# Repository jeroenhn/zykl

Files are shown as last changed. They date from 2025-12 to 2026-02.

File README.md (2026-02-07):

# ReZyklus Project

## A clone of the Zyklus MPS-1

The **ReZyklus Project** is an open-source effort to recreate the original **Zyklus MPS-1**.

This repository contains everything required to build your own Zyklus MPS-1 clone, aptly named 'ReZyklus', including hardware design files, panel layouts, and supporting documentation.

See my blog for some more info on the project:
https://www.zyklus-mps.com

There is a Discord server you can join specifically for this project:
https://discord.gg/zFuuCRRDz4

This is also the place where we think and talk about a succesor, the V2 which is mainly carried by David Perbal and will be a system based on the Teensy platform most likely. 

So what is the Zyklus MPS-1? 
A Midi Performance System. It's more than just a sequencer, it's kinda like an 80's version of a launchpad. 
There's really no better way to understand than to have one of the original developers show it to you, so check out Pete Kellocks video demo's of the Zyklus:
https://zyklus-mps.com/videos

Shout out to the team:

Paul McMurray (Technical genius who did most of the actual cloning work)

Marcel Donné (Tester/builder who build one of the first clones)

David Perbal (Another tester/builder who build two of 'm and is carrying the V2 project for the succesor of the ReZyklus - a Teensy based modern implementation)

Panu Talus (Zyklus enthausiast who for years has accumulated all sorts of historical information on the various units. Owner of an original)

And I'm Jeroen (Vangelis gear nut, founder of this project, also owns 2 originals and is restoring Vangelis orignal 'Direct' system).

---

## What’s in this repository

- **Bill of Materials (BOM)**  
  Detailed BOM spreadsheets provide a complete shopping list for the build.

- **PCB & Panel Design Files**  
  All PCB designs and front-panel files are provided.  
  The boards and panels were manufactured using **JLCPCB**, noting that their minimum order quantity is typically **5 units per board or panel**.

- **Case Parts**  
  Some enclosure components are **3D-printed**.  
  The required STL files are included in the repository.

- **Aluminium Dials**  
  Custom aluminium dials were also produced through **JLCPCB**, a working stepfile is included. The Case Parts also contain a file for a 3d printed version. 
  The alu dials need the threads tapped for M4 grub screws. 
  
- **Resource Links**  

  To come: links to various shops for parts, such as the PB86 type switches etc. 

---

## Firmware / OS Status

The original Zyklus operating system is still being worked on. Once ready for publication, it will be added here. The codebase is z80 Assembly and written in a very specific, old assembler which you'll need to compile and link. 

In the meantime, prebuilt EPROM binary files are provided, allowing you to build a fully functional Zyklus clone today while development continues.

---

## Credits & Acknowledgements

### Original Zyklus MPS-1 (1986)

The original Zyklus MPS-1 was created in 1986 by:

- Bill Marshall  
- Pete Kellock  
- Graham Mair  

Bill Marshall and Pete Kellock have generously given their blessing for this clone project to be released as open source.

---

### ReZyklus Project — Primary Contribution

It cannot be overstated that the vast majority of the work on this project has been carried out by Paul McMurray.

This includes, but is not limited to:

- KiCad schematics and PCB layouts  
- Panel designs & lauouts 
- 3D-printed parts  
- Electronics debugging  

Without Paul’s expertise, dedication, and deep understanding of both the original and modern electronics, this project simply would not exist.

Paul McMurray is the MVP of this project and instrumental in helping restoring Direct as well.

---

## Disclaimer

This project is a community-driven, non-commercial recreation intended for educational, historical, and personal use.  
All trademarks and original design concepts remain the property of their respective owners.

## License & Disclaimer

### License

This project is open source and open hardware.

* **Software (firmware, tools, scripts, source code):**
  Licensed under the **GNU General Public License version 3 (GPLv3)** or later.
  You are free to use, modify, and redistribute this software under the terms of the GPL, provided that any distributed modifications remain under the same license.

* **Hardware (schematics, PCB layouts, Gerbers, BOM, and related design files):**
  Licensed under an open hardware copyleft license
  (either **CERN Open Hardware License Version 2 – Strongly Reciprocal (CERN-OHL-S)** *or* **TAPR Open Hardware License**).
  You may use, study, modify, and manufacture hardware based on these designs, provided that any distributed modifications or derivative works are made available under the same license.

The intent of this licensing is to ensure that improvements to this project remain available to the community and cannot be taken proprietary.

THIS PROJECT IS PROVIDED “AS IS”, WITHOUT WARRANTY OF ANY KIND, EXPRESS OR IMPLIED, INCLUDING BUT NOT LIMITED TO MERCHANTABILITY, FITNESS FOR A PARTICULAR PURPOSE, AND NONINFRINGEMENT.

The authors and contributors are not liable for any direct, indirect, incidental, or consequential damages arising from the use, modification, manufacture, or distribution of this hardware or software.

This project is intended for educational, experimental, and research purposes. Use in safety-critical systems (including but not limited to medical devices, life-support systems, or any system where failure could cause injury or death) is expressly discouraged and done entirely at your own risk.

By using, modifying, or manufacturing from this project, you agree that all responsibility for compliance with local laws, regulations, certifications, and safety requirements rests solely with you.

---

### Commercial Use

Commercial use is permitted **only under the terms of the applicable licenses**. Any distributed modifications, derivatives, or products based on this project must remain open and must provide access to corresponding source code and hardware design files under the same license terms.

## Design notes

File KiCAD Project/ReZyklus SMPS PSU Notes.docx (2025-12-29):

ReZyklus SMPS PSU - 01/01/2024 v1.0

This power supply for the ReZyklus is based on a XPower LCW15 Series Switched Mode Power Supply unit which outputs 5V at up to 3 Amps; this output is fed into a DC-DC adjustable boost converter module set to output 5.6V.

The SMPS module can accept a wide range of line voltages between 85 – 305 VAC and the 5V output is adjustable by ±10%. The datasheet can be found here:

https://www.xppower.com/product/LCW15-Series

For this PCB, the input voltage is on CON201 which is a 6-pin Molex KK396 connector. This is wired to be compatible with the original Zyklus PSU. The original unit has a line voltage selector switch, but this SMPS will automatically adjust to a wide range of input voltages, so should operate independently of the how the switch is set. The pinout for input connector is shown below:

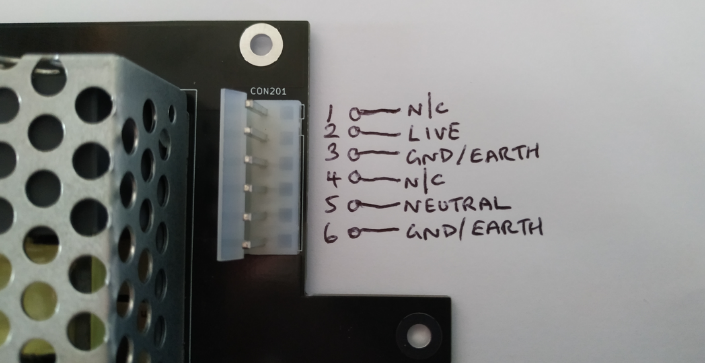
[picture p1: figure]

The output voltages are available on connectors CON202 and CON203 which are both 4-pin Molex KK396 connectors; both have the same pinout with +5V, +5.6V (5V6) and 0V (Gnd); one pin on each connector is unused. The pinout for the output connectors is shown on the PCB.

Fuse

There is a 2A fuse on the PCB for the 5V output of the SMPS module (the 5.6V rail is tapped off the 5V line so is also protected by this fuse); this can be replaced with a T2A fuse (time-lag). The line input should also be protected by a fuse (not on this PCB) and a T1A is recommended; note that the SMPS module has a high inrush current on powering on, so a time-lag fuse is required.

Important - Calibration

Before connecting the unit to a ReZyklus board, check the 5V line with a multimeter and, if required, adjust the white trim pot on the SMPS module (see the Vadjust marking on the PCB) to get this close to (but not below) 5V. After doing this, check the +5.6V line and adjust the blue multi-turn trim pot to get this as close to (but not below) 5.6V.

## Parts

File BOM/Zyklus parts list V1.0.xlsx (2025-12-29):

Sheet: Shopping List
IC's |  |  | Resistors |  |  | Capacitors |  | Diodes
Z80a |  |  | 330 Ohms 5% | 2 |  | 220uf / 16v | 2 | 1N4001 | 23
z80a sio-2 | 2x |  | 220 Ohms 5% | 14 |  | 100uf / 6.3v | 1 | oA47 | 3
z80a ctc |  |  | 1k Ohms 5% | 7 |  | 1u/10/100 | 1 | 1N4148 | 42
z80a pio |  |  | 680 Ohms 5% | 1 |  | 1000pF | 3 | 1N5339b | 1
27c128 | 2x |  | 27k Ohms 5% | 3 |  | 220nK63 | 1 | 1N5339 | 1
27c64 |  |  | 3.3k Ohms 5% | 2 |  | 100pF | 1 | 1N5401 | 4
HM6264LP-15 | 5x |  | 39k Ohms 5% | 2 |  | 10uf / 50v | 2
2730 | 2x | (one unused) | 100 Ohms 5% | 3 |  | 1u0 / 16v | 1
tl062cp | 2x |  | 22k Ohms 5% | 3 |  | 10,000pF | 26
7660 |  |  | 470 Ohms 5% | 3 |  | 0.047 uF | 16
74ls138n | 4x |  | 4.7k Ohms 5% | 32 |  | 10n | 11
74ls32n | 2x |  | 10k Ohms 5% | 3 |  | 220u 16v | 1
74ls74an | 5x |  | 56k Ohms 5% | 1 |  | 4700u 16V | 3
74ls393n |  |  | 2.2k Ohms 1% | 1 |  | 47n | 2
74ls244 | 7x |  | 270 Ohms 5% | 31 |  | 1u 16V | 1
74ls02n | 2x |  | 33 Ohms 5% 2W | 1
74ls04n |  |  | 560 Ohms 5% | 1
74ls245 |  |  | 33k Ohms 5% | 2
74ls123n |  |  | 220k | 1
74ls21n
74s74an | 2x
74ls00n
74ls374n | 5x
Connectors |  |  | Misc Components
26 way IDC | 2 |  | Battery | 2
10 way Molex | 3 |  | Crystal 4mhz | 1
34 Way Molex | 2 |  | TS 1N6267 | 2
4way molex | 3 |  | RV 10K | 1 | Optional
6way Molex | 1 |  | RV 500r | 1 | Optional
 |  |  | Alps LA226 | 1
Jack ports | 8 |  | Buzzer | 1
Midi ports | 5 |  | Red LED | 1
Power socket | 1 |  | Switch W/o Led | 8 | Black
 |  |  | Switch W led | 12 | Blue
 |  |  | Switch W led | 19 | Grey
 |  |  | Switch W/o Led | 1 | Grey
 |  |  | TS201 / 250V | 1
 |  |  | Regulatr L78S05 | 1
 |  |  | F201 Fuse 2A | 1
 |  |  | Transformer | 1
 |  |  | Outside Fuse | 1
 |  |  | Voltage Selector | 1

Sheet: IC
Mainboard |  | Switchboard |  | PS Board
Z Number |  | Z Number |  | Z Number
z1 | z80a cpu | z101 | 74ls138n
z2 | z80a sio-2 | z102 | 74ls138n
z3 | z80a sio-2 | z103 | 74ls74an
z4 | z80a ctc | z104 | 74ls374n
z5 | z80a pio | z105 | 74ls374n
z6 | rom | z106 | 74ls374n
z7 | rom | z107 | 74ls374n
z8 | rom | z108 | 74ls244
z9 | HM6264LP-15 | z109 | 74ls244
z10 | HM6264LP-15 | z110 | 74ls02n
z11 | HM6264LP-15 | z111 | 74ls374n
z12 | HM6264LP-15 | z112
z13 | HM6264LP-15 | z113
z14 | 2730 | z114
z15 | tl062cp | z115
z16 | tl062cp | z116
z17 | 7660 | z117
z18 | 74ls138n
z19 | 74ls138n
z20 | 74ls32n
z21 | 74ls74an
z22 | 74ls74an
z23 | 74ls74an
z24 | 74ls393n
z25 | 74ls244
z26 | 74ls244
z27 | 74ls244
z28 | 74ls244
z29 | 74ls244
z30 | 74ls32n
z31 | 74ls02n
z32 | 74ls04n
z33 | 74ls245
z34 | 74ls123n
z35 | 74ls21n
z36 | 74s74an
z37 | 74ls00n
z38 | 2730

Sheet: Resistors
Mainboard |  | Switchboard |  |  | PS Board
R Number | Value | R Number | Value |  | R Number | Value
r1 | 330 Ohms 5% | r101 | 270 Ohms 5% |  | R201 | 1k Ohms 5%
r2 | 330 Ohms 5% | r102 | 270 Ohms 5% |  | R202 | 33 Ohms 5% 2W
r3 | 33k Ohms 5% | r103 | 270 Ohms 5%
r4 | 560 Ohms 5% | r104 | 270 Ohms 5%
r5 | 220 Ohms 5% | r105 | 270 Ohms 5%
r6 | 220 Ohms 5% | r106 | 270 Ohms 5%
r7 | 220 Ohms 5% | r107 | 270 Ohms 5%
r8 | 220 Ohms 5% | r108 | 270 Ohms 5%
r9 | 220 Ohms 5% | r109 | 270 Ohms 5%
r10 | 220 Ohms 5% | r110 | 270 Ohms 5%
r11 | 220 Ohms 5% | r111 | 270 Ohms 5%
r12 | 220 Ohms 5% | r112 | 270 Ohms 5%
r13 | 220 Ohms 5% | r113 | 270 Ohms 5%
r14 | 1k Ohms 5% | r114 | 270 Ohms 5%
r15 | 680 Ohms 5% | r115 | 270 Ohms 5%
r16 | 27k Ohms 5% | r116 | 270 Ohms 5%
r17 | 1k Ohms 5% | r117 | 270 Ohms 5%
r18 | 1k Ohms 5% | r118 | 270 Ohms 5%
r19 | 1k Ohms 5% | r119 | 270 Ohms 5%
r20 | 1k Ohms 5% | r120 | 270 Ohms 5%
r21 | 3.3k Ohms 5% | r121 | 270 Ohms 5%
r22 | 1k Ohms 5% | r122 | 270 Ohms 5%
r23 | 39k Ohms 5% | r123 | 270 Ohms 5%
r24 | 39k Ohms 5% | r124 | 270 Ohms 5%
r25 | 27k Ohms 5% | r125 | 270 Ohms 5%
r26 | 33k Ohms 5% | r126 | 270 Ohms 5%
r27 | 27k Ohms 5% | r127 | 270 Ohms 5%
r28 | 33k Ohms 5% | r128 | 270 Ohms 5%
r29 | 100 Ohms 5% | r129 | 4.7k Ohms 5%
r30 | 100 Ohms 5% | r130 | 4.7k Ohms 5%
r31 | 100 Ohms 5% | r131 | 4.7k Ohms 5%
r32 | 22k Ohms 5% | r132 | 4.7k Ohms 5%
r33 | 22k Ohms 5% | r133 | 4.7k Ohms 5%
r34 | 22k Ohms 5% | r134 | 4.7k Ohms 5%
r35 | 470 Ohms 5% | r135 | 4.7k Ohms 5%
r36 | 470 Ohms 5% | r136 | 4.7k Ohms 5%
r37 | 470 Ohms 5% | r137 | 4.7k Ohms 5%
r38 |  | r138 | 4.7k Ohms 5% | other side board
r39 | 4.7k Ohms 5% | r139 | 4.7k Ohms 5% | other side board
r40 | 4.7k Ohms 5% | r140 | - | unused
r41 | 4.7k Ohms 5% | r141 | 270 Ohms 5%
r42 | 4.7k Ohms 5% | r142 | 270 Ohms 5%
r43 | 4.7k Ohms 5% | r143
r44 | 4.7k Ohms 5% | r144 | 270 Ohms 5%
r45 | 4.7k Ohms 5%
r46 | 4.7k Ohms 5%
r47 | 4.7k Ohms 5%
r48 | 4.7k Ohms 5%
r49 | 4.7k Ohms 5%
r50 | 4.7k Ohms 5%
r51 | 4.7k Ohms 5%
r52 | 4.7k Ohms 5%
r53 | 4.7k Ohms 5%
r54 | 4.7k Ohms 5%
r55 | 4.7k Ohms 5%
r56 | 4.7k Ohms 5%
r57 | 4.7k Ohms 5%
r58 | 4.7k Ohms 5%
r59 | 4.7k Ohms 5%
r60 | 10k Ohms 5%
r61 | 220k Ohms 5%
r62 | 56k Ohms 5%
r63 | 2.2k Ohms 1%
r64 | 10k Ohms 1%
r65 | 220 Ohms 5%
r66 | 220 Ohms 5%
r67 | 220 Ohms 5%
r68 | 220 Ohms 5%
r69 | 220 Ohms 5%

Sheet: Diodes
Mainboard |  | Switchboard |  | PS Board
D Number | Value | D Number | Value | D Number | Value
D1 | 1N4001 | d101 | 1N4148 | D201 | 1N5401
D2 | 1N4001 | d102 | 1N4148 | D202 | 1N5401
D3 | oA47 | d103 | 1N4148 | D203 | 1N5401
D4 | 1N4001 | d104 | 1N4148 | D204 | 1N5401
D5 | 1N4001 | d105 | 1N4148 | D205 | 1n4001
D6 | 1N4001 | d106 | 1N4148
D7 | 1N4001 | d107 | 1N4148 | Zen 201 | 1N5339
D8 | 1N4001 | d108 | 1N4148
D9 | 1N4001 | d109 | 1N4148
D10 | 1N4001 | d110 | 1N4148
D11 | 1N4001 | d111 | 1N4148
D12 | 1N4001 | d112 | 1N4148
D13 | 1N4001 | d113 | 1N4148
D14 | 1N4001 | d114 | 1N4148
D15 | 1N4001 | d115 | 1N4148
D16 | 1N4001 | d116 | 1N4148
D17 | 1N4001 | d117 | 1N4148
D18 | 1N4001 | d118 | 1N4148
D19 | 1N4001 | d119 | 1N4148
D20 | 1N4001 | d120 | 1N4148
D21 | 1N4001 | d121 | 1N4148
D22 | oA47 | d122 | 1N4148
D23 | oA47 | d123 | 1N4148
D24 | 1N4148 | d124 | 1N4148
D25 | 1N4148 | d125 | 1N4148
D26 | 1N4148 | d126 | 1N4148
D27 | 1N4001 | d127 | 1N4148
D28 | 1N4001 | d128 | 1N4148
D29 | 1N4001 | d129 | 1N4148
D30 |  | d130 | 1N4148
D31 |  | d131 | 1N4148
D32 |  | d132 | 1N4148
D33 |  | d133 | 1N4148
D34 |  | d134 | 1N4148
D35 |  | d135 | 1N4148
D36 |  | d136 | 1N4148
D37 |  | d137 | 1N4148
D38 |  | d138 | 1N4148
D39 |  | d139 | 1N4148
D40 |  | zen 101 | 1N5339b
D41
D42
D43
D44
D45
D46
D47
D48

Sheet: Capacitors
Mainboard |  |  | Switchboard |  |  | PS Board
C Number | Value |  | C Number | Value |  | C Number | Value
c1 | 220uf / 16v | EL | c101 | 10n |  | C201 | 4700u 16V
c2 | 220uf / 16v | EL | c102 | 10n |  | C202 | 4700u 16V
c3 | 100uf / 6.3v | EL | c103 | 10n |  | C203 | 4700u 16V
c4 | 1u/10/100 | Philips | c104 | 10n |  | C204 | 47n
c5 | 1000pF |  | c105 | 10n |  | C205 | 47n
c6 | 220nK63 |  | c106 | 10n |  | C206 | 1u 16V
c7 | 1000pF |  | c107 | 10n
c8 | 1000pF |  | c108 | 10n
c9 | 100pF |  | c109 | 10n
c10 | 10uf / 50v | EL | c110 | 10n
c11 | 10uf / 50v | EL | c111 | 220u 16v | el
c12 | 1u0 / 16v | Tantalum | c112
c13 | 10,000pF | Cer | c113 | 10n
c14 | 10,000pF | Cer
c15 | 10,000pF | Cer
c16 | 10,000pF | Cer
c17 | 10,000pF | Cer
c18 | 10,000pF | Cer
c19 | 10,000pF | Cer
c20 | 10,000pF | Cer
c21 | 10,000pF | Cer
c22 | 10,000pF | Cer
c23 | 10,000pF | Cer
c24 | 10,000pF | Cer
c25 | 10,000pF | Cer
c26 | 10,000pF | Cer
c27 | 10,000pF | Cer
c28 | 10,000pF | Cer
c29 | 10,000pF | Cer
c30 | 10,000pF | Cer
c31 | 10,000pF | Cer
c32 | 10,000pF | Cer
c33 | 10,000pF | Cer
c34 | 10,000pF | Cer
c35 | 10,000pF | Cer
c36 | 0.047 uF | Cer
c37 | 0.047 uF | Cer
c38 | 0.047 uF | Cer
c39 | 0.047 uF | Cer
c40 | 0.047 uF | Cer
c41 | 0.047 uF | Cer
c42 | 0.047 uF | Cer
c43 | 0.047 uF | Cer
c44 | 0.047 uF | Cer
c45 | 0.047 uF | Cer
c46 | 0.047 uF | Cer
c47 | 0.047 uF | Cer
c48 | 0.047 uF | Cer
c49 | 0.047 uF | Cer
c50 | 0.047 uF | Cer
c51 | 0.047 uF | Cer
c52 | 10,000pF | Cer
c53 | 10,000pF | Cer
c54 | 10,000pF | Cer

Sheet: Misc Components
Mainboard |  | Switchboard |  |  | PS Board
C Number | Value | C Number | Value |  | C Number | Value
B1 | Battery | enc 101 | Alps LA226 Rotary encode |  | TS201 | 250V
B2 | Battery | bz 101 | Buzzer |  | Reg201 | L78S05
Crystal | 4Mhz | Display | OLED 40x2 |  | F201 | Fuse 2A
TS1 | 1N6267 | sw101 | Switch W Led | Gray | Xfomrer | Avel Lindberg OB 30/9
TS2 | 1N6267 | sw102 | Switch W Led | Gray
RV1 | 10K | sw103 | Switch W Led | Gray
RV2 | 500R | sw104 | Switch W Led | Gray
 |  | sw105 | Switch w/o Led | black
 |  | sw106 | Switch w/o Led | black
 |  | sw107 | Switch w/o Led | black
 |  | sw108 | Switch w/o Led | black
 |  | sw109 | Switch w/o Led | black
 |  | sw110 | Switch w/o Led | black
 |  | sw111 | Switch w/o Led | black
 |  | sw112 | Switch w/o Led | black
 |  | sw113 | Switch W Led | Gray
 |  | sw114 | Switch W Led | Gray
 |  | sw115 | Switch W Led | Gray
 |  | sw116 | Switch W Led | Gray
 |  | sw117 | Switch W Led | Gray
 |  | sw118 | Switch W Led | Gray
 |  | sw119 | Switch W Led | Gray
 |  | sw120 | Switch W Led | Gray
 |  | sw121 | Switch W Led | Gray
 |  | sw122 | Switch W Led | Gray
 |  | sw123 | Switch W Led | Gray
 |  | sw124 | Switch W Led | Gray
 |  | sw125 | Switch w/o Led | Gray
 |  | sw126 | Switch W Led | Blue
 |  | sw127 | Switch W Led | Blue
 |  | sw128 | Switch W Led | Blue
 |  | sw129 | Switch W Led | Blue
 |  | sw130 | Switch W Led | Blue
 |  | sw131 | Switch W Led | Blue
 |  | sw132 | Switch W Led | Blue
 |  | sw133 | Switch W Led | Blue
 |  | sw134 | Switch W Led | Blue
 |  | sw135 | Switch W Led | Blue
 |  | sw136 | Switch W Led | Blue
 |  | sw137 | Switch W Led | Blue
 |  | sw138 | Switch W Led | Gray
 |  | sw139 | Switch W Led | Gray
 |  | sw140 | Switch W Led | Gray
 |  | Led 101 | LED Red

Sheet: Connectors
Mainboard |  |  | Switchboard |  | PS Board
C Number | Value |  | C Number | Value | C Number | Value
P1 | 26 way IDC | To switchboard | p101 | 26 way idc | S203 | 4 way Molex
P2 |  |  | p102 | 4way molex | S201 | 6way Molex
P3 | 4 way Molex | Power
P4 | 10 way Molex | To Jack ports
P5 | 34 Way Molex | To Cardridge
P6 | 10 way Molex | To Midi
P7 | 10 way Molex | To Midi

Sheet: Shopping links
Q | Z nr | Code | Item | Dip | Mainboard
5x | 9,10,11,12,13 | HM6264LP-15 | SRAM | 28 | Static ram 8Kx8 CMOS, PDIP-28 | These are also used in the memory module.
2x | 7,8 | 27128 | EProm | 28
1x | 6 | 2764 | EProm | 28
1x | 1 | Z80a | CPU | 40 | https://www.budgetronics.eu/nl/ics/microcontrollers/z80a-cpu/a-10778-10000143
1x |  | LA226 | Encoder |  | http://store.drawmer.com/index.php?route=product/product&product_id=147
1x | 33 | LS245 |  |  | https://www.budgetronics.eu/en/ics/7400-serie-ics/74ls-series/74ls245-octal-bus-transceiver-tri-state-dip20/a-20916-20000100
4x | 26,29 (28?),27 | LS244 |  | 20 | https://www.budgetronics.eu/en/ics/7400-serie-ics/74ls-series/74ls244-octal-buffer-line-driver/a-17957-20000100
1x | 19 | LS138 |  |  | https://www.budgetronics.eu/en/ics/7400-serie-ics/74ls-series/74ls138-3-line-to-8-line-decoders-demultiplexer/a-17870-20000100
4x | 21,36,22,23 | LS74 |  |  | https://www.budgetronics.eu/en/ics/7400-serie-ics/74ls-series/74ls74-dual-d-type-positive-edge-triggered-flip-flops/a-17832-20000100
1x | 18 | LS136 |  |  | https://www.budgetronics.eu/en/ics/7400-serie-ics/74ls-series/74ls136-quad-exclusive-or-gate-o-c/a-21210-20000100
2x | 18,20 | LS138 |  |  | https://www.budgetronics.eu/en/ics/7400-serie-ics/74ls-series/74ls138-3-line-to-8-line-decoders-demultiplexer/a-17870-20000100
2x | 2,3 | Z80 A SIO-2 IC • DIP-40 |  | 40
1x | 32 | LS04 |  |  | https://www.budgetronics.eu/en/ics/7400-serie-ics/74ls-series/74ls04-hex-inverter-dip14/a-18245-20000100
2x | 14,38 | 2730 |  |  | https://www.conrad.nl/nl/p/broadcom-optocoupler-fototransistor-hcpl-2730-000e-dip-8-darlington-dc-140137.html
1x | 24 | LS393 |  |  | https://www.budgetronics.eu/en/ics/7400-serie-ics/74ls-series/74ls393-dual-4-bit-binary-counter/a-20548-20000100
1x | 4 | Z80A CTC |  | 28 | https://www.futurlec.com/Z80Series/Z80A-CTCpr.shtml
1x | 5 | Z80A PIO |  | 40 | https://www.ebay.com/itm/Sharp-LH0081A-Z80A-PIO-Z80A-PIO-D-/152356548738
1x | 17 | 7660 |  |  | Z80 A SIO-2 IC • DIP-40
1x | 34 | LS123 |  |  | https://www.budgetronics.eu/en/ics/7400-serie-ics/74ls-series/74ls123-dual-retriggerable-one-shot/a-17833-20000100
Q | Z nr | Code | Item |  | Switch board
2x | z1, z2 | LS138 |  |  | https://www.budgetronics.eu/en/ics/7400-serie-ics/74ls-series/74ls138-3-line-to-8-line-decoders-demultiplexer/a-17870-20000100
1x | z3 | LS74 |  |  | https://www.budgetronics.eu/en/ics/7400-serie-ics/74ls-series/74ls74-dual-d-type-positive-edge-triggered-flip-flops/a-17832-20000100
5x | z4,z5,z6,z7,z11 | LS374 |  |  | https://www.budgetronics.eu/en/ics/7400-serie-ics/74ls-series/74ls374-octal-d-type-flip-flop-edge-triggered-tri-state/a-20886-20000100
2x | z8,z9 | LS244 |  | 20 | https://www.budgetronics.eu/en/ics/7400-serie-ics/74ls-series/74ls244-octal-buffer-line-driver/a-17957-20000100
1x | z10 | LS02 |  |  | https://vetco.net/products/nte74ls02-ic-ttl-nor-gate
Capacitors
3x | 4700 uF 16v | Elco
3x | 220uF 16V | Elco
2x | 10uF 50v | Elco
1x | 100uF 6.3V | Elco

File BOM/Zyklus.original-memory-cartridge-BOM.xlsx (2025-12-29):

Zyklus memory cartridge – BOM
Ref | Qty |  | Footprint
R305,R302,R304,R303,R301,R306 | 6 | 4.7M Ohms
Z301,Z302,Z303,Z304 | 4 | HM6264LP-15 | DIP-28_W15.24mm_Socket_LongPads
C303,C302,C304,C301 | 4 | 100nF poly
B302,B301 | 2 | 3V | Half-AA-Cell-Holder
C300 | 1 | 10uF 16V
D303,D302,D301 | 3 | 1N4001
S301 | 1 | 37w D-SUB Female | DSUB-37_Female_Horizontal_P2.77x2.84mm_EdgePinOffset7.70mm_Housed_MountingHolesOffset9.12mm
ZEN301 | 1 | Zener 5w 5v6 - do27

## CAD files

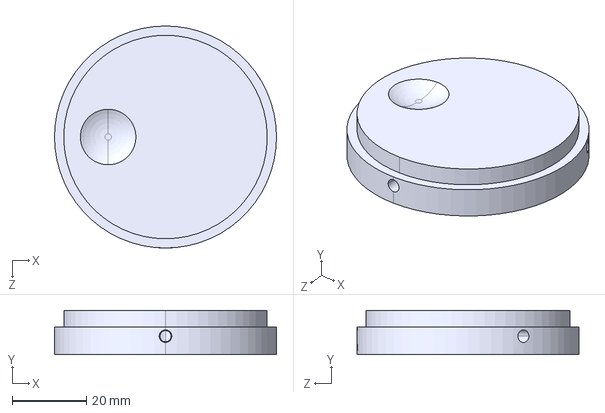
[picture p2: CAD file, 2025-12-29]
Alu Dial/Knob03.STEP
60.0 x 12.0 x 60.0 mm

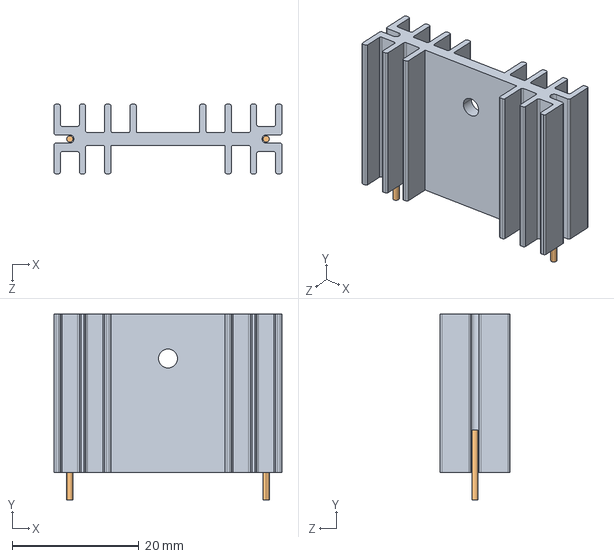
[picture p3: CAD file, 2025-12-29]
KiCAD Project/Additional Libraries/User Defined/DISIPADOR_TO220_5P.STEP
36.0 x 29.3 x 11.0 mm
disipador
pin x 2

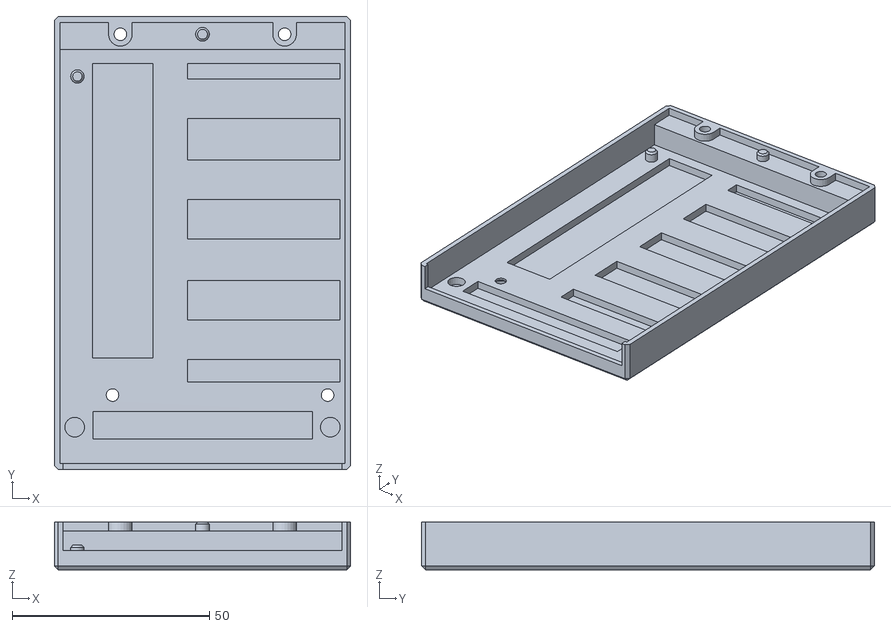
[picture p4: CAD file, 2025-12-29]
ReZyklus Cartridge Case/v1.0/ReZyklus Cartridge Case Bottom.stl
75.1 x 114.8 x 12.1

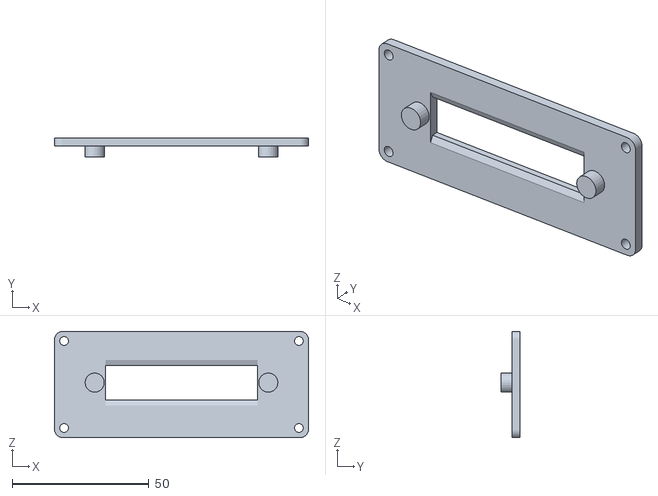
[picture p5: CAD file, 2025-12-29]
ReZyklus Case/ReZyklus DIY case (white panels)/STLs/ReZyklus DIY Case - Cartridge Connector Plate.stl
92.9 x 7.00 x 38.8

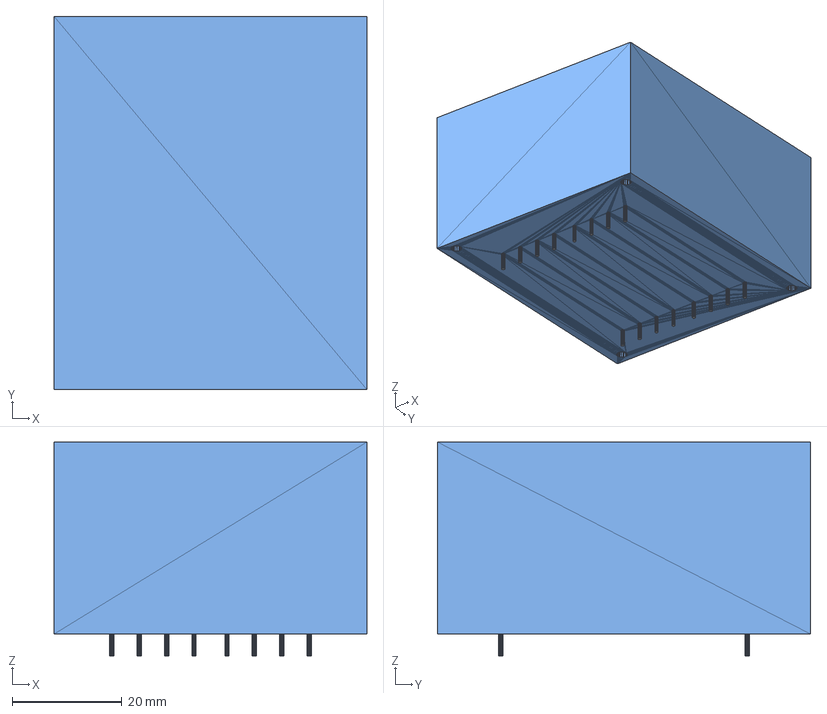
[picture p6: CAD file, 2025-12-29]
KiCAD Project/Additional Libraries/3D Models/Myrra 45xxx Transformer.stp
57.0 x 68.0 x 39.0 mm
pina
pinb
pinc
pind
pine
pinf
ping
pinh
pini
pinj
pink
pinl
pinm
pinn
pino
pinp

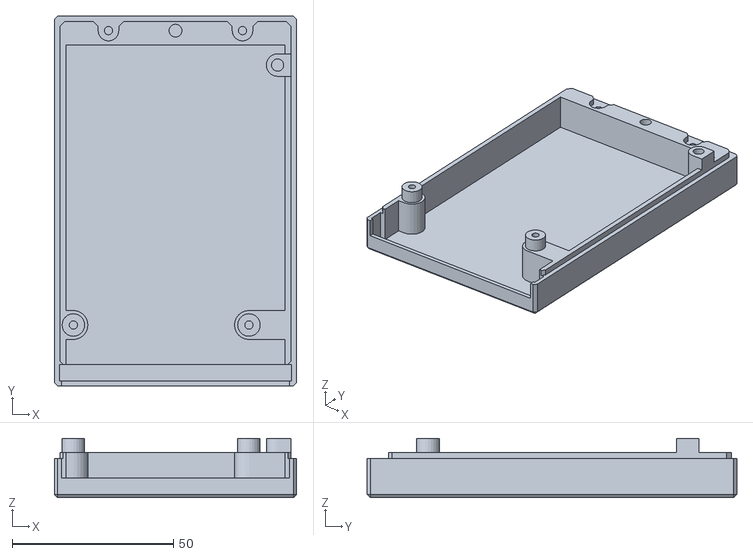
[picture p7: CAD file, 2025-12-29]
ReZyklus Cartridge Case/v1.0/ReZyklus Cartridge Case Top.stl
75.1 x 114.8 x 18.5

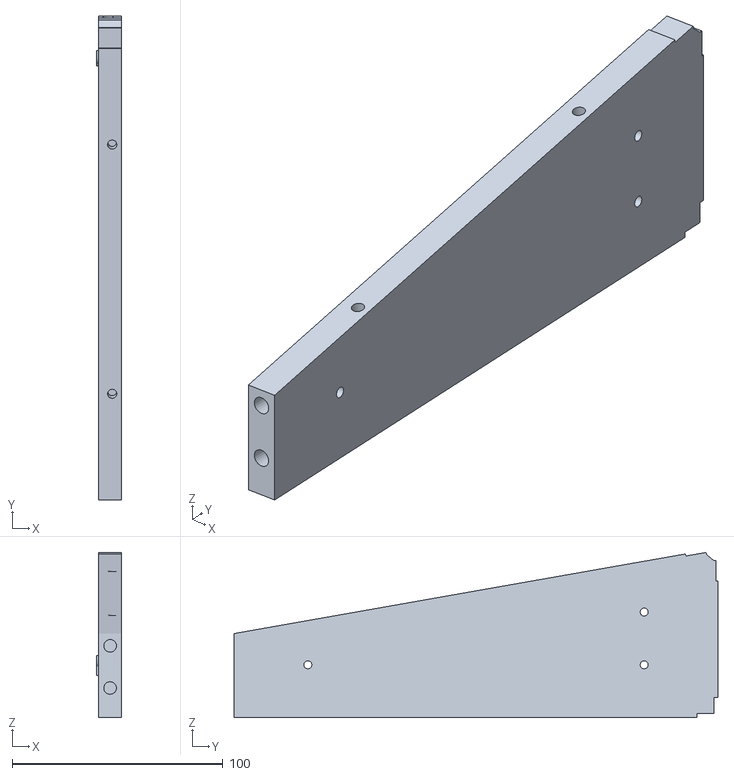
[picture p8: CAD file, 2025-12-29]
ReZyklus Case/ReZyklus DIY case (white panels)/STLs/ReZyklus DIY Case - Right Side.stl
12.1 x 229.5 x 78.3

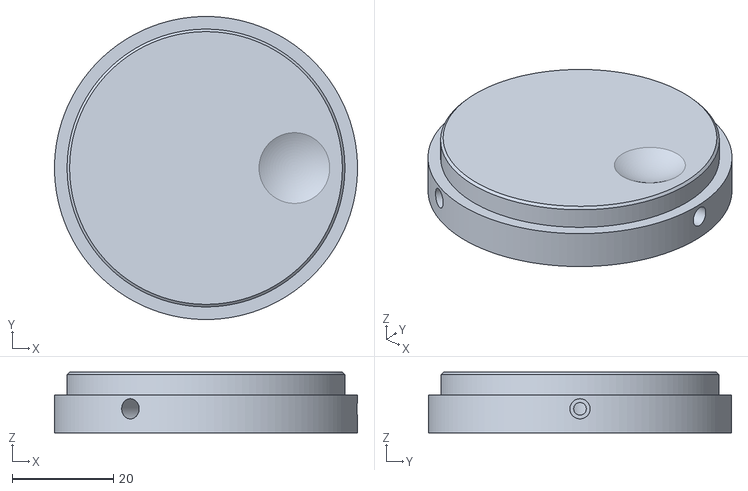
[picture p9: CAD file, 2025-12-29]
ReZyklus Case/ReZyklus DIY case (white panels)/STLs/ReZyklus DIY Case - Encoder Wheel.stl
60.0 x 60.0 x 12.0

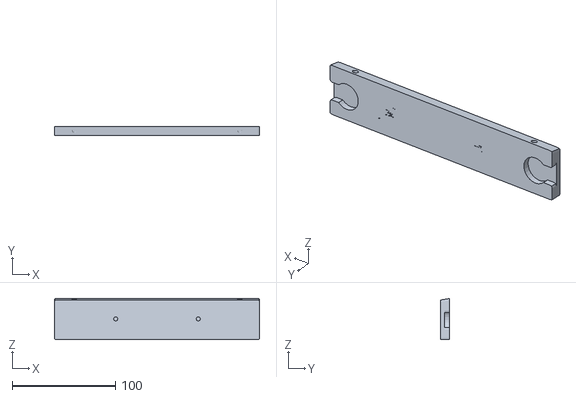
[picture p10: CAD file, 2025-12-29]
ReZyklus Case/ReZyklus DIY case (white panels)/STLs/ReZyklus DIY Case - Center Front.stl
198.6 x 9.00 x 39.8

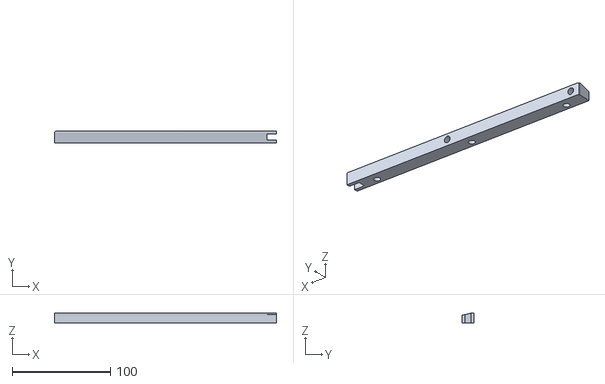
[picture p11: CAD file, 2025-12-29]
ReZyklus Case/ReZyklus DIY case (white panels)/STLs/ReZyklus DIY Case - Left Rear Mount.stl
225.5 x 12.5 x 10.5

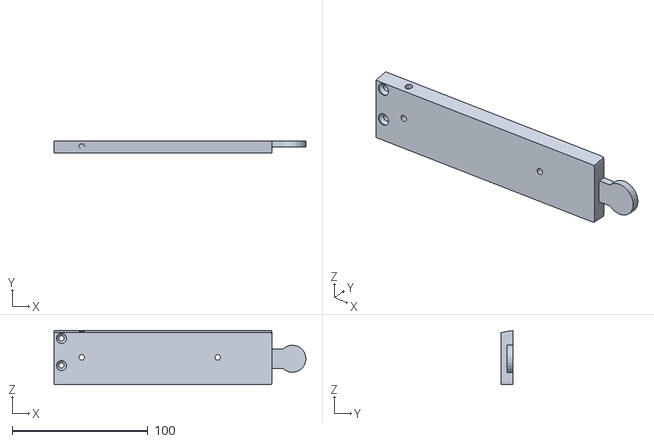
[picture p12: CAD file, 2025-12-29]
ReZyklus Case/ReZyklus DIY case (white panels)/STLs/ReZyklus DIY Case - Left Front.stl
185.4 x 9.00 x 39.8

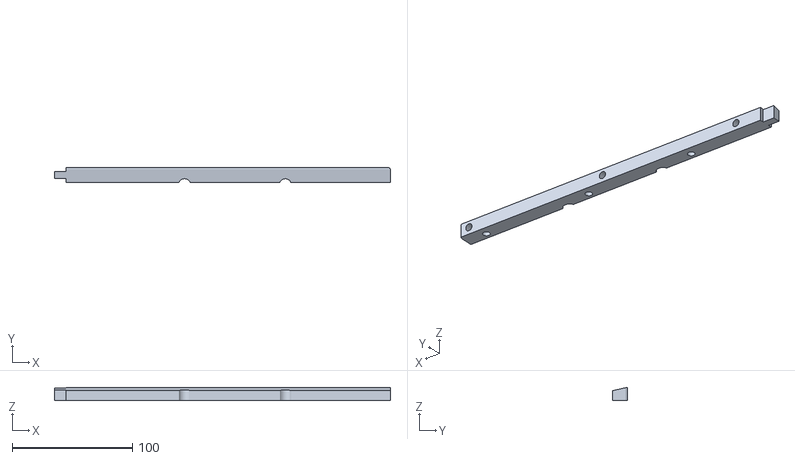
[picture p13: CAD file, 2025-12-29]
ReZyklus Case/ReZyklus DIY case (white panels)/STLs/ReZyklus DIY Case - Right Rear Mount.stl
279.5 x 12.5 x 10.5

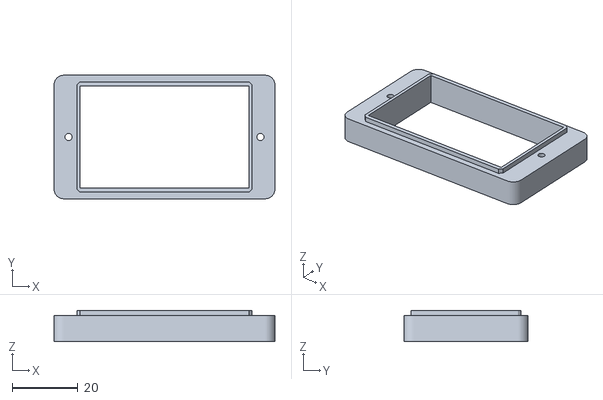
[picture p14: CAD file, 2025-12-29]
ReZyklus Case/ReZyklus DIY case (white panels)/STLs/ReZyklus DIY Case - Bulgin IEC Inlet Mount.stl
67.4 x 37.7 x 9.50

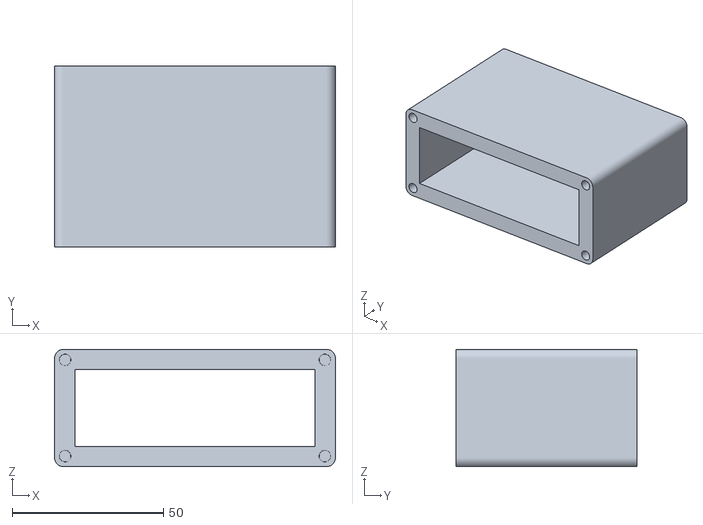
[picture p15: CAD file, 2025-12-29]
ReZyklus Case/ReZyklus DIY case (white panels)/STLs/ReZyklus DIY Case - Cartridge Slot.stl
92.9 x 60.0 x 38.8

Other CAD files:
ReZyklus Case/ReZyklus DIY case (white panels)/STLs/ReZyklus DIY Case - Left Side.stl
ReZyklus Case/ReZyklus DIY case (white panels)/STLs/ReZyklus DIY Case - Right Front.stl
KiCAD Project/Additional Libraries/3D Models/MC33270 Heatsink.stp
KiCAD Project/Additional Libraries/Molex KK 396 3D Models/026192051.stp
KiCAD Project/Additional Libraries/Molex KK 396 3D Models/026192031.stp
KiCAD Project/Additional Libraries/Molex KK 396 3D Models/026192041.stp
KiCAD Project/Additional Libraries/Molex KK 396 3D Models/026192061.stp
KiCAD Project/Additional Libraries/Molex KK 396 3D Models/026192071.stp
KiCAD Project/Additional Libraries/Molex KK 396 3D Models/026192081.stp
KiCAD Project/Additional Libraries/Molex KK 396 3D Models/026192091.stp
KiCAD Project/Additional Libraries/Molex KK 396 3D Models/026192101.stp
KiCAD Project/Additional Libraries/Molex KK 396 3D Models/026192111.stp
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

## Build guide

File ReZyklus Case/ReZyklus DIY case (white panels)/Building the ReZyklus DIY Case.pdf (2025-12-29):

Building the ReZyklus DIY Case

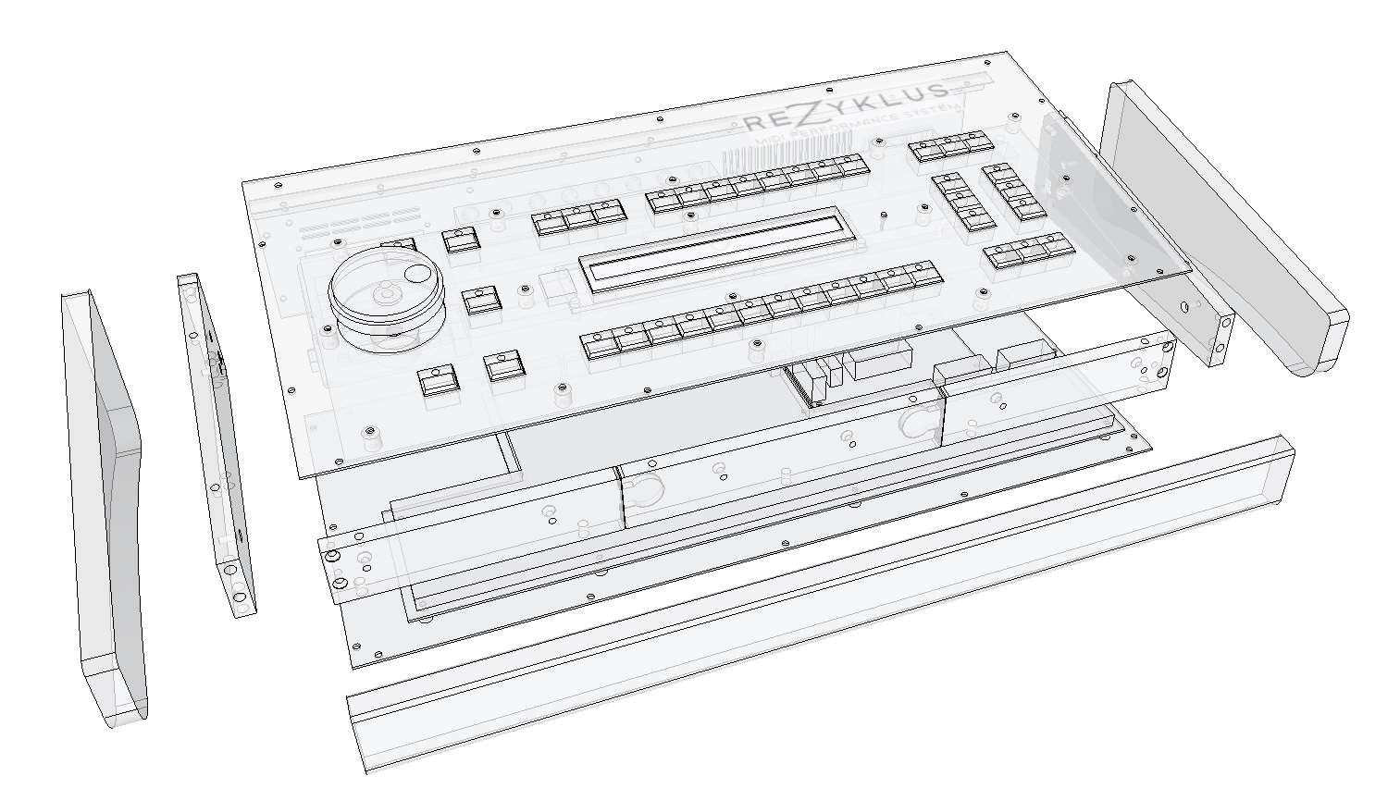
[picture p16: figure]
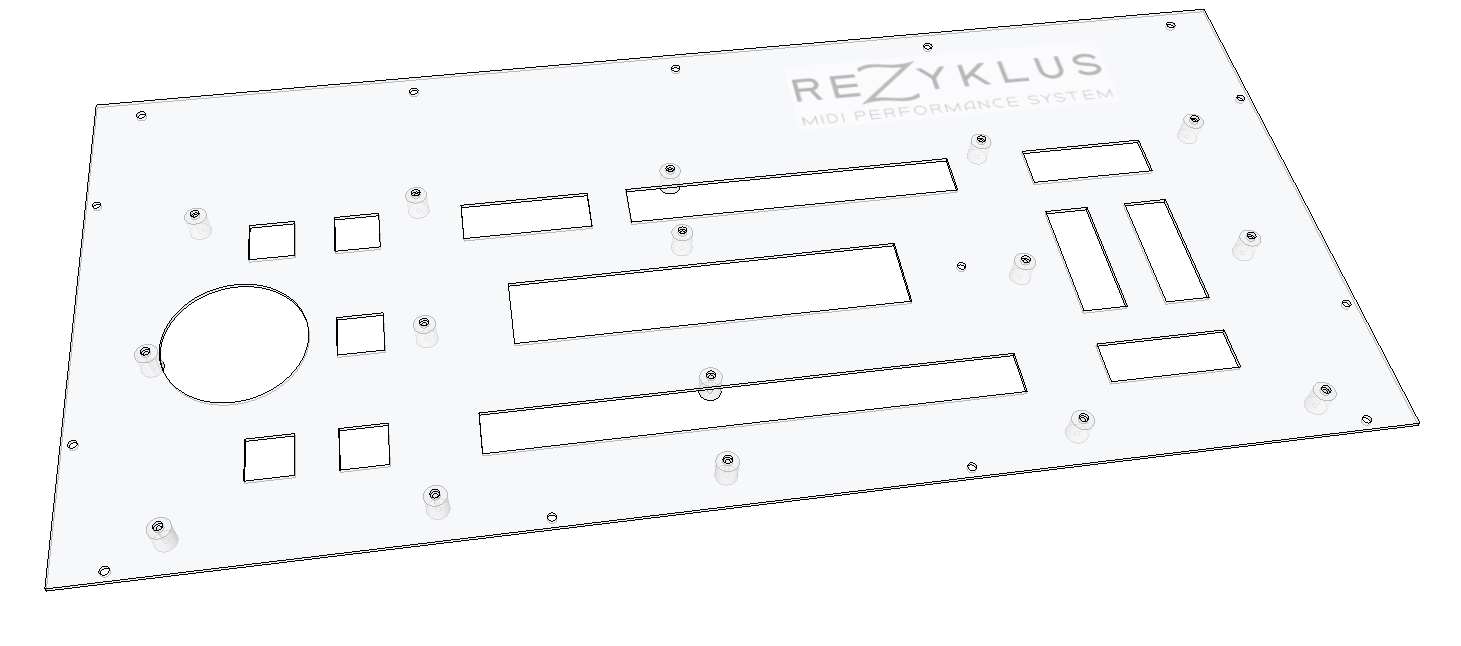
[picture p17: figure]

Building the ReZyklus DIY Case.docx | revision 0.3 | Page 1 of 10

The DIY case for the ReZyklus project is a hybrid of milled & printed aluminium panels (manufactured by JLCPCB), 3D Printed panels (for the sides, front and interconnecting supports) and optionally wooden side and front panels to dress over the 3D printed panels and sharp case edges.

Main Top Panel

The Panelboard PCB mounts to this using:
- 16x M3 10mm Hexagonal threaded spacers (this size leaves just enough clearance for the LCD)
- 16x M3 6mm button-head Hex bolts (recommended as these are visible on the top panel and smooth to the touch)
- 16x M3 5mm general purpose screws (to secure the PCB to the spacers)

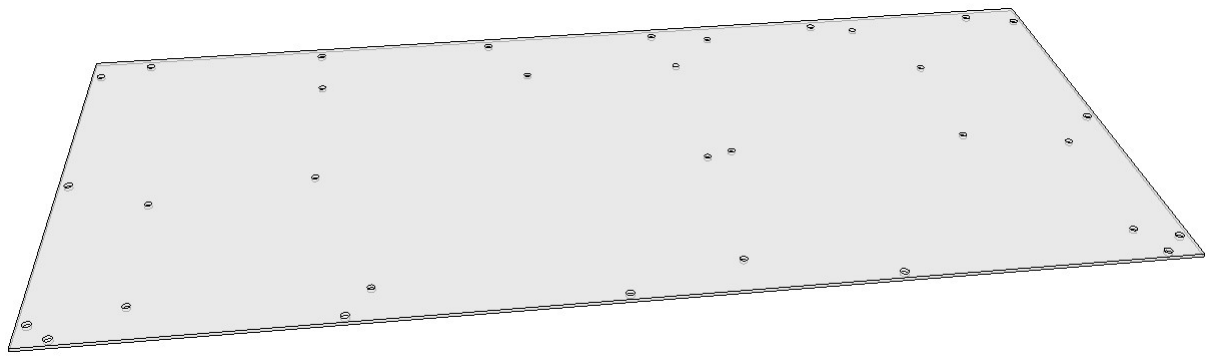
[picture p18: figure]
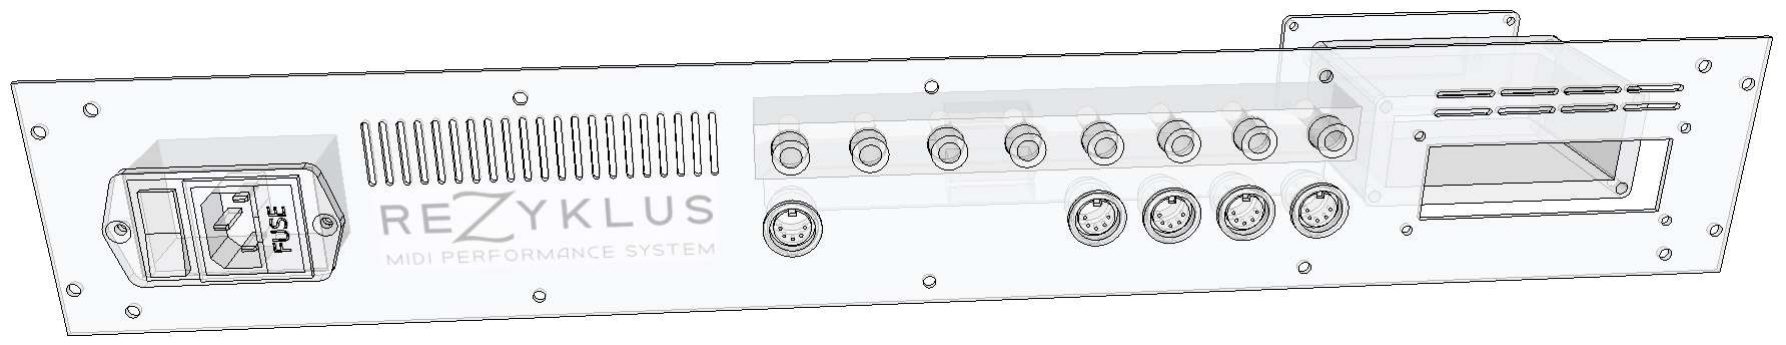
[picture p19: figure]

Building the ReZyklus DIY Case.docx | revision 0.3 | Page 2 of 10

Before fitting the PCB in place, the encoder and Jog Wheel have to be mounted so as to just clear the top of the PCB. Test fit the PCB in place with a couple of screws to check the alignment and if necessary, reposition the encoder pot (may need to file out the mounting hole in the PCB slightly) to get the Jog Wheel central in the panel cut-out.

Base Panel

The Mainboard PCB and PSU PCB mounts to this using:
- 11x M3 8mm Hexagonal threaded spacers for the main board (this size leaves just enough clearance for the underside of the Encoder when the case is closed)
- 5x M3 10mm Hexagonal threaded spacers for the PSU board (this allows it to clear the rear mounting strip on the case)
- 16x M3 6mm button-head Hex bolts (recommended as these are smooth to the touch and lowprofile on the underside of the case)
- 16x M3 5mm general purpose screws (to secure the PCBs to the spacers)

Rear Panel

The MIDI Jacks, Input Jacks, IEC Inlet and Cartridge Port attach to this panel using:
- 2x M3 15mm Countersunk bolts (+ nuts and washers) for mounting the IEC Inlet
- MIDI DIN Sockets – these are mounted to the panel first, before wiring and mounting them to the PCB, as they are mounted from the front of the panel
- Jack Sockets – these can be mounted after soldering to the PCB as they are mounted from the back of the panel
- Cartridge Port – this is a 3D printed part mounted to the case by 4x M3 8mm screws

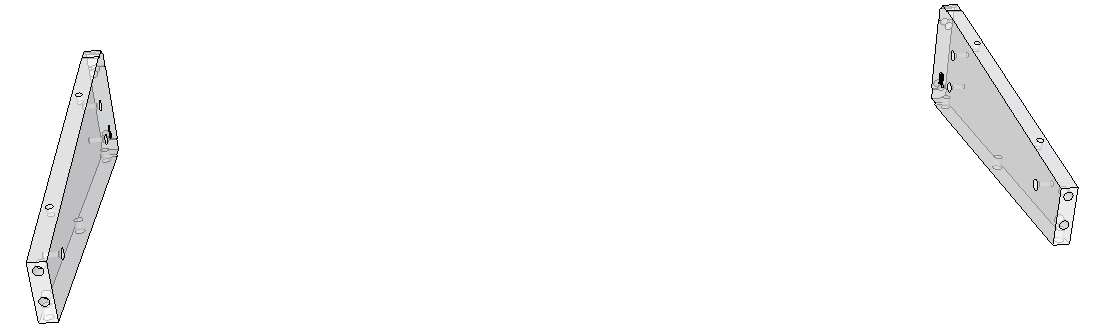
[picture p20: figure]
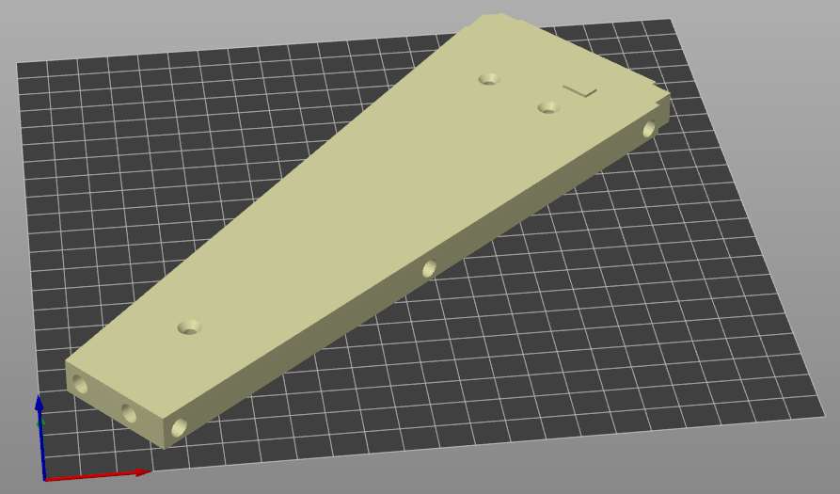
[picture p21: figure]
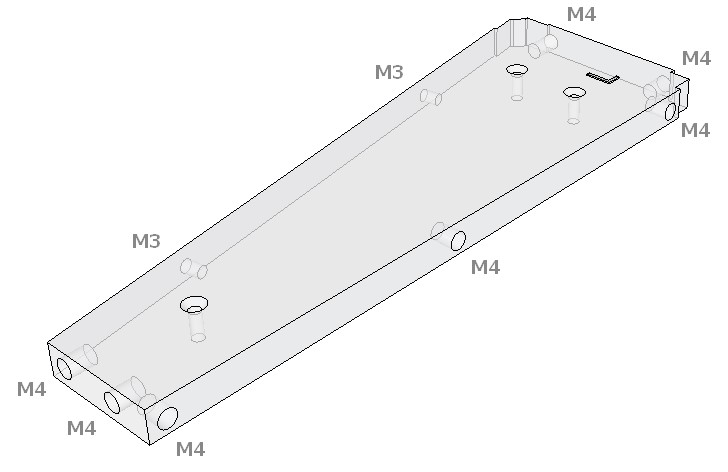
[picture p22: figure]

Building the ReZyklus DIY Case.docx | revision 0.3 | Page 3 of 10

3D Printed Case Parts
Side Panels

The 3D printed side panels form the main structural parts of the case and have been designed to give the top panel a 10° slope, down towards the front of the case. Each one will fit diagonally on a fairly common print bed size of 230mm x 230mm if printed diagonally:

The orientation should be with the raised letters “L” or “R” on the top surface, and the model needs no support material. Recommended Infill density should be somewhere around 10% Gyroid or 25% Cubic so that plenty of material is printed around the holes where the threaded inserts should be fitted after printing. The panel also includes three countersunk holes for screws to go through for mounting the wooden side panels.
Threaded inserts should be melted into place as per the diagram below (flipped accordingly for the righthand panel):

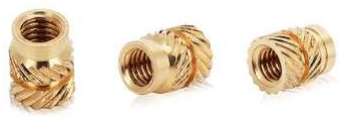
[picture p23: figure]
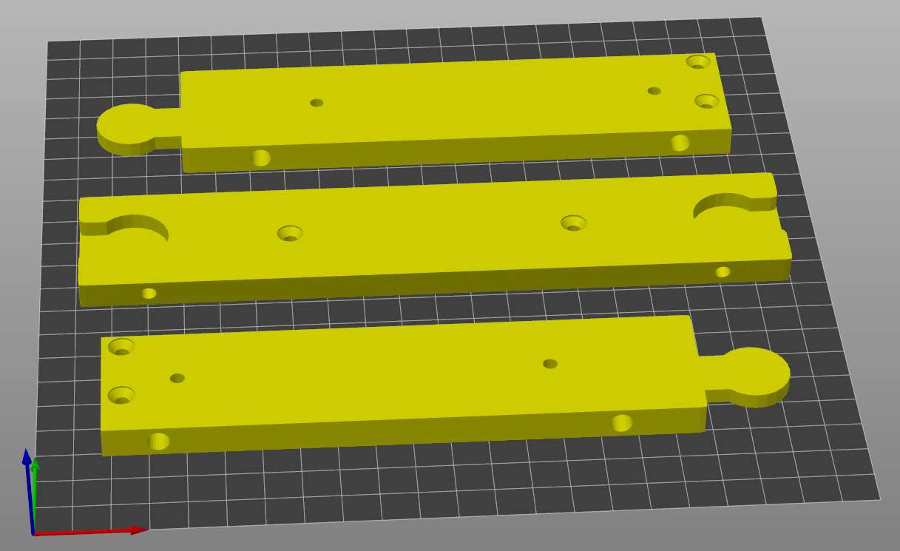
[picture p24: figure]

Building the ReZyklus DIY Case.docx | revision 0.3 | Page 4 of 10

A pair of side panels requires a total of:
- 4x M3 threaded insert
- 14x M4 threaded insert
- 6x countersunk wood screws (length dependent on the chosen thickness of wood used)
If available, the recommended inserts to use are the longer type with a smooth shaft at one end, as these help keep the insert centrally aligned as they are melted into place:

If using a soldering iron to melt the inserts into place, recommend using a conical tip and to set the temperature of the iron to around 220°C. As soon as the insert is in place, thread an M3 bolt into the insert and use it to adjust the inserts alignment and draw the heat out quickly.

Front Panels

The 3D printed front panels form part of the structural parts of the case and have been designed to match the top panel 10° slope. The panel is split into three pieces in order to fit on a standard print bed, however all three can be printed at once.
Note that the Left and Right sections should be printed with the tabs touching the print bed, but the center section oriented with the tab cut-outs on the top surface:

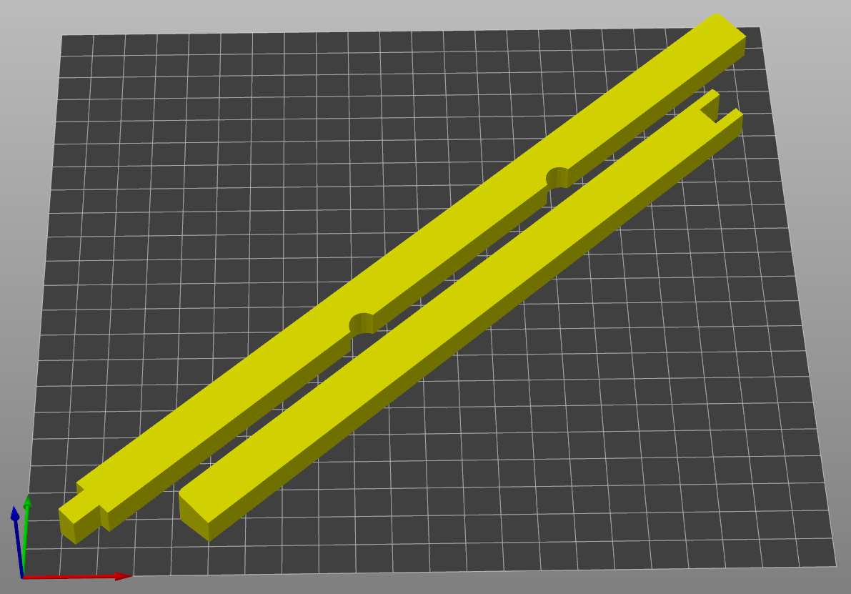
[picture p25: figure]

Building the ReZyklus DIY Case.docx | revision 0.3 | Page 5 of 10

The models need no support material and, as with the other parts, the recommended Infill density should be somewhere around 10% Gyroid or 25% Cubic so that plenty of material is printed around the holes where the threaded inserts should be fitted after printing.
The panels also include six countersunk holes for screws to go through for mounting the wooden front panel. There are also two countersunk holes at each end for securing the front panels to the side panels via 4x M4 12mm Countersunk bolts.
The tabs on the end sections are designed to be glued into place in the center section (an adhesive compatible with the chosen filament is recommended, but CA glue will usually suffice). When doing this, it is recommended to temporarily mount the panels to the base plate so as to ensure the correct spacing and alignment, then “wick” the CA glue around the tabs.
Threaded inserts should be melted into place as per the diagram below:

A set of three front panels requires a total of:
- 4x M3 threaded inserts
- 5x M4 threaded insert
- 4x M4 12mm Countersunk bolts
- 6x countersunk wood screws (length dependent on the chosen thickness of wood used)

Rear to Base Panel Mounting Strip

This part ensures the rear panel and base plate are mounted rigidly to each other. It is split into two sections that can be printed diagonally on a standard print bed:

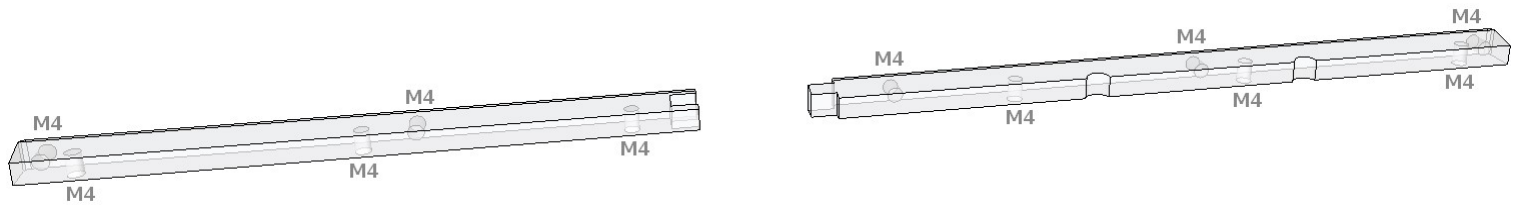
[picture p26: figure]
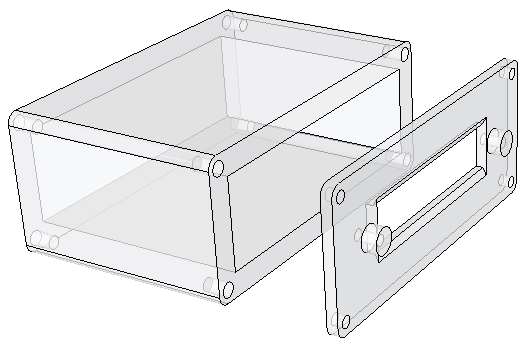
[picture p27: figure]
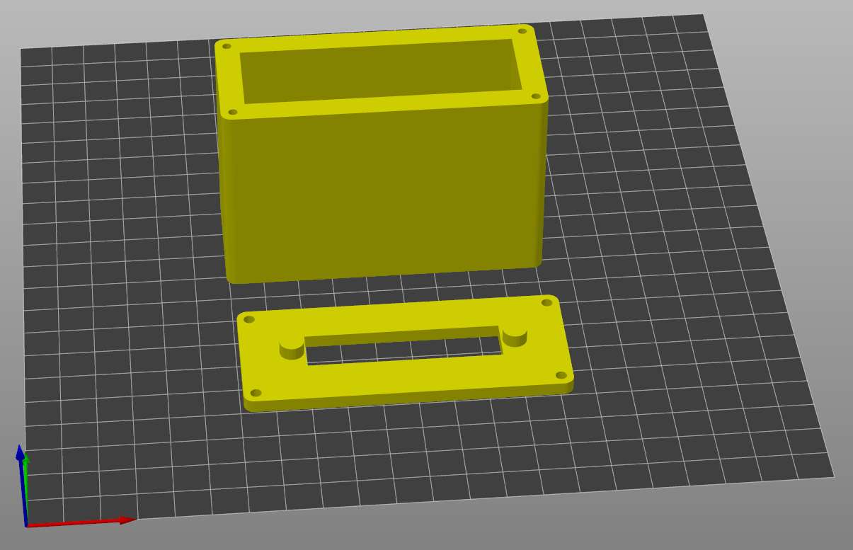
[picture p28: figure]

Building the ReZyklus DIY Case.docx | revision 0.3 | Page 6 of 10

The models should be printed with the insert holes oriented face down onto the build plate. The models need no support material, and the recommended Infill density should be somewhere around 10% Gyroid or 25% Cubic so that plenty of material is printed around the holes where the threaded inserts should be fitted after printing.
The set of two strips require a total of:
- 11x M4 threaded inserts
- 11x M4 6mm button-head Hex bolts (recommended as these are smooth to the touch and lowprofile on the case panels)
Threaded inserts should be melted into place as per the diagram below:

The center parts of the models are designed to fit into each other and can also be glued together if desired, although it is not necessary.

Cartridge Port

This consists of two part that screw together via M3 bolts and M3 threaded inserts:
- The sleeve to guide the cartridge into place
- The connector plate to mount the 37-way Male IDC connector into
Both models fit easily onto a standard build plate. The sleeve should be printed upright, and the connector plate printed flat to the bed:

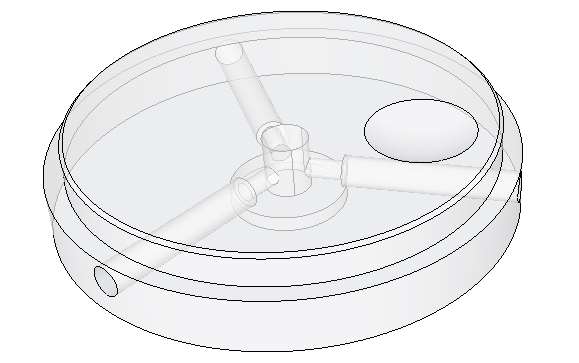
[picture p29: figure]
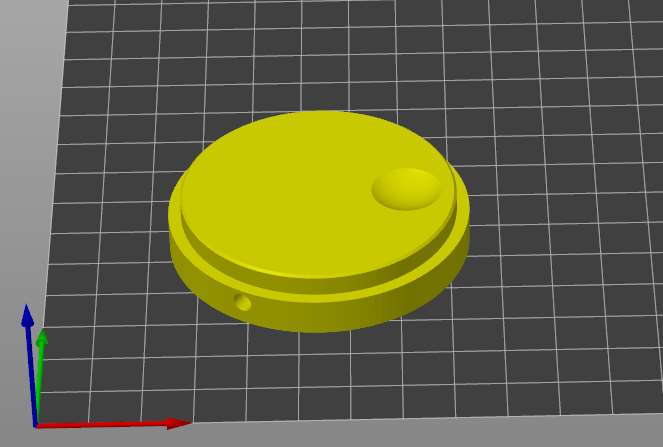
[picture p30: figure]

Building the ReZyklus DIY Case.docx | revision 0.3 | Page 7 of 10

The models need no support material, and the recommended Infill density should be somewhere around 10% Gyroid or 25% Cubic.
The two parts require:
- 8x M3 threaded inserts
- 8x M3 8mm self-tapping screws (4x to attach the connector plate to the sleeve, and 4x to mount the sleeve to the rear panel)
- 2x M3 6-10mm self-tapping screws to mount the connector to the plate; the length of these screws will depend on whether the connector is metal-bodied or plastic-bodied.
The connector should be mounted such that it is on the inside of cartridge port, rather than from the back. (It is easier to first mount the connector to the plate, then mount the whole assembly to the sleeve)

Encoder Jog Wheel

This part is modelled on the original Zyklus MPS aluminium wheel. It needs a little work after printing to drill through and tap the three grub-screw mounts. Print the part oriented as below:

Recommendation is a dense infill (e.g. 20% Gyroid or 50% Cubic), 2 perimeters and at least 4 layers to get a smooth finish on the top. Layer height should be at least 0.20mm, but if the “dimple” in the top is rough, try again with 0.16mm instead. The part will also need support on the base plate for the recessed center section underneath.
After printing, first remove the support material. Carefully drill the three grub screw channels with a 2mm drill bit, through to the center opening where the shaft goes in. The ends of these channels (nearest the center) will then need threading with an M3 tap, after which 3x M3 grub screws will need inserting; use at least 8mm screws to get good alignment and purchase on the threads.
The wheel should fit tightly on the encoder shaft, the grub screws helping with alignment and eliminating any wobble when turning the wheel. It can take some time to get this right, but it is possible.

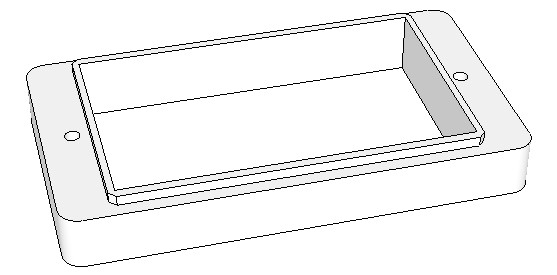
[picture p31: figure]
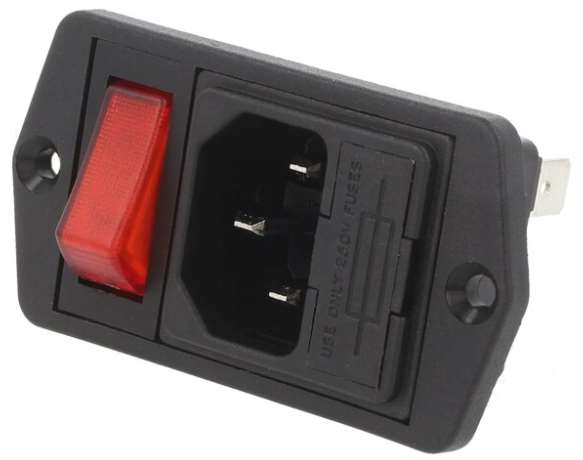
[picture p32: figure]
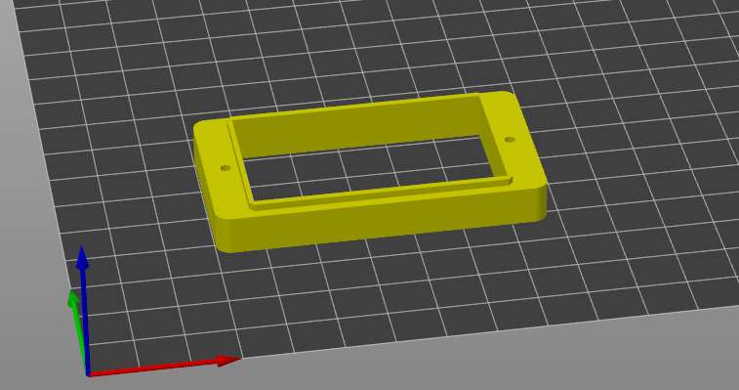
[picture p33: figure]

Building the ReZyklus DIY Case.docx | revision 0.3 | Page 8 of 10

An alternative would be to have this part Resin Printed for a better finish, however it may be necessary to alter the STL model to accommodate the different printing process.

IEC Mains Inlet Mount

This part is intended to act as a “backing plate” for the combination IEC Inlet and Power switch, specifically part: Bulgin BVA01/Z0000/02
- /02 is the suffix for a red neon-lit switch
- /01 is the suffix for a black non-lit switch

However, this part is not supplied as a moulded one-piece design; instead it consists of a power switch and IEC inlet snapped into a plastic bezel and is not particularly well made (despite the brand and price!). It requires some hot glue or epoxy to secure the parts in the mounting bezel.
The part mounts from the front-side of the panel, and the 3D printed backing plate helps with alignment and also provides holes for 2x M3 8mm Self-tapping screws.
The part should be printed flat onto the print bed:

Recommended infill is 20% Gyroid or Rectilinear, just to provide plenty of material around the mounting holes, 2 perimeters and 3 top & bottom layers (pretty standard settings).

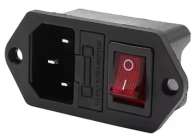
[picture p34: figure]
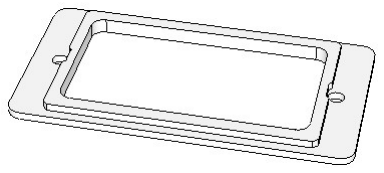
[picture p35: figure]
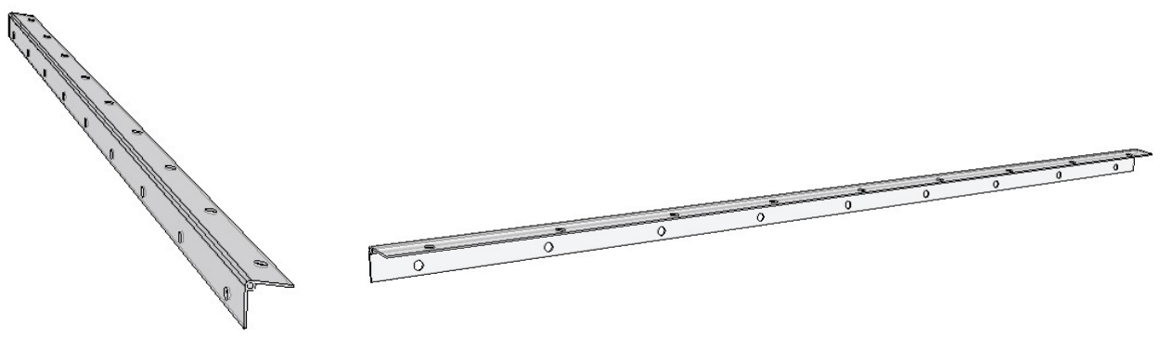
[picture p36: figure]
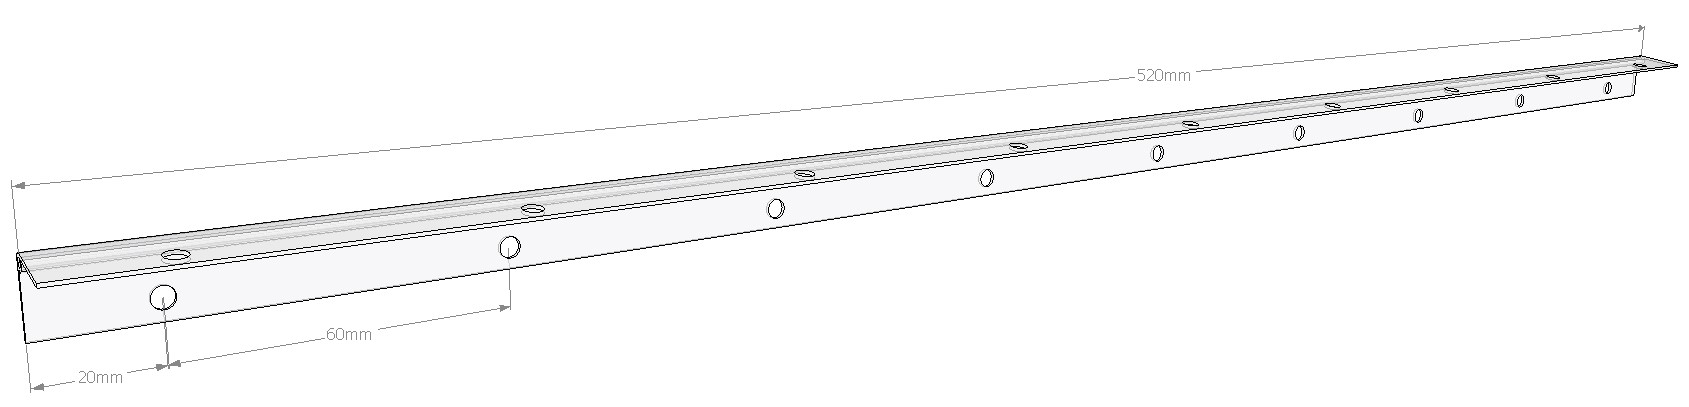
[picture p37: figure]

Building the ReZyklus DIY Case.docx | revision 0.3 | Page 9 of 10

UPDATE: There are better inlets available (AC-01A) which are one-piece designs, however these require a slightly different sized cut-out on the panel. To accommodate these, a 3D printed insert plate has been designed to fill in the gaps around the inlet:

This would be an easy print, flat face down on the print bed with 100% infill.
Note than when fitting this type of inlet, the mounting holes on the case panel would need to be filed into slots to allow for the closer spacing of the mounting holes on this type of inlet.

Hinge Assembly
(shown below in two orientations)

The DIY case was designed with a hinge mounting the top and rear panels together; this provides a neat solution to the 80° angle between the two and allows for easy opening to get inside the unit.
The brass hinge used was obtained from a local hardware store (Wickes in the UK) but seems to be pretty standard in dimensions/hole spacing as those found on sites like Amazon.
It will require cutting to length, probably from both ends to ensure the holes line up with the panel. The cuts should be done with either a rotary tool (e.g. Dremel) cutting disc, or a fine bladed hacksaw. The length and mounting hole spacing should be as shown below:

The hinge is attached on the inside of the two panels using M4 8mm Button-head Hex bolts and suitable nuts & washers (suggest Nyloc type nuts); note that not every hole on the hinge is used.

Building the ReZyklus DIY Case.docx | revision 0.3 | Page 10 of 10

Document Revision History
Date | Version | Notes
13/10/2024 | v0.1 | Initial Draft
14/10/2024 | v0.2 | Minor corrections
11/12/2024 | v0.3 | PSU PCB requires 10mm spacers. Updated some images.

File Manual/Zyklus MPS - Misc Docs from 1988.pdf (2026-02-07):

Here’s some documentation for users that I dug up in ancient files, today, 2011-04-07.

### --Pete

Doc: ‘UN1’ (UN = User Note)

ZYKLUS MIDI PERFORMANCE SYSTEM ------------------------------

Pete Kellock | 3/2/88
| | GETTING STARTED | |

From first taking the machine out of its box, you can be up and running in

5 minutes if you follow the guidelines below. From there on, if you have

difficulties in finding or understanding a feature, refer to the User Guide.

It has an index and a 'Problems Page' for quick reference.

1. Take the MPS out of the box and check that the Voltage Selector on the

back is set to your local voltage.

2. On the back of the MPS, connect the MIDI Input plus MIDI Output A to a synth (or other MIDI gear) as follows:
----------- | MIDI Out | MIDI In | ----------
| | |------------------>--------------------| | |
| | Synth | | | | | MPS | |
| | | | MIDI In | MIDI Out A | | | |
| | |------------------<--------------------| | |
3. On the synth, set the transmit & receive channels to 1.
4. | Plug in the mains and switch on. | Adjust the display brightness &
viewing angle by turning the 2 controls on the base of the unit. | You

should now see the following display:

120 | A1 A1 A1 A1 A1 A1 A1 A1 A1 A1 A1 A1 | (Output A, channel 1)
120 | T | T | T | T | T | T | T | T | T | T | T | T | ('Thru' in all 12 positions)

[ If you don't have the above display, the memory probably isn't blank
so you should format it. | The quick way to do this is to switch off the
machine, hold down blue keys 1, 3 & 5 only, then switch on. | BE VERY
CAREFUL ANY TIME YOU USE THIS FEATURE - IT ERASES THE ENTIRE INTERNAL MEMORY WITHOUT WARNING YOU! ]
5. Press & release the ASSIGN SEQ key (4th black key at top), turn wheel to

right and press the ENTER key to select ASSIGN-12-FREE. You will now

have the following display:

120 | A1 A1 A1 A1 A1 A1 A1 A1 A1 A1 A1 A1 | (Output A, channel 1)
120 | 01 02 03 04 05 06 07 08 09 10 11 12 | (Seqs 1 to 12 assigned)

You now have 12 free sequences and can record on any of them.

6. | Press the REC/EDIT key then Control Key 1 (the 1st blue key). | The

display will change completely - you are now in step-time record on

sequence 1. | Play a few notes near the bottom of the keyboard and you
| will see them appear at the right of the display.
7. | Now record a few notes into sequence 2. | To do this, press REC/EDIT then
Control Key 2 and play in the notes. | Use notes near the top of the

keyboard so that they're clearly distinguishable from sequence 1.

Notice that you're still hearing seq 1 while you're recording seq 2 . If

you don't want this, press Control Key 1 again and it's LED will go off (to

show that you're not monitoring it any more).

8. | Press PLAY then RUN/STOP. | You can now replay your 2 sequences,
triggering and controlling them in hundreds of different ways. | The

current triggering mode depends on the 12 grey keys at the right of the

machine and the STEP key at the left - these 13 keys are known as the

'Trigger Profile' keys.

9. | Start with all 13 Trigger Profile keys off. | Press the blue Control Keys
1 and 2 to hear your sequences. | Switch these keys on & off a few times -

notice how you have independent control over each sequence and that they

each start from the beginning when you activate them.

10. Switch off both sequences, press the EXT TRIG key at the right and
hit Control Key 1 again. | Notice that it now flashes to tell you it's
ready. | Hit a note on the synth and the sequence should be triggered

(if not, check the connections and make sure that the RUN/STOP key is

still on). | Experiment with the following cases:
a) Hit a note on the synth, release it, then hit another. | Note how the
sequence is transposed and re-triggered each time.
b) Hold down a note on the synth, then press another while keeping it held. Note that 2 transpositions of the sequence are now running in parallel and the sequence is not re-triggered till you release all notes and press a new one. You can have up to 8 transpositions running in parallel - ie up to 8 'Control Pitches' for each sequence.
c) Try hitting the synth notes with different touches (hard & soft). If you're using a velocity-sensitive synth with a velocity-sensitive sound you'll hear that the velocity is being controlled from the keyboard.
d) While seq 1 is running, press Control Key No 2. | You can now trigger
seq 2 from the synth keyboard. | Note that whatever Control Pitch(es)
you set for seq 1 are now fixed or 'pitch-locked'. | (Normally a
sequence becomes pitch-locked if it is running when you press the Control Key for another sequence.)
e) You can stop or 'kill' either sequence by pressing its Control Key while it is running. You can then set it ready (flashing) by pressing it again - and so on.
11. Kill both sequences and switch on the STEP key at the left side of the MPS.

You can now single-step through the seqs from the blue Control Keys or

from the synth keyboard (if EXT TRIG is on). Note that if EXT TRIG is off

and you want to kill a sequence, you must release STEP before pressing the

Control Key.

12. Put on the MOM (Momentary) key and experiment with various combinations of

MOM, EXT TRIG and STEP. The effect of the MOM key should soon become

clear.

You have now covered maybe 2% of what the MPS can do, but hopefully you can

begin to see the possibilities for triggering & controlling sequences in

real time - ie PERFORMING the sequences. This is essentially what the MPS

is all about, but many of the possibilities which arise from this basic idea

are surprising. The MPS is as much a 12-channel MIDI effects unit or a

12-channel MIDI control station as it is a sequencer.

To explore forward from this point it is probably best to experiment with

the features introduced above but using more sequences. If you want to

record some sequences in real-time, just hit RUN while in step-time record

mode. | (You should normally start with a free sequence - attempting to play
over an existing sequence causes a punch-in, NOT an overdub.) | You set the
loop point in real-time record mode by hitting ENTER or RUN/STOP. | To start

recording a different sequence you then press another Control Key.

You may find it useful to go straight to User Note 2 at this point - it

gives various tips which will allow you to get on faster.

Doc: ‘UN2’
ZYKLUS MIDI PERFORMANCE SYSTEM ------------------------------
Pete Kellock | 4/2/88
| | MISC TIPS | |

If you're a beginner or near-beginner with the MPS, the following tips may

help:

1. If nothing happens (eg no sequences run) when you press the blue Control

Keys, check the following:

- that you are in Play mode (PLAY is on, REC/EDIT & PERF are off)
- that RUN is on
- that the sequences assigned to the Control Keys have some notes in them. (You can check by going into step-time record mode.)
- this is less likely, but you might have somehow selected EXTERNAL CLOCK. If unsure, press TEMPO and look at the left of the display. If it says EXT CLK you will have to reselect INTERNAL CLOCK under the black GENERAL OPTIONS key.
2. If you have recorded some sequences, are now in Play mode, and your

sequences seem to have mysteriously vanished, you have probably changed

Configuration. To restore your previous Config, press the CONFIG key,

then keep pressing ENTER until you see your original 12 sequence numbers.

3. If you can't switch the Control Keys off in Play mode, you probably have
the STEP Trigger Profile key on. | This is perfectly normal healthy MPS
behaviour. | Switch off STEP and you will be able to switch off the

Control Keys.

4. You cannot go from RECORD to PLAY modes or vice versa when the machine is running. Similarly the 8 black 'Function' keys at the top have no effect

when the machine is running.

5. In step-time record mode you change step size, enter rests, etc by HOLDING

DOWN the STEP key and pressing the Control Keys - see the legending above

the Control Keys for details.

6. To record chords in step time, you hold down at least one note on the synth

and press the other notes in the chord (up to 8). The time only moves

forward by a step when you release ALL notes on the synth.

7. In step-time record mode, the Start-Of-Sequence is shown by a > symbol
and the End-Of-Sequence by a < symbol. | If the display shows | > < | you are

on a free sequence.

8. When you set a loop point in real-time record mode (by hitting ENTER or

the ENTER footswitch), it sets the loop point TO THE NEAREST BEAT, so you

have to press it quite accurately. However, if you don't get it right,

you can press STOP, move forward to the End-Of-Sequence marker (which is

the loop point), hold down the MOVE key, and wheel the marker to the time

you want it at - then press RUN. Sounds tedious... but it's actually

very easy when you get used to it.

9. To delete an unwanted sequence, do the following:

... in PLAY mode: Hold down DELETE and press a Control Key which has the desired sequence assigned to it.

... in step-time RECORD mode: Hold down ENTER and press DELETE.

Doc: ‘APPLICS’
Using the MPS

What advantage does the MPS give you compared to conventional sequencers?

Most hardware and software sequencers are fine if a) you have a pretty clear

idea what you want to do before you start recording and b) you want to end up

with a piece of music in a single fixed final form. They are not so friendly

if you are starting to build up a song from a couple of basic ideas or if

you want to be able to structure the basic material for a song in different

ways. The MPS gives you a lot of this flexibility and additionally opens

up a whole range of new effects.

Users seem to have identified 4 main types of application where the MPS has

the edge or is at least a useful addition to conventional sequencers:

1. Creative tool. The MPS lets you record basic musical ideas very much as

you would on a conventional sequencer, then allows you to trigger these

in any order and combination and at different transpositions to form

longer sections The 'basic ideas' can be anything from short phrases,

melodies, rhythms, single chords, etc, up to entire tracks or sections of

the music. Typically you would use a mixture of these - so you might

start from a repeating 2-bar drum pattern, bring in an 8-bar bass track,

then fire off various short phrases/rhythms/chords/etc in real-time over

the top. As you do this, everything that's happening can be recorded.

This way of working applies as much to getting a groove going for a pop

or hip-hop track as it does to working up a jingle from a short hook line

- or for that matter to the classical concept of developing a composition

from a single musical idea.

2. Production/remix tool. | The same type of principle applies to building
longer sections into an overall song structure. | This can be controlled

spontaneously in real-time then edited to give various finished versions

- the ideal tool for 12" remixes! When several people build complete

pieces from the same material the results can be drastically different.

3. Live performance sequencer. The MPS allows the musician to choose to

what extent the shape of a song is predetermined before the gig and to

what extent it is controlled live in real-time. Like any sequencer it

will allow entire songs to be recorded in fixed form; at the other extreme

a piece can be improvised live on the MPS by spontaneously triggering

individual tracks. A useful mid course is to program the song as a

number of sections and to exercise live control over the transitions from

one section to the next, leaving each section to loop as many times as

required - so if the guitarist decides to do a 20-minute solo, the

sequencer can be made to wait before going on to the next section (or

it can be moved on to the next section when the rest of the band has had

enough!).

4. Effects generator / 'sound processor'. MIDI triggering allows a whole

range of effects based on the interaction of sequence and live data.

Here are examples:

a) Chord and arpeggio effects triggered from MIDI. A unique feature of

the MPS is 'hold-at-end' which allows a track to run through then hold

the final note or chord as long as any notes are held. If the

first part of the track consists of very rapid notes, they are

heard as part of the timbre rather than as a sequence of notes - but

obviously the effect IS sequence data and hence totally editable.

b) Tracks consisting of a repeated note can be used for superposing various

effects on live MIDI input. For example, a track consisting of a

rhythmic pattern 'tapped out' on a single note can be used to

superimpose this rhythm on live playing. A track consisting of a

single note repeated several times with decaying velocity introduces

a 'delay line' effect when triggered from live MIDI data. A track

consisting of a fast repeating note effectively 'strums' live input,

etc.

As each of the above effects takes one of the 12 tracks of the MPS, any

combination of 12 can be triggered simultaneously. One of our standard

demo examples is an extreme case of this where 8 tracks are used to

simulate a huge orchestral chord - the tracks introduce various delay

effects (because the perceived 'size' of an orchestral chord arises partly

from the fact that real players are not perfectly in time) plus octave

transpositions, string tremolando effects, harp arpeggios, etc. The

resulting sound (which we demo using only a TX81Z and an MT32) is

massive - but unlike a sampled orchestral effect, it doesn't raise loop

point issues and is quickly editable as MIDI data.

These are the main MPS applications discovered so far. Even these do not

fully utilise its capabilities, so there may still be several applications

waiting to be discovered.

Doc: ‘EXP’

Using the Zyklus MIDI PERFORMANCE SYSTEM as a tool for Musical Experimentation ------------------------------------------------------------------------------

Pete Kellock | 8/2/88

ZYKLUS Ltd, Unit 4, Prospect House, Prince Georges Rd, Colliers Wood,

London | SW19 2PT. | Tel 01 675 1816

This document covers some aspects of the MPS which may interest any musicians

involved in 'musical experimentation'. This isn't just intended to include

what's usually termed 'experimental music' - the ideas covered here could be

as useful in some pop/rock/jazz/new age music as in avant-garde/aleatory/

/minimalist/serial music. The main point is that the MPS allows rapid

musical experimentation within chosen levels of predictability - not through

setting up mathematical probabilities or compositional algorithms, but by the

relatively straightforward principle that recorded sequences can be

independently controlled and manipulated in real-time during playback. A

secondary point is that the MPS is an efficient tool for recording and

editing sequences where a high degree of precision is required - again this

could apply as much to experimenting with the 'feel' of a drum part as

entering a mathematically-defined serial composition.

SYSTEM OVERVIEW

Although the MPS has many of the features of a conventional sequencer, the

principle of independent real-time control over recorded sequences leads to

many possibilities which are not always immediately obvious and are not

generally associated with sequencers. The MPS is designed to make a large

number of these possibilities rapidly accessible, both for live use and to facilitate experimentation in a studio or similar environment. Its overall

system architecture and its manner of operation are therefore significantly

different from conventional sequencers, particularly in its Play modes -

sequences can be PERFORMED rather than just replayed. The main elements of

the design which make this possible are as follows:

1. Up to 12 polyphonic sequences can be triggered independently in real

time very much as if they were single notes or sound events. Triggering

can be from the front panel, from an external MIDI contol source

(typically a synthesiser keyboard), from a footswitch or from a gate

signal. | The relative synchronisation of the sequences is controlled
by several options. | For example, a sequence can start immediately it

is triggered, regardless of any other sequences running, or it can be

forced into a certain level of 'Relative Quantisation' (say to the

nearest semiquaver relative to another sequence), or when triggered it

can pick up in the middle as if it had been running silently in the

background. Sequences can also be single-stepped from the control

source.

2. When triggered from a MIDI source, each sequence can run simultaneously at

up to 8 transpositions, and the 8 'Control Pitches' can be different for

each of the 12 sequences. | The resulting pitches are a real-time matrix
multiplication of the sequence pitches and the Control Pitches. | For

example, if the sequence had a C major triad at a certain point in time

and the Control Pitches were A and F#, the resultant pitches would be

(A + C# + E) + (F# + A# + C#). Because both the sequence and the Control

Pitches are functions which vary in time, the harmonic, rhythmic and

harmonic/rhythmic information can be spread between the sequence and the

'live' data to any chosen degree. To give 2 extreme examples:

a) A 12-voice polyphonic work could be recorded as 12 complete sequences

routed to different timbres on 12 MIDI channels. The control pitches

could then be used to 'arrange' these parts, experimenting with various

octave offsets or doublings applied to each part.

b) Rhythmic patterns can be recorded as sequences on a single pitch.

These patterns can then be superimposed on live playing.

3. Each Control Pitch of each sequence has a MIDI note velocity value

associated with it. These 'live' velocity values can be averaged with

the sequence velocity values in various proportions to produce the

resultant velocities.

4. The way in which control pitches are assigned to the 12 sequences is

selectable from a large number of options. For example, the control

pitches for certain sequences can be 'frozen' while others remain active,

or incoming pitches can be routed in a cyclic manner to a combination of

active sequences.

5. A second level of transposition is provided - this causes the Control

Pitches themselves to be transposed. Normally all active sequences

are affected, but an option is provided for inhibiting transposition of

certain sequences.

6. The way in which the controls respond and interact is also selectable.

For example, if a MIDI keyboard is being used, sequences can be selected

to run only while notes are held on the keyboard, or to continue running at

a given set of pitches until a new note or set of notes are pressed.

7. Most of the options described above are selected by single key presses and

can be altered in real time during replay. To be more precise, the control

options or 'Trigger Profile' is defined by the state of 13 on/off

parameters which can be set in any combination, so in theory there are

8192 (2 to the 13) possible Profiles! | In practice there are probably
several hundred useful distinct modes. | These can be mixed in various

ways - for example some sequnces can be running while others are being

single-stepped.

8. Sequences can also be assigned one of 3 'Repeat Modes' : Repeat, Single-

Shot or Hold-At-End. The first 2 are common to most sequencers, but Hold-

At-End is a novel feature allowing a sequence to run through and come to

rest on its final note or chord. In a typical case a sequence will

consist of some rapid notes ending on a note or chord.

9. Sequences can be set to any length, definable to within a single clock

pulse (1/96 of a beat). All sequences run independently, so any which

are set to Repeat will loop independently of others.

10. Because MPS sequences are often small elements of an overall musical

structure, it is useful to have the freedom to 'pick & mix' existing

sequences, sometimes using the same sequence in several musical

contexts. The MPS architecture facilitates this by allowing any

combination of 12 sequences to be assigned to the 12 'positions' on the

front panel for immediate use. | A set of assignments plus other associated
data forms a 'Configuration'. | There are 24 Configs, any of which can be
rapidly selected - typically by a single key or footswitch press. | The

associated data includes 12 MIDI destinations (ie bus & channel number)

for the sequences, plus a large number of optional parameters - eg MIDI

mode & program changes, on/off startup states for the 12 assigned

sequences, tempo values, etc. All such parameters have a 'no change'

option, so Configs can be used for subtle or drastic changes in the

system setup.

11. The MPS also allows 12 'Performances' to be recorded, edited and replayed.

In a Performance, all actions are recorded: identity & timing of sequence

triggerings, MIDI events received, tempo & Config changes, etc

12. The MPS has several additional features generally associated with 'MIDI

Utility Boxes' rather than sequencers. For example, it allows complex

MIDI Thru routing to multiple destinations, keyboard zoning, step-through

of MIDI program changes, etc. In combination with the sequence control

options, this allows the MPS to be used as a central MIDI control station.

EXPERIMENTAL TECHNIQUES/EXAMPLES --------------------------------

1. As stated above, repeating sequences have independent loop points. In a

typical rock example, this means one sequence can be a bar long, another 8

bars and another 32 bars. More unusually, one sequence can be 4 beats long

and another 5 beats - obviously this causes a gradually changing rhythmic

pattern which repeats every 20 beats. A more extreme example is to mix

sequences which differ in length by one or more clock pulses to produce

phasing effects. The clock resolution is a 96th of a beat, so a 4 beat

sequence and a 4 beat + 1 clock sequence will produce a pattern which

repeats after 384 times through the longer sequence - fine enough resolution for most phasing effects.

Note that a 'beat' defaults to a value of 1 crotchet, but the time signature

can actually be set anywhere in the range 1/2 to 32/8. Although this may

seem slightly limiting in the denominator value, it is unlikely to present

a problem as the time signature only affects metronome speed and bar/beat

display while recording - in general the MPS makes little use of, and is

not limited by, concepts of bar or beat.

2. In assigning sequences to the 12 positions on the front panel, the same

sequence can be assigned to several positions. This allows complex

imitative textures to be built up where relative timing can be

free/quantised/etc and different transpositions & velocities can be

applied to each part. This can be improvised in real-time or tightly

controlled by setting the trigger points to single clock-pulse resolution

in a Performance (see 10 above for definition of a Performance).

3. As sequences can be triggered by MIDI note on/off data, many

possibilities exist for triggering sequences from other sequences. The

resultant patterns can be tightly controlled or pseudo-random, depending

on the relative lengths of the sequences, the times between events, etc.

The controlling sequence could be a Performance (essentially a Performance

IS a sequence with some additional types of event, and is recorded in a

very similar manner). Alternatively one of the MPS outputs can be looped

back to the input and some sequences used to trigger others, or sequences

used to transpose themselves. Using external equipment many other

possibilities exist - for example triggering from an external sequencer

or merging looped-back sequences with live data.

In all these cases different sequences can be triggered from different MIDI ranges and/or respond cyclically to MIDI events. It is also possible to

impose the rhythm of one sequence on another by disabling transposition

on the controlled sequence then single-stepping it from the controlling

sequence.

4. The 'Hold-At-End' feature described above can be used to produce quasi-

timbral and ensemble effects. The most obvious technique is to use very

rapid introductory notes to produce 'chiff' effects before the final note

or chord. A less obvious technique is to record several single-note

sequences with varied initial delays of a few clock pulses, route these to

different MIDI destinations, then trigger them simulataneously from live

MIDI data - the effect can be similar to ADT (Automatic Double Tracking,

a standard studio technique) or in more complex cases can simulate the

effect of subtle timing errors when several musicians play 'in unison'.

5. Other delay effects can be created using simple sequences. For example,

a sequence can consist of a repeated note with decaying velocity; when this

is triggered from a MIDI source and routed to an appropriate velocity-

sensitive sound, the effect can be similar to a delay line with feedback.

However, unlike the delay line, each repetition can change octave or

undergo any other pitch or velocity shift required.

6. The MPS is specially suited to creating textural effects based on rapid
internal movement: strumming & arpeggiation effects, rolls etc. | These are
based on rapid repeating sequences triggered from a MIDI source . | For

example, a simple sequence based on octaves can be used to produce a

halo of rapid movement round a melodic line.

7. Interesting semi-determinate effects can be produced when the MPS is used

to control a device which has several sounds each allocated to different

MIDI pitches, such as the majority of drum and percussion sound generators.

When a sequence routed to such a device is transposed, the rhythm is

preserved but the sound assignments are changed. | Use of multiple Control
Pitches can cause the rhythm to be doubled on several sounds. | Because the

MPS allows individual sequences to be triggered/transposed independently

AND has a second level allowing overall transposition, subtle or drastic

changes can be effected in response to single MIDI note events. With a

little experimentation this can be a powerful technique for live

improvisation.

8. As stated above, the MPS is an efficient tool for recording and editing

sequences when high precision is required. Although this is conventional

sequencer territory, the MPS has several advantages in terms of quick

operation. For example, when entering notes in 'step time', a wide

selection of step sizes are available and the on-time of each step can be

set from 0% to 255% of the step size, the latter allowing overlapping notes

to be entered very easily. Chords are entered by holding down several

notes - time moves forward to the next step only when all notes are

released. However, the most powerful features are the single-event

editing controls:

DELETE: Single note delete

VAL: | Used to view & alter value of a MIDI event. In the case of note
events, this refers to the velocity value.

LENGTH: Used to view & alter note on-time.

MOVE: | Used to move a single event in time by units of one clock
pulse. | The timing of other events is not affected.
SLIDE: | Used to move an event AND ALL FOLLOWING EVENTS by units of
one clock pulse - ie to time-slide sections of a sequence.

All these controls are based on single-keystroke operation. For example,

to move an event, the cursor is positioned on the event, MOVE is held down

and the wheel is turned to move it; a continuous read-out of time is given.

On releasing MOVE the note is at the new time position. (The operation

typically takes 2 or 3 seconds to perform.)

Together these controls allow note on/off and other MIDI events to be

positioned accurately with a resolution of 1/96 of a beat. | A possible
objection is that 1/96 of a beat is not sufficiently accurate. | However,

this represents resolution to approx 2.5 mS at maximum tempo, which is

accurate enough for most purposes, firstly because such delays are

detectable only in the case of percussive or other sounds with fast

attack transients (and normally only when such sounds are nominally

simultaneous - a 2.5 mS shift is seldom detectable in a sequential series

of events), and secondly because this is within the region of MIDI and

software delays. (For comparison, it takes approx 1mS to transmit a

Note On or Note Off event over a MIDI link.)

Hopefully the above gives some idea of the potential for experimentation

with the MPS. Because it is innovative and generally 'open-ended' in design,

there are no doubt many other possibilities - particulary in the area of

Trigger Profile, where the sheer number of combinations means that many are

as yet untried. | We welcome hearing from any users who discover useful new
techniques and are willing to share the information. | We also welcome

suggestions for improvements and upgrades - sometimes these turn out to be

easily implementable in software (though often not, of course!) so even

changes which are suggested by only a few people will at least be seriously

considered.

Doc: ‘SEP’

The Art of Sequencing According to Zyklus -----------------------------------------(Article written for SE + P)

Pete Kellock | 29/4/88
Who says MIDI's a good thing? | I seem to remember a time in the dim &
distant past (5 years ago?) when there were electronic instruments on the one hand and pro audio gear on the other. You dealt with synths & sequencers or you dealt with desks and outboard, and music software was an area of academic research as relevant to most people in the music industry as molecular biology. We thought life was complicated, but little did we know...
Look what MIDI's done for us. | Lots of new possibilities. | So many
possibilities that we spend half our time trying to figure out what various bits of equipment/software can and can't do, how easily they let you do it, how they can be interfaced with other gear, what the software upgrade paths might be, etc, etc. Result - boggled brain cells and less time to think about music.

In designing the Zyklus MIDI PERFORMANCE SYSTEM (MPS), it could be argued that we have simply assisted this trend. We have produced a system that creates a whole new set of possibilities which can't be neatly categorised and are fairly difficult to describe in words. To make matters even worse, we seem to have opened up several entirely new directions which may breed
whole FAMILIES of new products and new possibilities. | Aaaagh!
Why have we done so? | To get to the point - because we think that
conventional sequencers are too rigid and inflexible for many purposes. They are fine if a) you have a pretty clear idea what you want to do before you start recording and b) you want to end up with a piece of music in a single fixed final form. They are not so friendly if you are starting to build up a song from a couple of basic ideas (such as a rhythm pattern and a bit of melody), or if you want to be able to structure the basic material for a song in different ways (eg for a remix or to allow a bit of flexibility during a live gig).

The MPS gives you a lot of this flexibility and opens up a range of new
effects. | All the possibilities arise from the one central idea of real-time
sequence control during playback. | Contrary to some widely-held beliefs they
have nothing to do with algorithmic composition, statistically-controlled random variations or molecular biology. In other words the MPS lets you record basic musical ideas very much as you would on a conventional sequencer, then allows you to trigger these in any order and combination
and at different transpositions to form a complete piece of music. The 'basic ideas' can be anything from single phrases, melodies, rhythms, chords, etc, up to entire tracks or sections of the music. Typically you would use a mixture of these - so for example you might start from a repeating 8-bar bass track, bring in a 4-bar drum pattern, then fire off various short phrases/rhythms/chords/etc in real-time over the top. As you do this, everything that's happening can be recorded.

The real power and innovation of the MPS lies in the range of triggering options or 'Trigger Profiles'. There are a vast number of these options covering aspects such as the trigger source (front panel of the MPS, external MIDI source, or footswitch), the relative timing of tracks when they are triggered, and the way pitches are assigned to tracks when triggering from MIDI. (Note: we normally use the term 'sequence' to mean the basic triggerable chunks of MIDI data, but I will use the term 'track' in this article as it probably conforms more closely to standard sequencer terminology - but bear in mind that MPS 'tracks' are much more independent than the tracks of a normal sequencer.)

The possibilities for MIDI triggering are probably the most complex aspect of
the MPS. | To say that the MPS allows sequences to be transposed is rather like
saying that a Synclavier allows you to play tunes on a keyboard. | In both
cases the misleading simplicity of the statement can easily be demonstrated but is a little more difficult to describe. What the MPS actually does is a real-time matrix multiplication of the pitch/velocity data in a track and the pitch/velocity data arriving on the MIDI input - which unfortunately is another fairly useless description unless you have a degree in Applied Maths
(and possibly even if you do). | To get closer to the idea, think in terms of
tracks being triggered from a keyboard as if they were single notes. | The
track will be transposed by the note(s) played on the keyboard and its velocity will depend on the velocities of the notes played (you can mix the original velocities in the track with the 'live' velocity in various proportions). Each of the 12 tracks can have up to 8 transpositions running at the same time, each with its own velocity, and the 8 transpositions can be
different for each track. | The timing of the track relative to other tracks at
the point of triggering also depends on several options. | All of these options
(in fact all parameters of the Trigger Profile) can be altered while other tracks are running.

What use is all this in practice? So far, we (and other users of the MPS) have identified 4 main types of application where the MPS is a superior alternative or useful addition to existing software/hardware sequencers:

1. Creative tool. As I've mentioned already, the MPS allows you to experiment rapidly with basic ideas and develop them into longer sections. This applies as much to getting a groove going for a pop or hip-hop track as it does to working up a jingle from a short hook line - or for that matter to the classical concept of developing a composition from a single musical idea.
2. Production/remix tool. The same principle of combining musical elements in different ways applies to building longer sections into an
overall song structure. This can all be controlled spontaneously in real-time then edited to give various finished versions - the ideal tool for 12" remixes? When several people build complete pieces from the same material the results can be drastically different.
3. Live performance sequencer. The MPS allows the musician to choose to what extent the shape of a song is predetermined before the gig and to what extent it is controlled live in real-time. Like any sequencer it will allow entire songs to be recorded in fixed form allowing most of the band to nip offstage for a pint; at the other extreme a piece could be improvised live on the MPS by spontaneously triggering individual tracks. A useful mid course is to program the song as a number of sections and to exercise live control over the transitions from one section to the next, leaving each section to loop as many times as required - so that the keyboards player has the freedom to do a 20-minute solo if he wants. (A software upgrade will allow pacification of the rest of the band via SysEx messages.)
4. Effects generator / 'sound processor'. MIDI triggering allows a whole range of effects based on the interaction of sequence and live data. Here are 2 types of effect we have explored in some depth:
a) Chord and arpeggio effects triggered from MIDI. A unique feature of the MPS is 'hold-at-end' which allows a track to run through then hold the final note or chord as long as any notes are held. If the
first part of the track consists of very rapid notes, they are
heard as part of the timbre rather than as a sequence of notes - but obviously the effect IS sequence data and hence totally editable.
b) Tracks consisting of a repeated note can be used for superposing various effects on live MIDI input. For example, a track consisting of a rhythmic pattern 'tapped out' on a single note can be used to superimpose this rhythm on live playing. A track consisting of a single note repeated several times with decaying velocity introduces a 'delay line' effect when triggered from live MIDI data. A track consisting of a fast repeating note effectively 'strums' live input, etc.

As each of the above effects effectively takes one of the 12 tracks of the MPS, any combination of 12 can be triggered simultaneously. One of our demo examples is an extreme case of this where 8 tracks are used to simulate a huge orchestral chord - the tracks introduce various delay effects (because the perceived 'size' of an orchestral chord arises partly from the fact that real players are not perfectly in time) plus octave transpositions, string tremolando effects, harp arpeggios, etc. The resulting sound (which we demo using only a TX81Z and an MT32) is
massive - but unlike a sampled orchestral effect, it doesn't raise loop point issues and is again totally editable as MIDI data.

In all these cases, options are provided to trigger different tracks from different keyboard zones, or to trigger them cyclically (so the first note triggers track 1, the next track 2, etc). These open up yet more possibilities for interactive performance effects.

Hopefully this gives some insight into what the MPS can do and how it
does it. | We have certainly created new possibilities and in so doing have
inevitably made the 'MIDI jungle' an even more confusing place. | However,
the MPS is in many ways a very quick system to operate - for example you can start from blank memory, enter several tracks and be triggering them from MIDI within 5 minutes. Our design philosophy is that flexibility and open-endedness should be the first goal, but 'musician-friendliness' should be a close second.

Doc: ‘DEMO’

MPS PRESENTATION WITH ALEX: GIGSOUNDS 3/2/88 ---------------------------------------------

-------------------------------------------------------------------------------PART 1
Hi. | I'm Pete Kellock from Zyklus. | I'm one of the designers of the MIDI
PERFORMANCE SYSTEM we're about to show you. | I'd like to introduce Alex
White who's NOT from Zyklus but who's been spending a lot of time with the MPS recently and probably knows it better than we do by now.

OK, what we're going to try to do just now is give an answer to that famous question "What the Hell's a MIDI Performance System?". Well... there are several answers to this, and some of them are even repeatable.

***

For example - answer number 1 - it's a sequencer. | Here are some sequences
"we prepared earlier" as they say | (I'll come back to how you record them
later).
* | CONFIG 1. | "PETE - DEMO PIECE"
* | TP: ALIGN
* | 12 'TRACK'-TYPE SEQS. | SWITCH A COUPLE ON & OFF (LIKE MONITOR SWITCHES)

(I think you can see there that you basically have 12 tracks and Alex was muting them off and on from the 12 blue control keys.)

***

So... it's a sequencer, but then again the sequences can be short phrases which you can "play" from the front panel using the 12 blue control keys along the front - almost as if the MPS was a musical instrument in its own right:

* | CONFIG 2. | "THRILLER"
* | TP: GROUP + EXCL
* | IMPROVISE FROM CONTROL KEYS: CHANGE TP & DO SOME MOMENTARY STUFF

(If any of you have used lighting controllers you might notice some similarity in the way Alex was using the machine there - in fact we got some of the ideas for that kind of live control from stage laser control systems.)

***

Then again, it can be a MIDI Control Station:

* | TURN DOWN VOLUME ON DX7
* | CONFIG 3. | "CONTROL STATION"
* | TP: EXCL

For example it can handle routing to different MIDI destinations and will send out MIDI program changes to set up the sounds on each destination: * a. DIFFERENT DESTS

... or it can route you to several destinations in parallel:
* | b. MULTIPLE DESTS IN PARALLEL | (SEQS 6 - 9)

... or you can have some wierd effects such as cycling between destinations: * c. CYCLING

... it can also zone the keyboard
* | d. GROUP - ZONING | (SEQS 4 + 8 + 11)

***

The MPS can also be used as a keyboard or MIDI effects processor. For example, playing chords from single notes:

* | CONFIG 5. "HOLD-AT-END & SINGLE-SHOT EXAMPLES"
* | TP: EXT + MOM + EXCL
* | PLAY 1 & 2 | (HOLD-AT-END)

... or getting arpeggiator-type effects from single notes

* | CONFIG 5.
* | PLAY 3, 4, 5 | (SINGLE-SHOT)
* | PLAY 6 | (REPEAT)

... or you can have effects which are a combination of arpeggio & chord

* | CONFIG 5.
* | PLAY 7 - 10 | (HAE)
* | NB: YOU MAY HAVE TO PLAY 9 A FEW TIMES (IT CONFUSES THE MT32 VOICE ASSIGN)

... or you could use it to superimpose a rhythm or a sequence onto live playing:

* CONFIG 6.
* a. PLAY 1, 2 & 3 INDIVIDUALLY | - | SIMPLE CHORDS (3 - 4 NOTES)

(You can also combine these rhythms:)

* b. PLAY 1 + 2 + 3 TOGETHER - MINOR 9TH CHORDS?

***

With some of these keyboard effects you can run them so fast that they become part of the sound. For example, here's a sound on its own:

* CONFIG 6.
* a. PLAY 4 | - | FEW NOTES, MELODIC

... now you could use the MPS to 'strum' that sound

* b. PLAY 5 | - | SAME FEW NOTES

Here's another sound:

* c. PLAY 6 | - | FEW NOTES, MELODIC, SLOW

... and you could use the MPS to give you some very fast notes at the start, producing a sort of 'chiff' effect:

* d. PLAY 7 | - | SAME FEW NOTES

... and you could comdine these effects:

* e. PLAY 5 + 7 | - | SAME IDEA

... or you could combine these with the rhythm we had above:

* f. PLAY 1 + 2 + 3 + 5 + 7 | - | HOLD SINGLE LONG NOTES & MAYBE A FIFTH

***

So, to answer "What the Hell's a MIDI PERFORMANCE SYSTEM" ... it's a sequencer, but it's a sequencer that's almost a musical instrument in its own right,
it's a MIDI Control Station, it's a MIDI effects processor and it can even
be a sound processor.

What you may be wondering at this point is whether there's any connection between all these effects. Well, as you may have guessed - just about everything you heard there was based on the one central principle of sequence
manipulation. | Those were all sequences played in different ways. | (The only
exception being when we were simply passiong data straight through, for example in some of the Control Station applications.)

So what the MPS gives you is a whole range of ways of CONTROLLING sequences -you can control them from the front panel of the MPS or from a keyboard (or any other MIDI source for that matter) or from a footswitch. When you control them from MIDI they take the pitch or pitches of the notes you play - you can have each sequence running at up to 8 different pitches (and the sequences themselves can be up to 20-note polyphonic, and also you can have a
different set of 8 pitches for each of your current 12 sequences - assuming you've got enough synths to handle all that!)

So the MPS is a SYSTEM for PERFORMING sequences (or MIDI data) - that's why we've called it a MIDI PERFORMANCE SYSTEM and not a sequencer.

-------------------------------------------------------------------------------PART 2

OK, now you've seen a few of the ways you can make use of sequences, let's
go back to square one - ie how do you get the sequences in there in the first place? In this respect it's pretty much what you'd expect of a dedicated sequencer with most of the features you'll find on any other good sequencer plus a few extras.

* PULL OUT CARTRIDGE
* SWITCH OFF. HOLD DOWN CONTROL KEYS 1,3 & 5 AND SWITCH ON AGAIN
* TURN DOWN VOLUME SO I CAN SPEAK OVER MUSIC

To show you just how quickly you can get started on it, we've cleared the
memory. | Right - the machine is now in exactly the state it's in when you
first take it out of the box. | The first thing you do is give yourself 12
unused or 'free' sequences to start recording on. | What you're actually doing
is assigning the first 12 seqs to the 12 control keys. | The machine can hold
99 seqs in its internal memory and another 99 on cartridge; you can have any combination of 12 of these available at any one time.

* ( WHILE I'M SAYING THAT LOT DO ASSIGN-12-FREE )

You can now build up sequences very quickly in step-time or real time. To illustrate this, Alex will now enter some sequences in step time then some in real time. To select the seq to record on, you simply press REC/EDIT then one of the Control Keys.

* RECORD 2 IN STEP TIME & 2 IN REAL TIME

To mention just a couple of points about that: To enter chords in step time you just hold down all the notes of the chord; when you release all notes it steps forward. The other point is that the loop points of all the sequences can be different.

(As you can hear we've got everything on one sound at the moment - we're only using the DX7 .)

***

We're now back into step time. | We'll just quickly show you a couple of the
editing features. | These can be applied to seqs you recorded either in step or
real-time - there is no difference. | To keep it simple for now, Alex has
just put in a 4-note sequence which sounds like this:

* ( ENTER SEQ 12 WHILE I'M SPEAKING )
* LET THEM HEAR IT RUNNING

Now let's make the last note louder. | You just move to the last note, hold
down the VALUE key and it tells you what the velocity of that note is. | To
change it you just turn the wheel & release the key.

* ( ETC )
* LET THEM HEAR IT RUNNING

Now let's move the last note. Again you move to it, hold down MOVE, turn the wheel and let go.

* ( ETC )
* LET THEM HEAR IT RUNNING
* ( WHILE I'M SAYING THE NEXT BIT, START ENTERING THE RHYTHMIC SEQS 5/6/7 | )
I think you can hear that pretty clearly. | And I think you can also see that
these editing features are very fast to use so you can quickly alter the feel of sequence - or it could be drum part. There are 5 which operate in a similar way - as well as VELOCITY & MOVE you have DELETE to remove notes
& other events, LENGTH which allows you to alter the on-time of notes and SLIDE which lets you time-slide a whole section of a sequence (unlike MOVE which as you saw was only affecting one note).

***

(Alex has just been entering a couple of other seqs we'll use in a minute.)

OK, we're now going back into PLAY mode, and we'll show you just a few of
the options for manipulating these seqs we've recorded. Most of these options are selected using the 12 keys on the right plus the STEP key on the left. We call these the Trigger Profile keys. The idea is that you can alter the TP very quickly just by hitting these keys and you can change TP while seqs are running - changing it never affects seqs which are running already, it only sets it up ready for the next seq you want to control.

The simplest TP is with all these off. In this mode the seqs just start whenever you hit the Control Keys:

* TP: ALL OFF. | EXAMPLE
* TP: MOMENTARY. | EXAMPLE
* TP: RESTART. | EXAMPLE

***

Before we illustrate the next option, we'll just let you hear the rhythmic seqs Alex was entering a minute ago. On their own these sound like this:

* TP: RESTART

* PLAY 5 + 6 + 7 DIRECTLY FROM FRONT PANEL

As you can hear, these are all based on C - just rhythms with some octaves. If we now put on EXT TRIG, we can control these from the keyboard and give them all different pitches, so you build up these rhythms into a sort of animated chord:

* TP: RESTART + EXT
* BUILD UP 5 + 6 + 7 TO FORM CHORD

You can now put on TRANSPOSE and transpose all of that:

* TP: RESTART + TRANSPOSE
* EXAMPLE

And we could now bring in the other seqs we recorded:

* EXAMPLE
* BRING SEQS 1 - 4 IN AND OUT

***

I hope that gives some impression of just a few of the sequence control
options. | That's only scratching the surface. | In theory there are over 8000
different possibilities for TP and you can change between any of them in real time while the machine is running. There are various other options you can set up when the machine isn't running, so the possibilities are immense -we'd love to show you them all, but it's only 2 hours to closing time!

However, I will just quickly mention a couple of other aspects of the machine.

< Explain Configs >

< Explain Perfs >

* RECORD A VERY SHORT PERF & PLAY IT BACK

Once you've recorded a Perf like that, you can edit it in much the same way you edit a sequence - delete mistakes, correct bad timing, add things, etc.

-------------------------------------------------------------------------------PART 3

* WHILE I'M BABBLING, SET UP FOR PERFORMANCE OF ALEX DEMO

OK that's the MPS in a nutshell. In terms of hardware the whole system is designed to withstand everything it might come across in live performance or on the road. For example there is extensive mains filtering and transient suppression, the memory is battery-backed so if the power goes down you don't lose your data - in fact there are 2 batteries so if the first fails the

second will take over. | We decided against using disk drives because they're
relatively fragile and slow to load. | Instead we use these cartridges which
are also double battery-backed and as one reviewer said, "designed to
withstand a nuclear explosion". | (They might even stand up to a heavy metal
gig.) | You can actually run from the cartridge, so you don't even have to load
it in.

In terms of connecting it up you have: 1 MIDI input and 4 MIDI outputs.
There's SYNC IN & SYNC OUT with various clock speeds. | Also, if you're using
MIDI clocking the MPS supports MIDI Song Pointers. | In terms of other I/O,
there is a metronome output plus 3 footswitch inputs. | We've also tried to
support people who have older pre-MIDI gear or modular systems, so the footswitch inputs can take gate signals and there's a programmable gate output. There's even a special trigger input for very fast trigger signals.

To finish we'll play a complete piece written by Alex for the machine - the whole thing is stored as a Performance. After it I'll be here to try to answer any questions you have.

* ALEX DEMO

Doc: ‘DEMON’

MPS PRESENTATION WITH ALEX: GIGSOUNDS 3/2/88 ---------------------------------------------

Intro: me & Alex

Setup

What the Hell's a MIDI PERF SYS? - Several possible answers

1. Obvious answer: | SEQUENCER. | ** ALEX **
| (Muting on & off)
2. Independent seq ctrl: | MUSICAL INSTRUMENT | ** ALEX **
(Lighting controllers)
3. Also: | CONTROL STATION
- routing + prog changes | ** ALEX **
- multiple destinations | ** ALEX **
- unusual effects - cycling** ALEX **
- zoning | ** ALEX **
4. Also: | KEYBOARD/MIDI EFFECTS PROCESSOR
- chords from single notes ** ALEX **
- arpegg.-type effects | ** ALEX **
- arpegg + chord | ** ALEX **
- add rhythm to live playing | ** ALEX **
- combine rhythms | ** ALEX **
5. Run effects fast - becomes
part of sound: | SOUND PROCESSOR
- sound on its own | ** ALEX **
- 'strummming' effect | ** ALEX **
- sound on its own | ** ALEX **
- 'chiff' effect | ** ALEX **
- combine these | ** ALEX **
- combine with rhythm | ** ALEX **

So answer to "What the Hell's MPS?" - 5 answers
- and can combine them

Any connection? Yes - all sequences controlled in different ways (except Thru connections).

MPS gives you control from - front panel

- MIDI
- footswitch
- gate

In case of MIDI control, seq transposed. (8 x 20 x 12 if enough synths!)

So MPS is system for performing MIDI data - a MIDI PERF. SYSTEM
... much more flexible & creative than conventional sequencer.

Back to square one - recording.

As you'd expect - all features of dedicated sequencer + few extra

To show how quick started, Alex has cleared memory.

Only thing before recording is to assign 12 free.

Can hold 99 internal + 99 cart. Any combination of 12 of these at one time.

To start recording just press REC/EDIT + Ckey.

Can build up quickly in step-time or real-time - Alex will now do. ** ALEX **

( Mention - quick build-up (Linn 9000 mode)
- different loop points
- 2 types of punch-in in real-time. Simplest just to play.
- Punch-ins don't cut notes
- in step time, can quickly change step size, enter rests/chords
- wide range of step sizes )

Editing. Back to step-time.
... but seqs can be step-time or real-time
To keep simple - 4 note seq. | Sounds like: ** ALEX **
Velocity - last note louder. | Play: | ** ALEX **
Move - shift last note. | Play: | ** ALEX **

5 controls like that - designed for very fast use.
(VAL & MOVE) + DEL, LEN, SLIDE
Use to quickly correct errors or to alter feel - eg drum part

(Alex entering a couple of other seqs)

PLAY mode - control options | ... using material just recorded
TP: | 13 keys On/Off in any combination Change while running No effect on seqs already running
1. TP: All off | ** ALEX **
2. TP: MOM | ** ALEX **
3. TP: RST | ** ALEX **
Before next option, hear seqs | ** ALEX **
(All based on C with octaves)
4. TP: EXT + RST. | Animated chord | ** ALEX **
5. TP: RST + TPS. | Transpose all ** ALEX **
6. Then bring in other seqs | ** ALEX **

Hope that gives impression. Only scratching surface.
In theory over 8000 TPs + other options set up when stopped. (eg rmode) Love to show more control options, but if we showed 10% we'd still be here tomorrow morning.

But will mention 2 other levels of control:

CONFIGS: Currently seqs 1 - 12 assigned. What if want next 12 going to a different set of MIDI destinations? Answer: Assignments are part of a Config.
24 Configs
Also stores TP, Tempo, up to 24 MIDI prog changes on each Config, etc ... so can completely re-configure system
Change by pressing ENTER or footswitch
PERFS: | What if want to store all live triggering?
Answer: Perf
12 Perfs
Perf stores: all seq triggering, live playing, Tempo changes, Config
| changes, etc

Example: ** ALEX **

Can edit like seq: delete mistakes, correct bad timing, add events ...

That's what MPS does. Briefly mention HARDWARE:

Designed for live use as well as studio
- engineered for life on the road & general rough treatment
- Not just in terms of casing, etc
- connectors - pro quality metal DIN connectors
- Also applies to electronics:
a) Mains filt./trans. suppr. - bad mains in stage envir. (Vangelis)
b) I/O overvoltage prot. - connect to nearly anything
- Decided against Disk Drive - relatively fragile (& SLOW)
- Instead all memory is battery-backed with 2 batteries
- No need to save data. | Comes up exactly as on power-down
- Carts: Also double battery-backed. | Reviewer: "Nuclear Explosion"
- Can also run from Cart so no need to load to internal

CONNECTING UP:

- 1 MIDI In & 4 MIDI Out. Can sync to MIDI & supports song pointers
- Sync In & Sync Out with various clock speeds
- Metronome Out
- 3 footswitch inputs. Can also use gate signals for pre-MIDI
- Gate Out
- Trigger In

To finish - Alex piece

Questions afterwards

Piece stored as Perf, so just hit Run.

Doc: ‘SETUP’

MPS DEMO SETUP | 17/3/88
The MIDI PERFORMANCE SYSTEM demo material comes on 2 cartridges. | Cart 'A'
consists of a single piece of music arranged as several configurations. Cart 'B' has a number of separate configurations intended to illustrate different uses of the MPS in a variety of musical contexts.

In order to ensure that the demo sequences are always assigned to appropriate voices, we use a standard MIDI setup based on 2 low-cost expander units:
a Yamaha TX81Z and a Roland MT32. The only additional requirements are a master synth (preferably velocity-sensitive) and reverb (preferably MIDI-controlled).

MIDI Destinations
A1 | Master Synth
B1 - B4 | TX81Z
C2 - C10 | MT32. (C10 is drums)
C16 | Reverb | (on same MIDI bus as MT32 using Thru connection)
Demo Cart 'A': | Sounds
Master Synth: | High marimba/block type sound. | (2 octaves higher than normal)
TX81Z: | The following sounds must be assigned to Perfs:
Perf 22 | A10/A10/A10/A31/ (MIDI chans 1 - 4)
Perf 23 | B21/B5/B24/C4/ | (ditto)
Perf 24 | A31/D4/C4/A31/ | (ditto)
These perfs are called up automatically by MIDI program changes.
MT32: | All sounds called up automatically by MIDI program changes
Demo Cart 'B': | Sounds
Master Synth: | Hard electric piano type sound (normal pitch)
TX81Z: | As above
MT32: | As above

Reverb
The demo material sends out reverb program changes in the range 1 to 16 on destination C16. We normally use a MIDIVERB II with the program changes cross-mapped to effect numbers as follows:
Prog FX No Description | | Prog FX No Description
1 | 31 | Slow Gate 200mS | | 9 | 35 | Fast Gate 150mS
2 | 28 | Xlarge Warm 5S | | 10 | 5 | Med Bright 0.6S
3 | 21 | Large Warm 2.2S | | 11 | 32 | Slow Gate 250mS
4 | 22 | Large Warm 1.75S | | 12 | 27 | Large Bright 2.5S
5 | 13 | Large Warm 1.1S | | 13 | 8 | Medium Dark 0.6S
6 | 7 | Large Dark 1.0S | | 14 | 11 | Medium Bright 0.8S
7 | 26 | Large Bright 2.4S | | 15 | 22 | Large Warm 1.75S
8 | 3 | Small Bright 0.3S | | 16 | 22 | Ditto

Note
To send all MIDI program numbers for a Config, go to PLAY mode with the machine stopped, then hold down PLAY and press RUN - this restarts all seqs and sends all 24 MIDI prog changes for the current Config.

USING THE DEMO MATERIAL

Cart 'A'
This is a single piece of music written by session keyboards player Alex
White. | It can be heard in its entirety by running Performance 1. | It uses
Configs 1 to 9 - these can be used individually in Play Mode to illustrate different aspects of the Trigger Profile, etc.

Cart 'B'
This consists of several distinct Configs put together by Pete Kellock of
Zyklus. | The Configs are arranged as follows:
1. General-purpose. | Seq 1 is assigned to 2 Control Keys (7 & 8) which is
useful for demonstrating the sequence synchronisation options (RESTART, ALIGN & REL QUANT).
2. Useful for illustrating asynchronous triggering from the Control Keys -almost anything works musically!
3. Using MPS as Control Station. | Use Control Keys 4 - 12 to illustrate Thru
routing to single & multiple destinations. | Put on CYCLE to show cyclic
routing and GROUP to show keyboard zoning.
4. Simple rhythmic seqs for illustrating external MIDI control options. With EXT TRIG on, can show aspects such as:
- triggering seq from single notes & chords
- building up multiple notes with BUILD on then collapsing back to 1

- control of seq velocity from keyboard
- behaviour with MOMentary on
- different seqs triggered from different pitches
- second level of transposition with TRANSPOSE on
- triggering several seqs simultaneously (set to flashing state then play a note on keyboard)
- CYCLE behaviour (set several to flashing state then play several notes)
- control from different zones with GROUP on
- control & transposition of drum parts (Control Keys 10 - 12)
5. Effects (Trigger all from single notes on keyboard):
- chords on Control Keys 1 & 2
- arpeggio effects on 3 - 6
- hold-at-end effects on 7 - 10
6. Effects (Trigger from notes & chords on keyboard. | Try different tempos.)
- rhythms on 1 - 3. | Try combining the rhythms.
- 'strumming' effect on 5 with Thru (for comparison) on 4
- 'chiff' effect on 7 with Thru (for comparison) on 6
7. Blank
8. Blank
9. Blank
10. Drum patterns. Some left blank for experimentation.
11. Config to illustrate use of GROUP, CYCLE & single-shot sequences.
12. Big orchestral chord. Play from single notes on keyboard.
13. General-purpose.
14. General-purpose.
15. 'Fanfare'. Useful for showing how sequences can be triggered against themselves at different times.
16. 'Spanish'. | Useful for showing STEP option.
17 - 24. | Unused.

Doc: ‘HAE’

KAL: USING HOLD-AT-END SEQS IN DEMO CART 28/2/88 ------------------------------------------- -------

There are 6 HAE examples in Config 20. Use these 1 at a time, playing

from single notes on the keyboard - the octave below middle C is best.

Show effect of keyboard velocity & of changing tempo.

For comparison you have Thru to the same sounds on Control Keys 7 - 12. This

lets you show what the MPS is contributing to the sound.

Note: All these sounds are on the MT32. It sometinmes gets confused with

its 'intelligent' voice-assignment - just play the HAE effect a couple of

times and it sorts itself out.

THE 'QUANTISATION BUG'

I think this happens when you record in real time with RESTART off - it's very

easy to get out of sync in this case. Normally RESTART goes on automatically

when you go into real-time record, but it doesn't if you have a Trigger Profile

defined in the current Config.

I'm altering this in software to make it more user-friendly. In the meantime,

always check that RESTART is on and RQ + ALIGN are off when recording in real

time.

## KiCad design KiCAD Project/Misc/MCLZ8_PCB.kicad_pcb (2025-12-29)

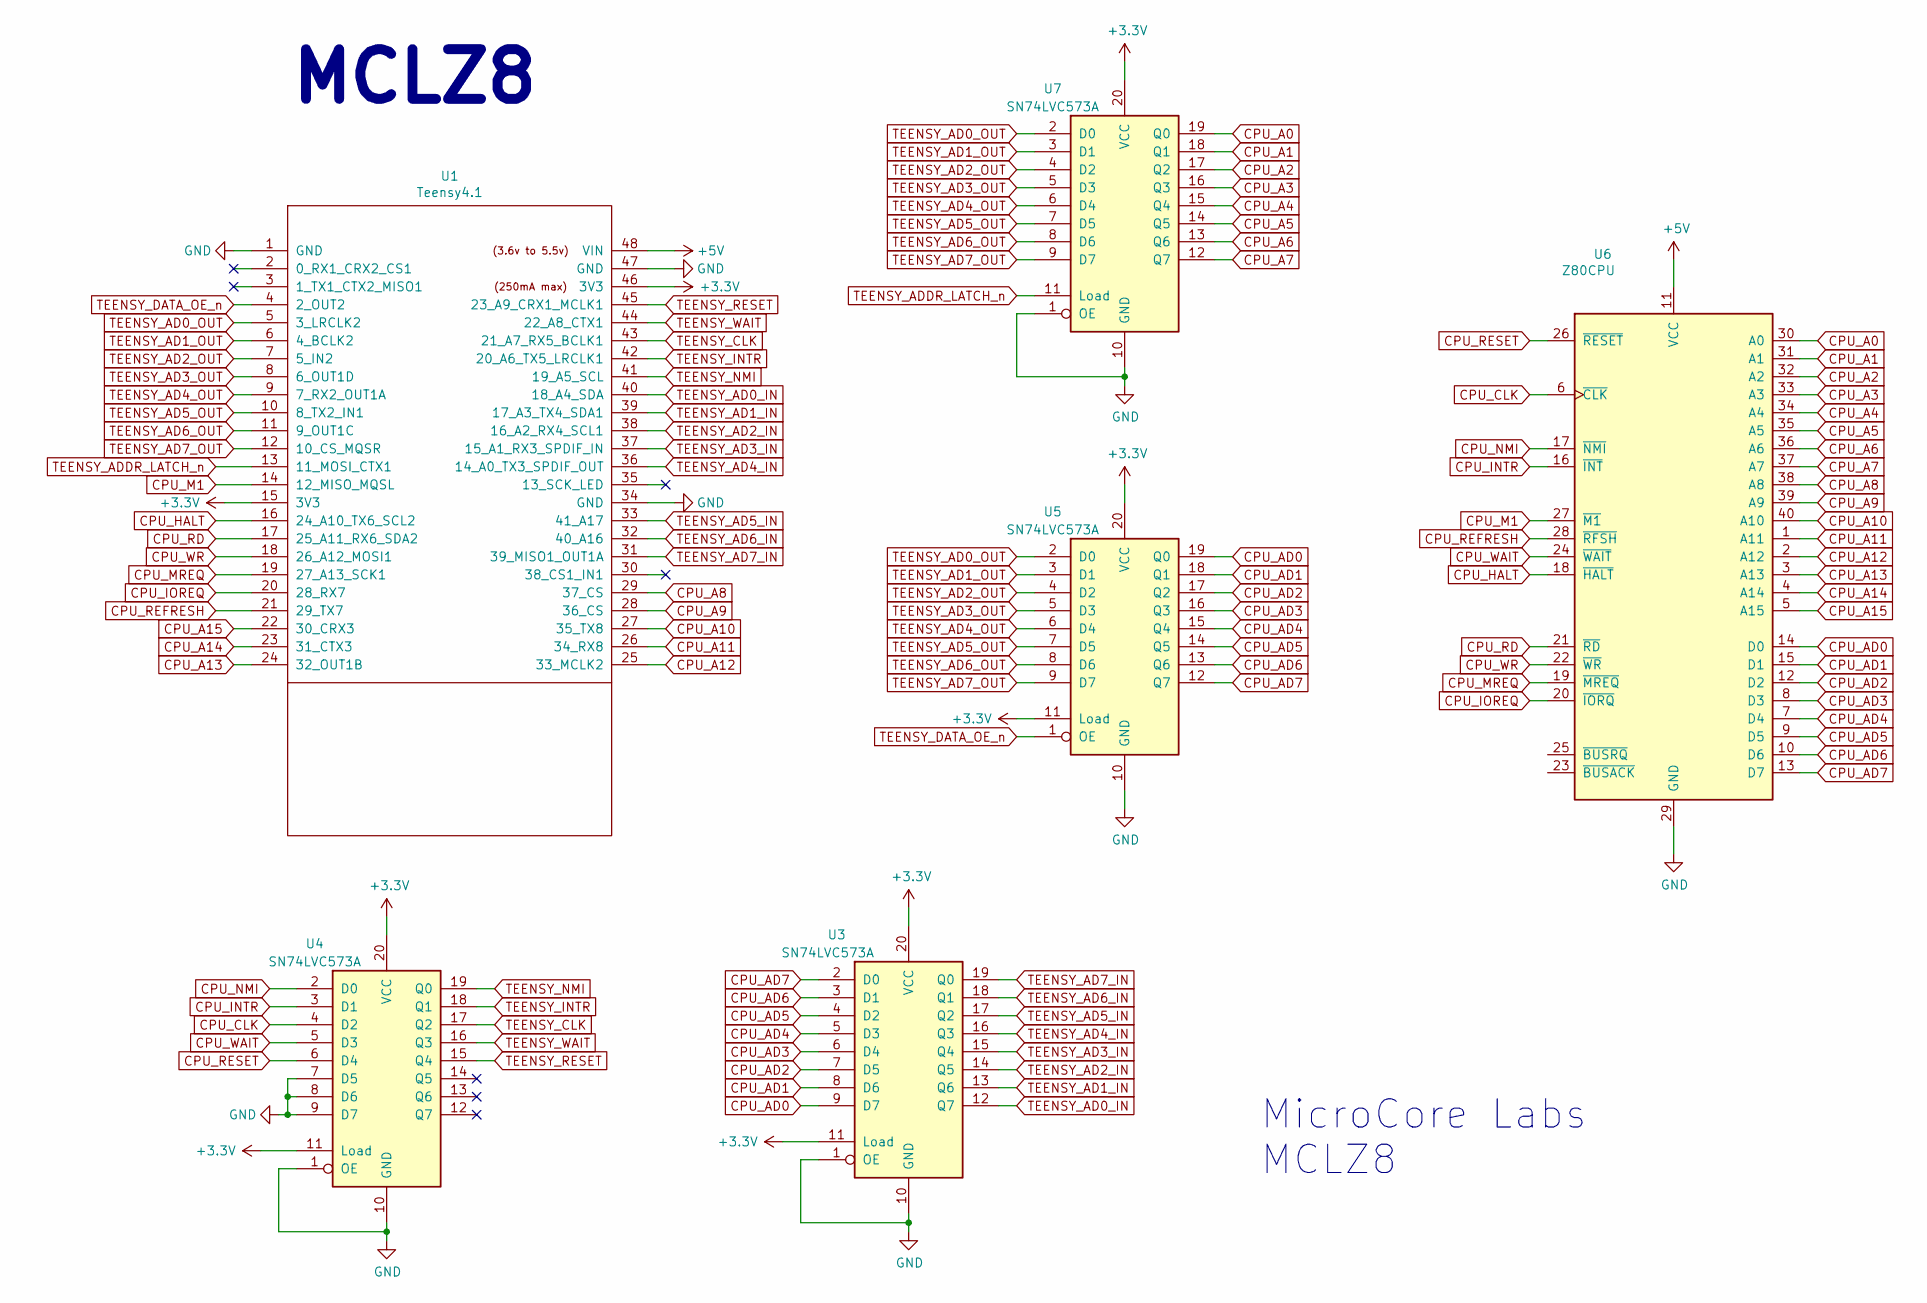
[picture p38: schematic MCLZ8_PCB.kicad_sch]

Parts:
U1: Teensy4.1; Teensy41_Ted_Modified
U3, U4, U5, U7: SN74LVC573A; TSSOP-20_4.4x6.5mm_P0.65mm
U6: Z80CPU; DIP-40_W15.24mm

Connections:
+3V3: U1.15 (3V3), U1.46 (3V3), U3.11 (Load), U3.20 (VCC), U4.11 (Load), U4.20 (VCC), U5.11 (Load), U5.20 (VCC), U7.20 (VCC)
+5V: U1.48 (VIN), U6.11 (VCC)
CPU_A0: U6.30 (A0), U7.19 (Q0)
CPU_A1: U6.31 (A1), U7.18 (Q1)
CPU_A2: U6.32 (A2), U7.17 (Q2)
CPU_A3: U6.33 (A3), U7.16 (Q3)
CPU_A4: U6.34 (A4), U7.15 (Q4)
CPU_A5: U6.35 (A5), U7.14 (Q5)
CPU_A6: U6.36 (A6), U7.13 (Q6)
CPU_A7: U6.37 (A7), U7.12 (Q7)
CPU_A8: U1.29 (37_CS), U6.38 (A8)
CPU_A9: U1.28 (36_CS), U6.39 (A9)
CPU_A10: U1.27 (35_TX8), U6.40 (A10)
CPU_A11: U1.26 (34_RX8), U6.1 (A11)
CPU_A12: U1.25 (33_MCLK2), U6.2 (A12)
CPU_A13: U1.24 (32_OUT1B), U6.3 (A13)
CPU_A14: U1.23 (31_CTX3), U6.4 (A14)
CPU_A15: U1.22 (30_CRX3), U6.5 (A15)
CPU_AD0: U3.9 (D7), U5.19 (Q0), U6.14 (D0)
CPU_AD1: U3.8 (D6), U5.18 (Q1), U6.15 (D1)
CPU_AD2: U3.7 (D5), U5.17 (Q2), U6.12 (D2)
CPU_AD3: U3.6 (D4), U5.16 (Q3), U6.8 (D3)
CPU_AD4: U3.5 (D3), U5.15 (Q4), U6.7 (D4)
CPU_AD5: U3.4 (D2), U5.14 (Q5), U6.9 (D5)
CPU_AD6: U3.3 (D1), U5.13 (Q6), U6.10 (D6)
CPU_AD7: U3.2 (D0), U5.12 (Q7), U6.13 (D7)
CPU_CLK: U4.4 (D2), U6.6 (~CLK)
CPU_HALT: U1.16 (24_A10_TX6_SCL2), U6.18 (~HALT)
CPU_INTR: U4.3 (D1), U6.16 (~INT)
CPU_IOREQ: U1.20 (28_RX7), U6.20 (~IORQ)
CPU_M1: U1.14 (12_MISO_MQSL), U6.27 (~M1)
CPU_MREQ: U1.19 (27_A13_SCK1), U6.19 (~MREQ)
CPU_NMI: U4.2 (D0), U6.17 (~NMI)
CPU_RD: U1.17 (25_A11_RX6_SDA2), U6.21 (~RD)
CPU_REFRESH: U1.21 (29_TX7), U6.28 (~RFSH)
CPU_RESET: U4.6 (D4), U6.26 (~RESET)
CPU_WAIT: U4.5 (D3), U6.24 (~WAIT)
CPU_WR: U1.18 (26_A12_MOSI1), U6.22 (~WR)
GND: U1.1 (GND), U1.34 (GND), U1.47 (GND), U3.1 (OE), U3.10 (GND), U4.1 (OE), U4.7 (D5), U4.8 (D6), U4.9 (D7), U4.10 (GND), U5.10 (GND), U6.29 (GND), U7.1 (OE), U7.10 (GND)
TEENSY_AD0_IN: U1.40 (18_A4_SDA), U3.12 (Q7)
TEENSY_AD0_OUT: U1.5 (3_LRCLK2), U5.2 (D0), U7.2 (D0)
TEENSY_AD1_IN: U1.39 (17_A3_TX4_SDA1), U3.13 (Q6)
TEENSY_AD1_OUT: U1.6 (4_BCLK2), U5.3 (D1), U7.3 (D1)
TEENSY_AD2_IN: U1.38 (16_A2_RX4_SCL1), U3.14 (Q5)
TEENSY_AD2_OUT: U1.7 (5_IN2), U5.4 (D2), U7.4 (D2)
TEENSY_AD3_IN: U1.37 (15_A1_RX3_SPDIF_IN), U3.15 (Q4)
TEENSY_AD3_OUT: U1.8 (6_OUT1D), U5.5 (D3), U7.5 (D3)
TEENSY_AD4_IN: U1.36 (14_A0_TX3_SPDIF_OUT), U3.16 (Q3)
TEENSY_AD4_OUT: U1.9 (7_RX2_OUT1A), U5.6 (D4), U7.6 (D4)
TEENSY_AD5_IN: U1.33 (41_A17), U3.17 (Q2)
TEENSY_AD5_OUT: U1.10 (8_TX2_IN1), U5.7 (D5), U7.7 (D5)
TEENSY_AD6_IN: U1.32 (40_A16), U3.18 (Q1)
TEENSY_AD6_OUT: U1.11 (9_OUT1C), U5.8 (D6), U7.8 (D6)
TEENSY_AD7_IN: U1.31 (39_MISO1_OUT1A), U3.19 (Q0)
TEENSY_AD7_OUT: U1.12 (10_CS_MQSR), U5.9 (D7), U7.9 (D7)
TEENSY_ADDR_LATCH_n: U1.13 (11_MOSI_CTX1), U7.11 (Load)
TEENSY_CLK: U1.43 (21_A7_RX5_BCLK1), U4.17 (Q2)
TEENSY_DATA_OE_n: U1.4 (2_OUT2), U5.1 (OE)
TEENSY_INTR: U1.42 (20_A6_TX5_LRCLK1), U4.18 (Q1)
TEENSY_NMI: U1.41 (19_A5_SCL), U4.19 (Q0)
TEENSY_RESET: U1.45 (23_A9_CRX1_MCLK1), U4.15 (Q4)
TEENSY_WAIT: U1.44 (22_A8_CTX1), U4.16 (Q3)

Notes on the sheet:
MicroCore Labs MCLZ8
MCLZ8

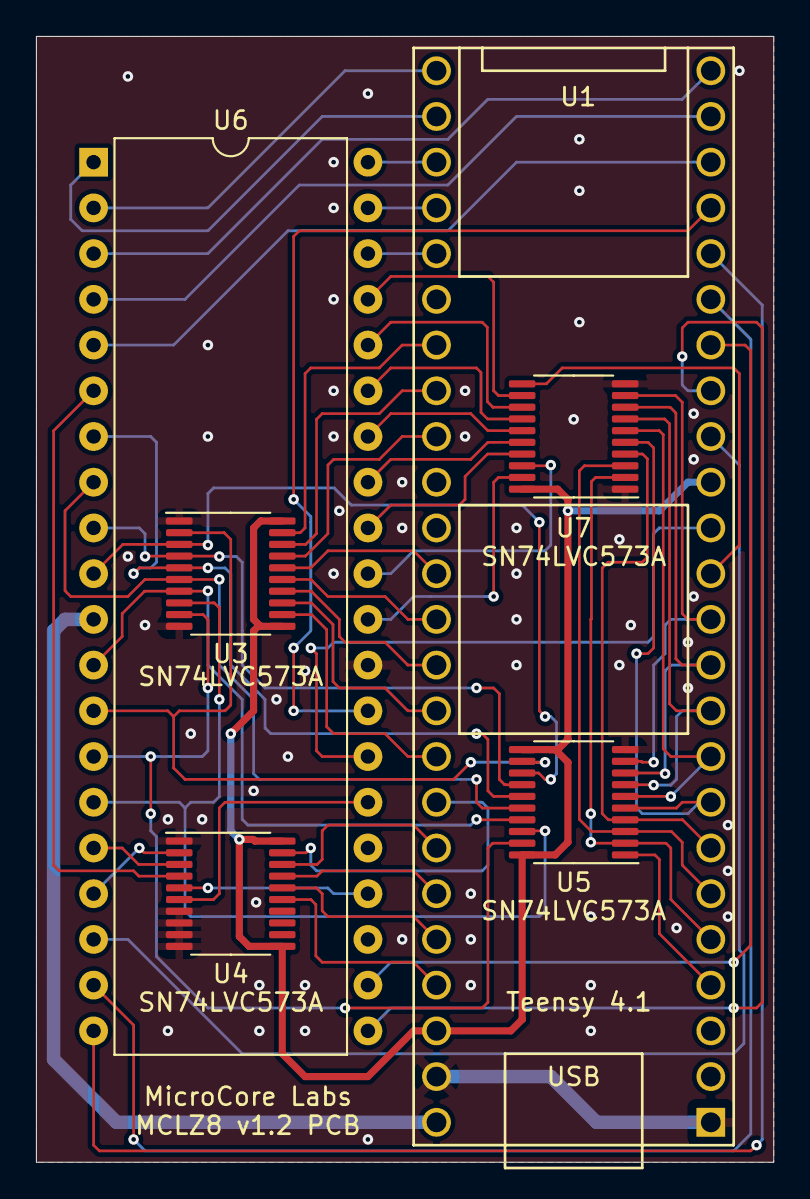
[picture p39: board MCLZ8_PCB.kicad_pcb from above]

Board: 2 copper layers, 41.0 x 62.5 mm, 6 parts (0 on the bottom side), 62 nets.

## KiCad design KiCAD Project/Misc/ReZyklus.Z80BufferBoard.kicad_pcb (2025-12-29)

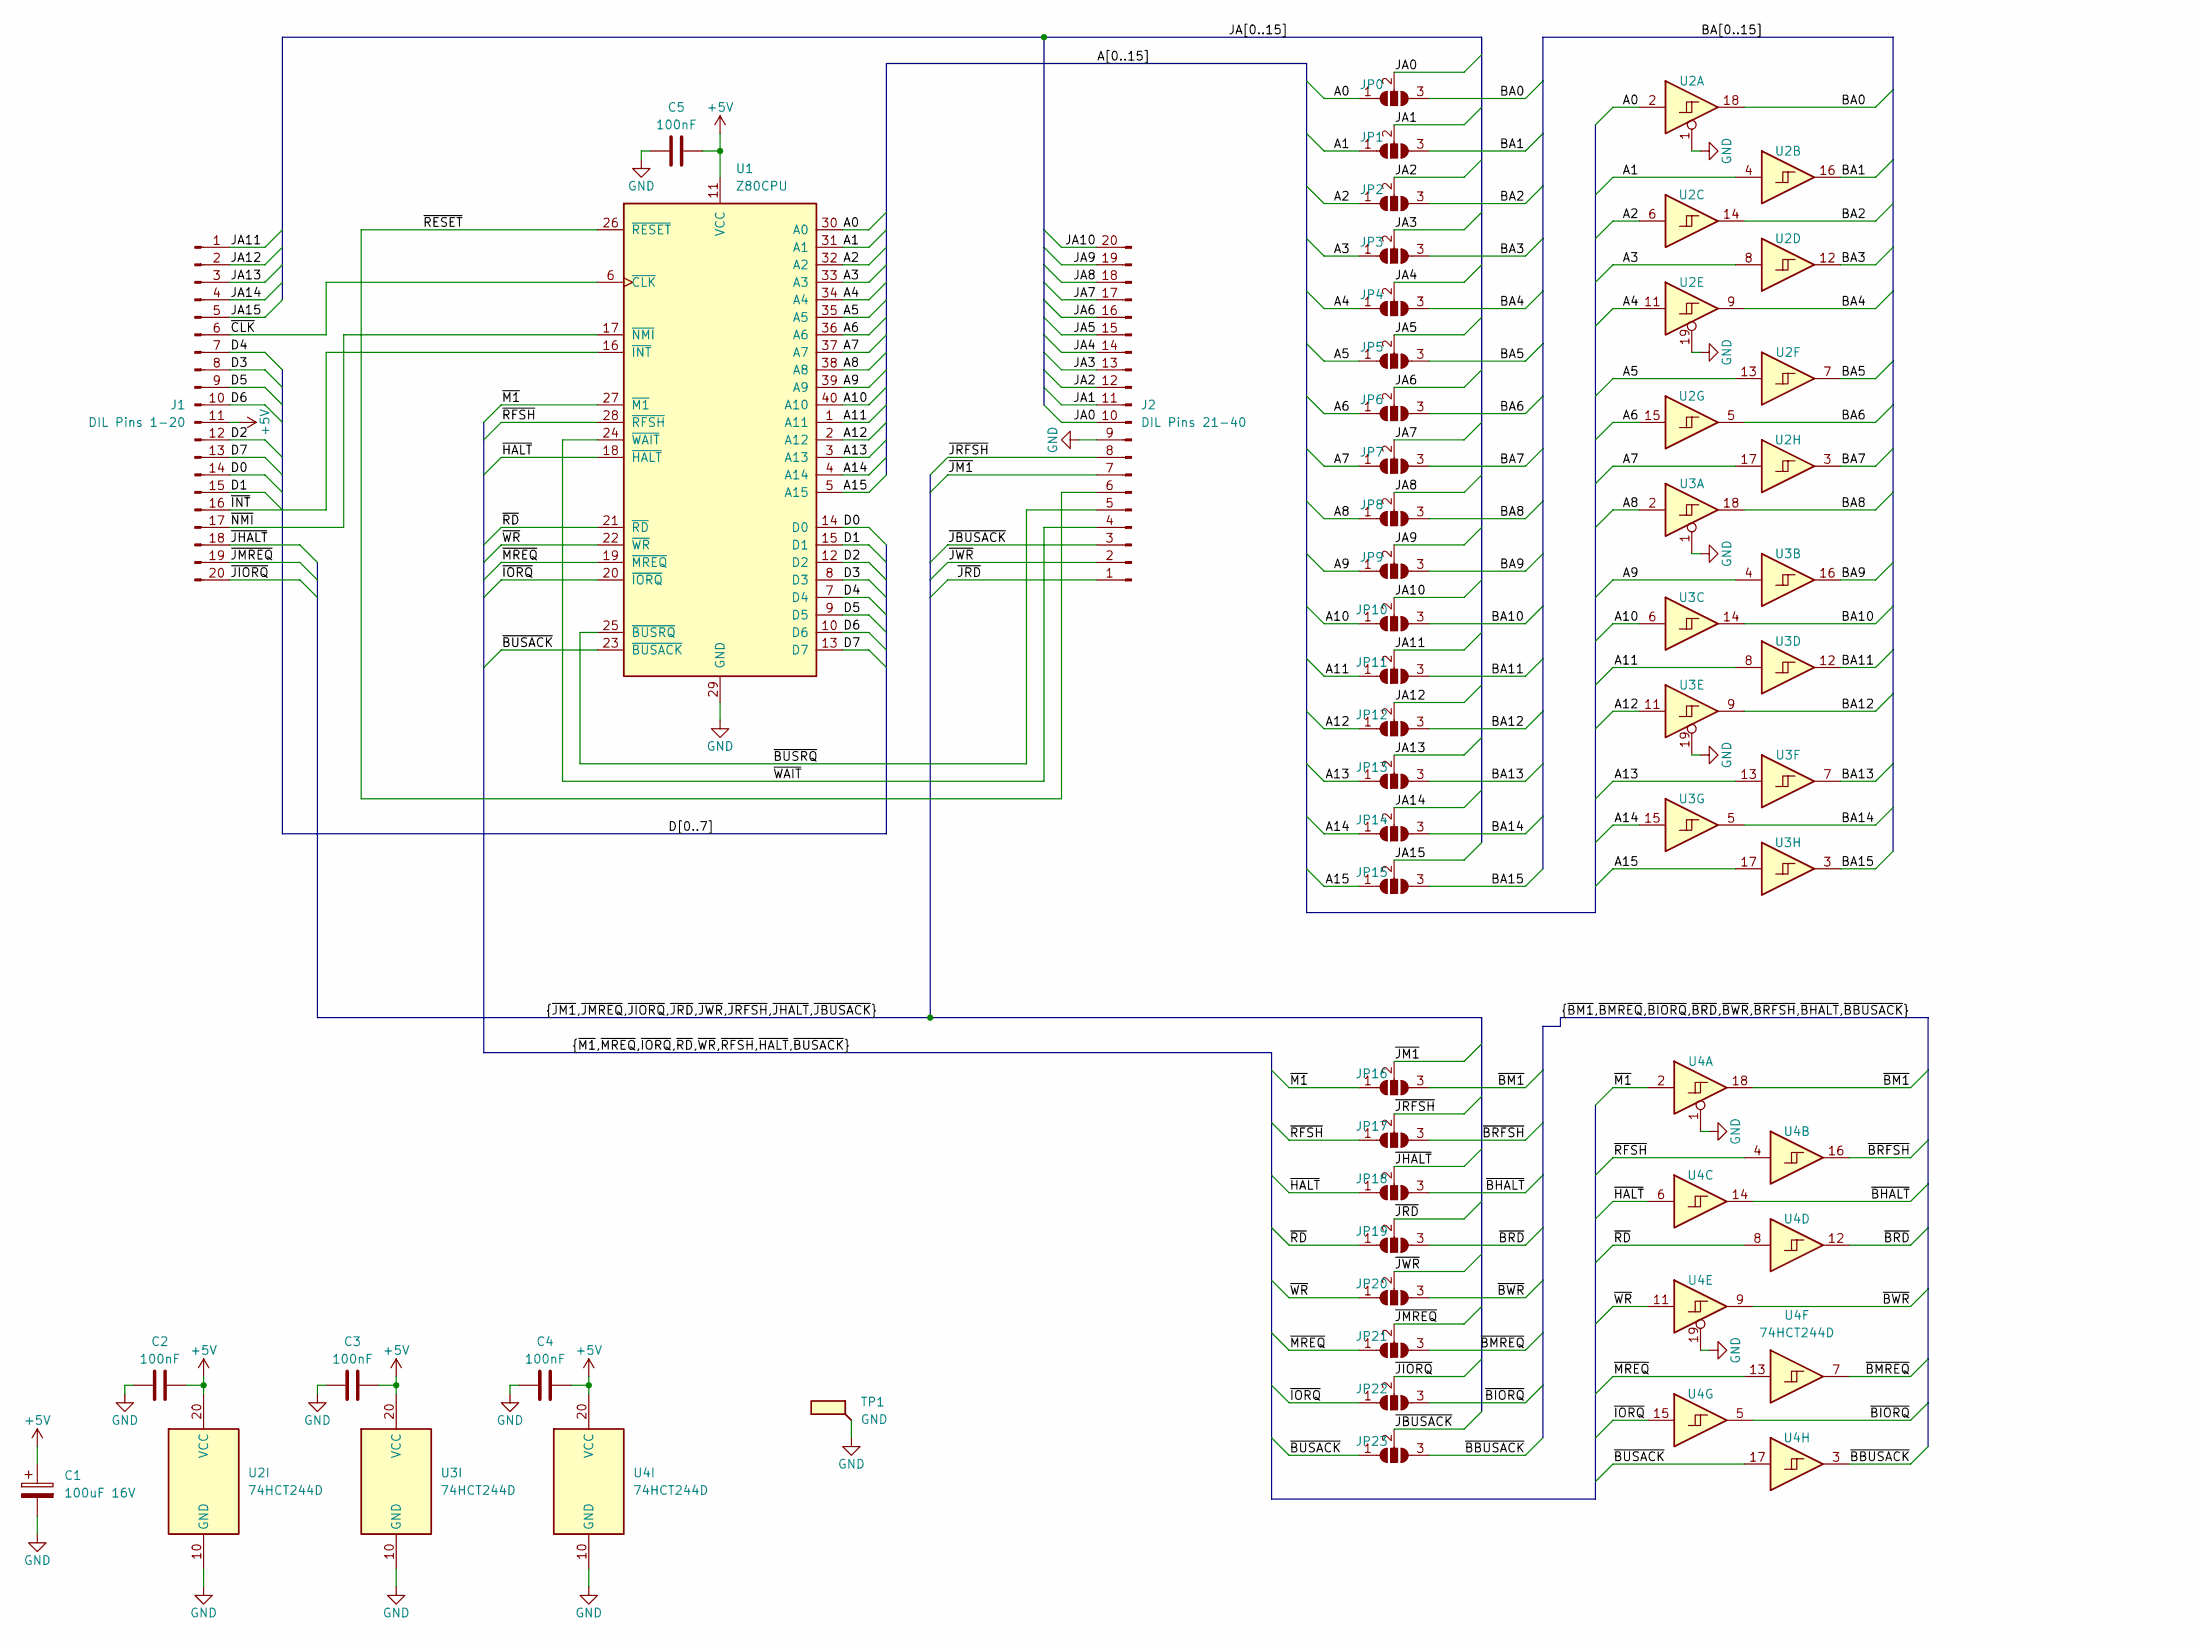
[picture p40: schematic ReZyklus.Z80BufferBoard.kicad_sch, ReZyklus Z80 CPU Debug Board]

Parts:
C1: 100uF 16V; CP_Elec_5x5.4
C2, C3, C4, C5: 100nF; C_0805_2012Metric_Pad1.18x1.45mm_HandSolder
J1: DIL Pins 1-20; PinHeader_1x20_P2.54mm_Vertical
J2: DIL Pins 21-40; PinHeader_1x20_P2.54mm_Vertical
JP0: A0; SolderJumper-3_P1.3mm_Open_RoundedPad1.0x1.5mm_NumberLabels
JP1: A1; SolderJumper-3_P1.3mm_Open_RoundedPad1.0x1.5mm_NumberLabels
JP2: A2; SolderJumper-3_P1.3mm_Open_RoundedPad1.0x1.5mm_NumberLabels
JP3: A3; SolderJumper-3_P1.3mm_Open_RoundedPad1.0x1.5mm_NumberLabels
JP4: A4; SolderJumper-3_P1.3mm_Open_RoundedPad1.0x1.5mm_NumberLabels
JP5: A5; SolderJumper-3_P1.3mm_Open_RoundedPad1.0x1.5mm_NumberLabels
JP6: A6; SolderJumper-3_P1.3mm_Open_RoundedPad1.0x1.5mm_NumberLabels
JP7: A7; SolderJumper-3_P1.3mm_Open_RoundedPad1.0x1.5mm_NumberLabels
JP8: A8; SolderJumper-3_P1.3mm_Open_RoundedPad1.0x1.5mm_NumberLabels
JP9: A9; SolderJumper-3_P1.3mm_Open_RoundedPad1.0x1.5mm_NumberLabels
JP10: A10; SolderJumper-3_P1.3mm_Open_RoundedPad1.0x1.5mm_NumberLabels
JP11: A11; SolderJumper-3_P1.3mm_Open_RoundedPad1.0x1.5mm_NumberLabels
JP12: A12; SolderJumper-3_P1.3mm_Open_RoundedPad1.0x1.5mm_NumberLabels
JP13: A13; SolderJumper-3_P1.3mm_Open_RoundedPad1.0x1.5mm_NumberLabels
JP14: A14; SolderJumper-3_P1.3mm_Open_RoundedPad1.0x1.5mm_NumberLabels
JP15: A15; SolderJumper-3_P1.3mm_Open_RoundedPad1.0x1.5mm_NumberLabels
JP16: ~{M1}; SolderJumper-3_P1.3mm_Open_RoundedPad1.0x1.5mm_NumberLabels
JP17: ~{RFSH}; SolderJumper-3_P1.3mm_Open_RoundedPad1.0x1.5mm_NumberLabels
JP18: ~{HALT}; SolderJumper-3_P1.3mm_Open_RoundedPad1.0x1.5mm_NumberLabels
JP19: ~{BRD}; SolderJumper-3_P1.3mm_Open_RoundedPad1.0x1.5mm_NumberLabels
JP20: ~{BWR}; SolderJumper-3_P1.3mm_Open_RoundedPad1.0x1.5mm_NumberLabels
JP21: ~{MREQ}; SolderJumper-3_P1.3mm_Open_RoundedPad1.0x1.5mm_NumberLabels
JP22: ~{IORQ}; SolderJumper-3_P1.3mm_Open_RoundedPad1.0x1.5mm_NumberLabels
JP23: ~{BUSACK}; SolderJumper-3_P1.3mm_Open_RoundedPad1.0x1.5mm_NumberLabels
TP1: GND; TestPoint_THTPad_2.5x2.5mm_Drill1.2mm
U1: Z80CPU; DIP-40_W15.24mm_Socket_LongPads
U2, U3, U4: 74HCT244D; SO-20_12.8x7.5mm_P1.27mm

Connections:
+5V: C1.1, C2.2, C3.2, C4.2, C5.2, J1.11, U1.11 (VCC), U2.20 (VCC), U3.20 (VCC), U4.20 (VCC)
/A0: JP0.1 (A), U1.30 (A0), U2.2
/A1: JP1.1 (A), U1.31 (A1), U2.4
/A2: JP2.1 (A), U1.32 (A2), U2.6
/A3: JP3.1 (A), U1.33 (A3), U2.8
/A4: JP4.1 (A), U1.34 (A4), U2.11
/A5: JP5.1 (A), U1.35 (A5), U2.13
/A6: JP6.1 (A), U1.36 (A6), U2.15
/A7: JP7.1 (A), U1.37 (A7), U2.17
/A8: JP8.1 (A), U1.38 (A8), U3.2
/A9: JP9.1 (A), U1.39 (A9), U3.4
/A10: JP10.1 (A), U1.40 (A10), U3.6
/A11: JP11.1 (A), U1.1 (A11), U3.8
/A12: JP12.1 (A), U1.2 (A12), U3.11
/A13: JP13.1 (A), U1.3 (A13), U3.13
/A14: JP14.1 (A), U1.4 (A14), U3.15
/A15: JP15.1 (A), U1.5 (A15), U3.17
/BA0: JP0.3 (B), U2.18
/BA1: JP1.3 (B), U2.16
/BA2: JP2.3 (B), U2.14
/BA3: JP3.3 (B), U2.12
/BA4: JP4.3 (B), U2.9
/BA5: JP5.3 (B), U2.7
/BA6: JP6.3 (B), U2.5
/BA7: JP7.3 (B), U2.3
/BA8: JP8.3 (B), U3.18
/BA9: JP9.3 (B), U3.16
/BA10: JP10.3 (B), U3.14
/BA11: JP11.3 (B), U3.12
/BA12: JP12.3 (B), U3.9
/BA13: JP13.3 (B), U3.7
/BA14: JP14.3 (B), U3.5
/BA15: JP15.3 (B), U3.3
/D0: J1.14, U1.14 (D0)
/D1: J1.15, U1.15 (D1)
/D2: J1.12, U1.12 (D2)
/D3: J1.8, U1.8 (D3)
/D4: J1.7, U1.7 (D4)
/D5: J1.9, U1.9 (D5)
/D6: J1.10, U1.10 (D6)
/D7: J1.13, U1.13 (D7)
/JA0: J2.10, JP0.2 (C)
/JA1: J2.11, JP1.2 (C)
/JA2: J2.12, JP2.2 (C)
/JA3: J2.13, JP3.2 (C)
/JA4: J2.14, JP4.2 (C)
/JA5: J2.15, JP5.2 (C)
/JA6: J2.16, JP6.2 (C)
/JA7: J2.17, JP7.2 (C)
/JA8: J2.18, JP8.2 (C)
/JA9: J2.19, JP9.2 (C)
/JA10: J2.20, JP10.2 (C)
/JA11: J1.1, JP11.2 (C)
/JA12: J1.2, JP12.2 (C)
/JA13: J1.3, JP13.2 (C)
/JA14: J1.4, JP14.2 (C)
/JA15: J1.5, JP15.2 (C)
/~BBUSACK: JP23.3 (B), U4.3
/~BHALT: JP18.3 (B), U4.14
/~BIORQ: JP22.3 (B), U4.5
/~BM1: JP16.3 (B), U4.18
/~BMREQ: JP21.3 (B), U4.7
/~BRD: JP19.3 (B), U4.12
/~BRFSH: JP17.3 (B), U4.16
/~BUSACK: JP23.1 (A), U1.23 (~BUSACK), U4.17
/~BUSRQ: J2.5, U1.25 (~BUSRQ)
/~BWR: JP20.3 (B), U4.9
/~CLK: J1.6, U1.6 (~CLK)
/~HALT: JP18.1 (A), U1.18 (~HALT), U4.6
/~INT: J1.16, U1.16 (~INT)
/~IORQ: JP22.1 (A), U1.20 (~IORQ), U4.15
/~JBUSACK: J2.3, JP23.2 (C)
/~JHALT: J1.18, JP18.2 (C)
/~JIORQ: J1.20, JP22.2 (C)
/~JM1: J2.7, JP16.2 (C)
/~JMREQ: J1.19, JP21.2 (C)
/~JRD: J2.1, JP19.2 (C)
/~JRFSH: J2.8, JP17.2 (C)
/~JWR: J2.2, JP20.2 (C)
/~M1: JP16.1 (A), U1.27 (~M1), U4.2
/~MREQ: JP21.1 (A), U1.19 (~MREQ), U4.13
/~NMI: J1.17, U1.17 (~NMI)
/~RD: JP19.1 (A), U1.21 (~RD), U4.8
/~RESET: J2.6, U1.26 (~RESET)
/~RFSH: JP17.1 (A), U1.28 (~RFSH), U4.4
/~WAIT: J2.4, U1.24 (~WAIT)
/~WR: JP20.1 (A), U1.22 (~WR), U4.11
GND: C1.2, C2.1, C3.1, C4.1, C5.1, J2.9, TP1.1, U1.29 (GND), U2.1, U2.10 (GND), U2.19, U3.1, U3.10 (GND), U3.19, U4.1, U4.10 (GND), U4.19

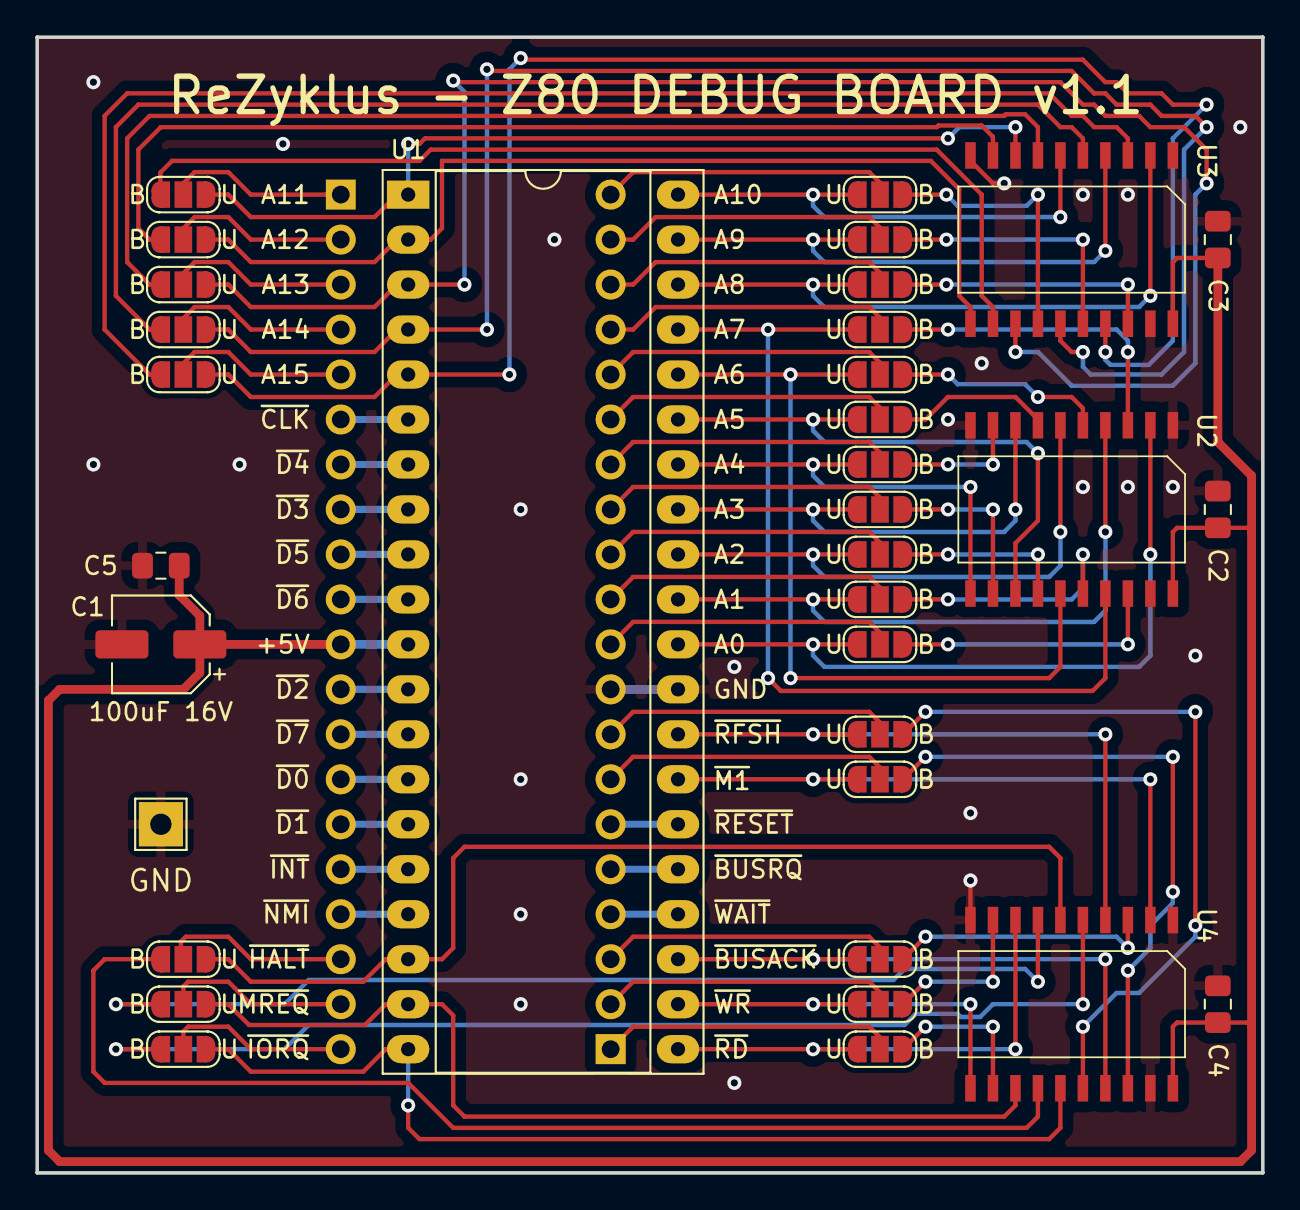
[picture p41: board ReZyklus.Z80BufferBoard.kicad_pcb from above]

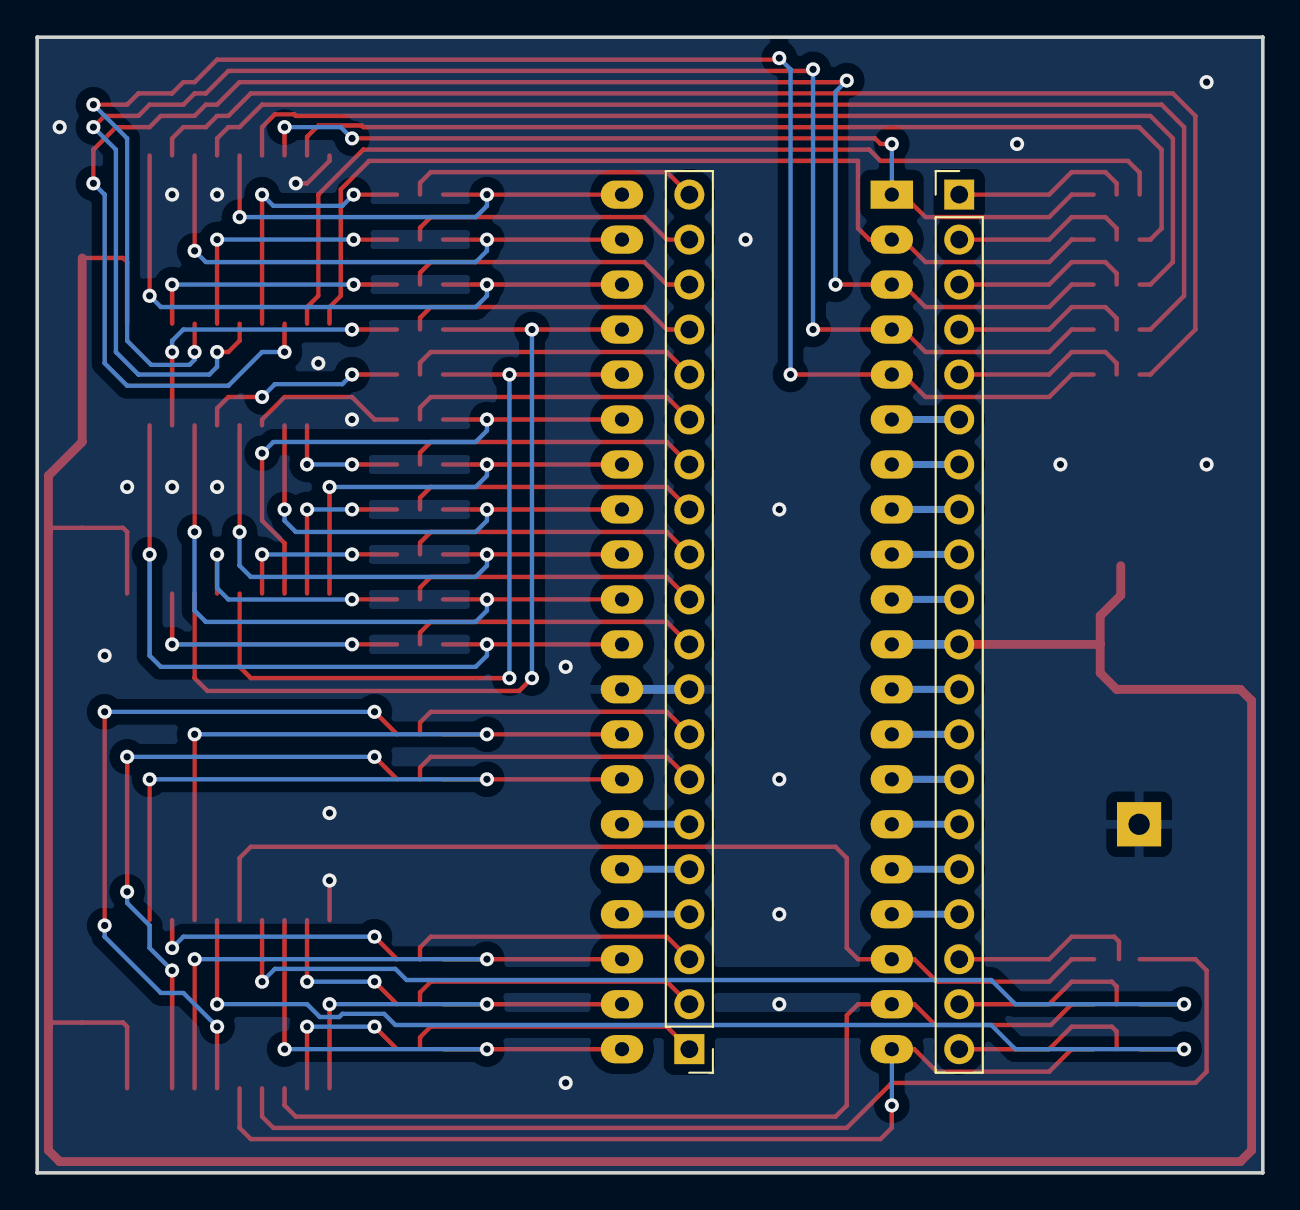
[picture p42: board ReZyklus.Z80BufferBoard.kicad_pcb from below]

Board: 2 copper layers, 69.2 x 64.1 mm, 36 parts (2 on the bottom side), 88 nets.

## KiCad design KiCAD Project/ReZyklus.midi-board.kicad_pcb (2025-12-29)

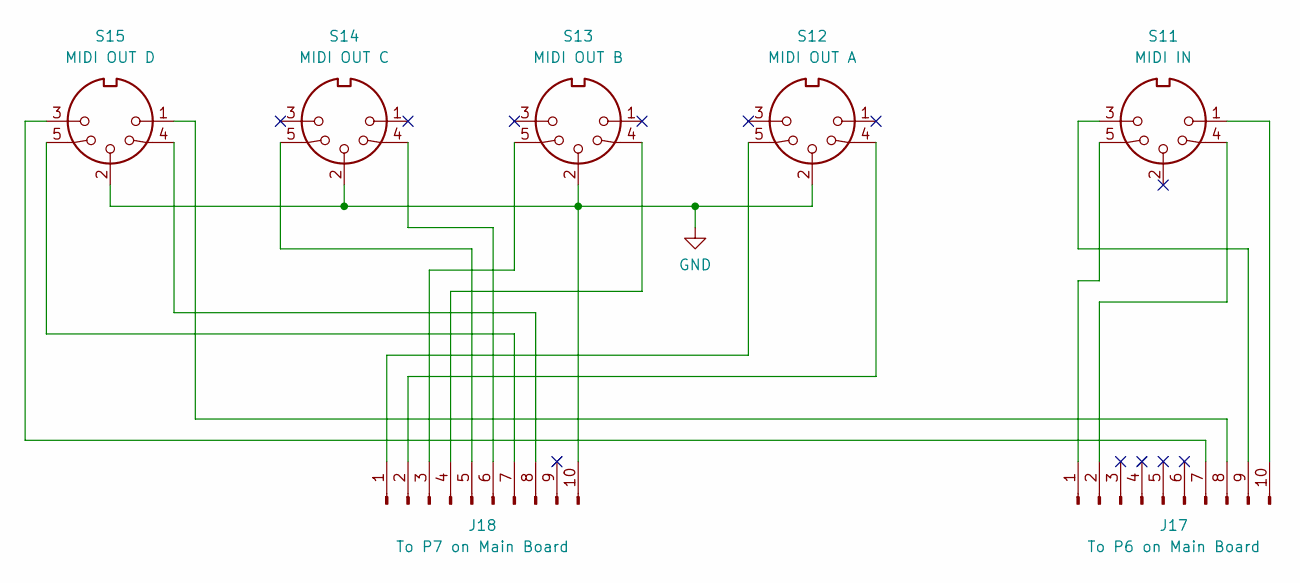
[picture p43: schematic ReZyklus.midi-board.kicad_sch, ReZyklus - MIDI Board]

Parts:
J17: To P6 on Main Board; Molex_KK-254_AE-6410-10A_1x10_P2.54mm_Vertical
J18: To P7 on Main Board; Molex_KK-254_AE-6410-10A_1x10_P2.54mm_Vertical
S11: MIDI IN; 5-Pin DIN Wired
S12: MIDI OUT A; 5-Pin DIN Wired
S13: MIDI OUT B; 5-Pin DIN Wired
S14: MIDI OUT C; 5-Pin DIN Wired
S15: MIDI OUT D; 5-Pin DIN Wired

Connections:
GND: J18.10, S12.2, S13.2, S14.2, S15.2
unnamed: J17.1, S11.5
unnamed: J17.2, S11.4
unnamed: J17.7, S15.3
unnamed: J17.8, S15.1
unnamed: J17.9, S11.3
unnamed: J17.10, S11.1
unnamed: J18.1, S12.5
unnamed: J18.2, S12.4
unnamed: J18.3, S13.5
unnamed: J18.4, S13.4
unnamed: J18.5, S14.5
unnamed: J18.6, S14.4
unnamed: J18.7, S15.5
unnamed: J18.8, S15.4

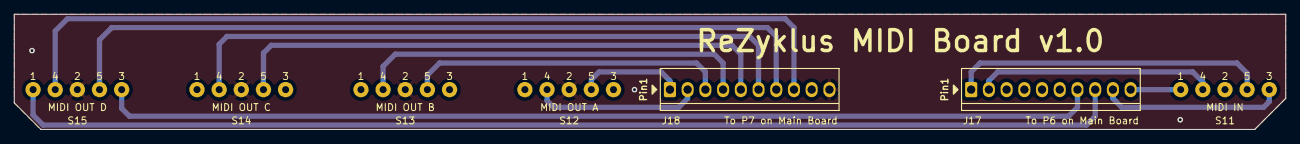
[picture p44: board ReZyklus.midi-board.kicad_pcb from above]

Board: 2 copper layers, 182.2 x 16.5 mm, 7 parts (0 on the bottom side), 15 nets.

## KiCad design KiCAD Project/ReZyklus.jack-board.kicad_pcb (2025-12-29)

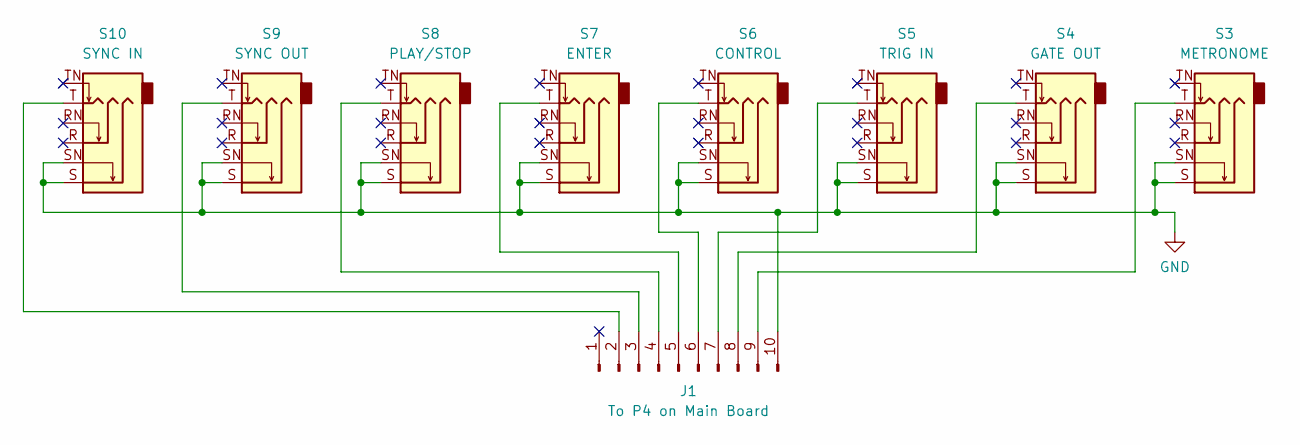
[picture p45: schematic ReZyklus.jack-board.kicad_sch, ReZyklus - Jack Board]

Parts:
J1: To P4 on Main Board; Molex_KK-254_AE-6410-10A_1x10_P2.54mm_Vertical
S3: METRONOME; Jack_6.35mm_Neutrik_NMJ6HFD2_Horizontal
S4: GATE OUT; Jack_6.35mm_Neutrik_NMJ6HFD2_Horizontal
S5: TRIG IN; Jack_6.35mm_Neutrik_NMJ6HFD2_Horizontal
S6: CONTROL; Jack_6.35mm_Neutrik_NMJ6HFD2_Horizontal
S7: ENTER; Jack_6.35mm_Neutrik_NMJ6HFD2_Horizontal
S8: PLAY/STOP; Jack_6.35mm_Neutrik_NMJ6HFD2_Horizontal
S9: SYNC OUT; Jack_6.35mm_Neutrik_NMJ6HFD2_Horizontal
S10: SYNC IN; Jack_6.35mm_Neutrik_NMJ6HFD2_Horizontal

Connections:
GND: J1.10, S3.S, S3.SN, S4.S, S4.SN, S5.S, S5.SN, S6.S, S6.SN, S7.S, S7.SN, S8.S, S8.SN, S9.S, S9.SN, S10.S, S10.SN
unnamed: J1.2, S10.T
unnamed: J1.3, S9.T
unnamed: J1.4, S8.T
unnamed: J1.5, S7.T
unnamed: J1.6, S6.T
unnamed: J1.7, S5.T
unnamed: J1.8, S4.T
unnamed: J1.9, S3.T

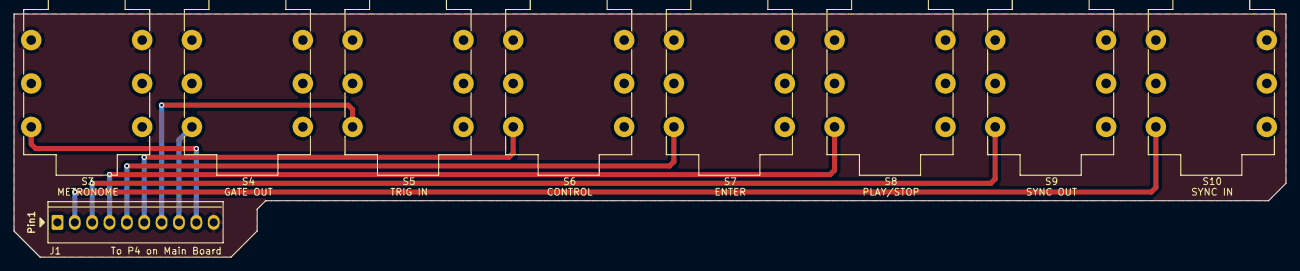
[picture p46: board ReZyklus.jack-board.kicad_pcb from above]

Board: 2 copper layers, 186.1 x 35.6 mm, 9 parts (0 on the bottom side), 9 nets.

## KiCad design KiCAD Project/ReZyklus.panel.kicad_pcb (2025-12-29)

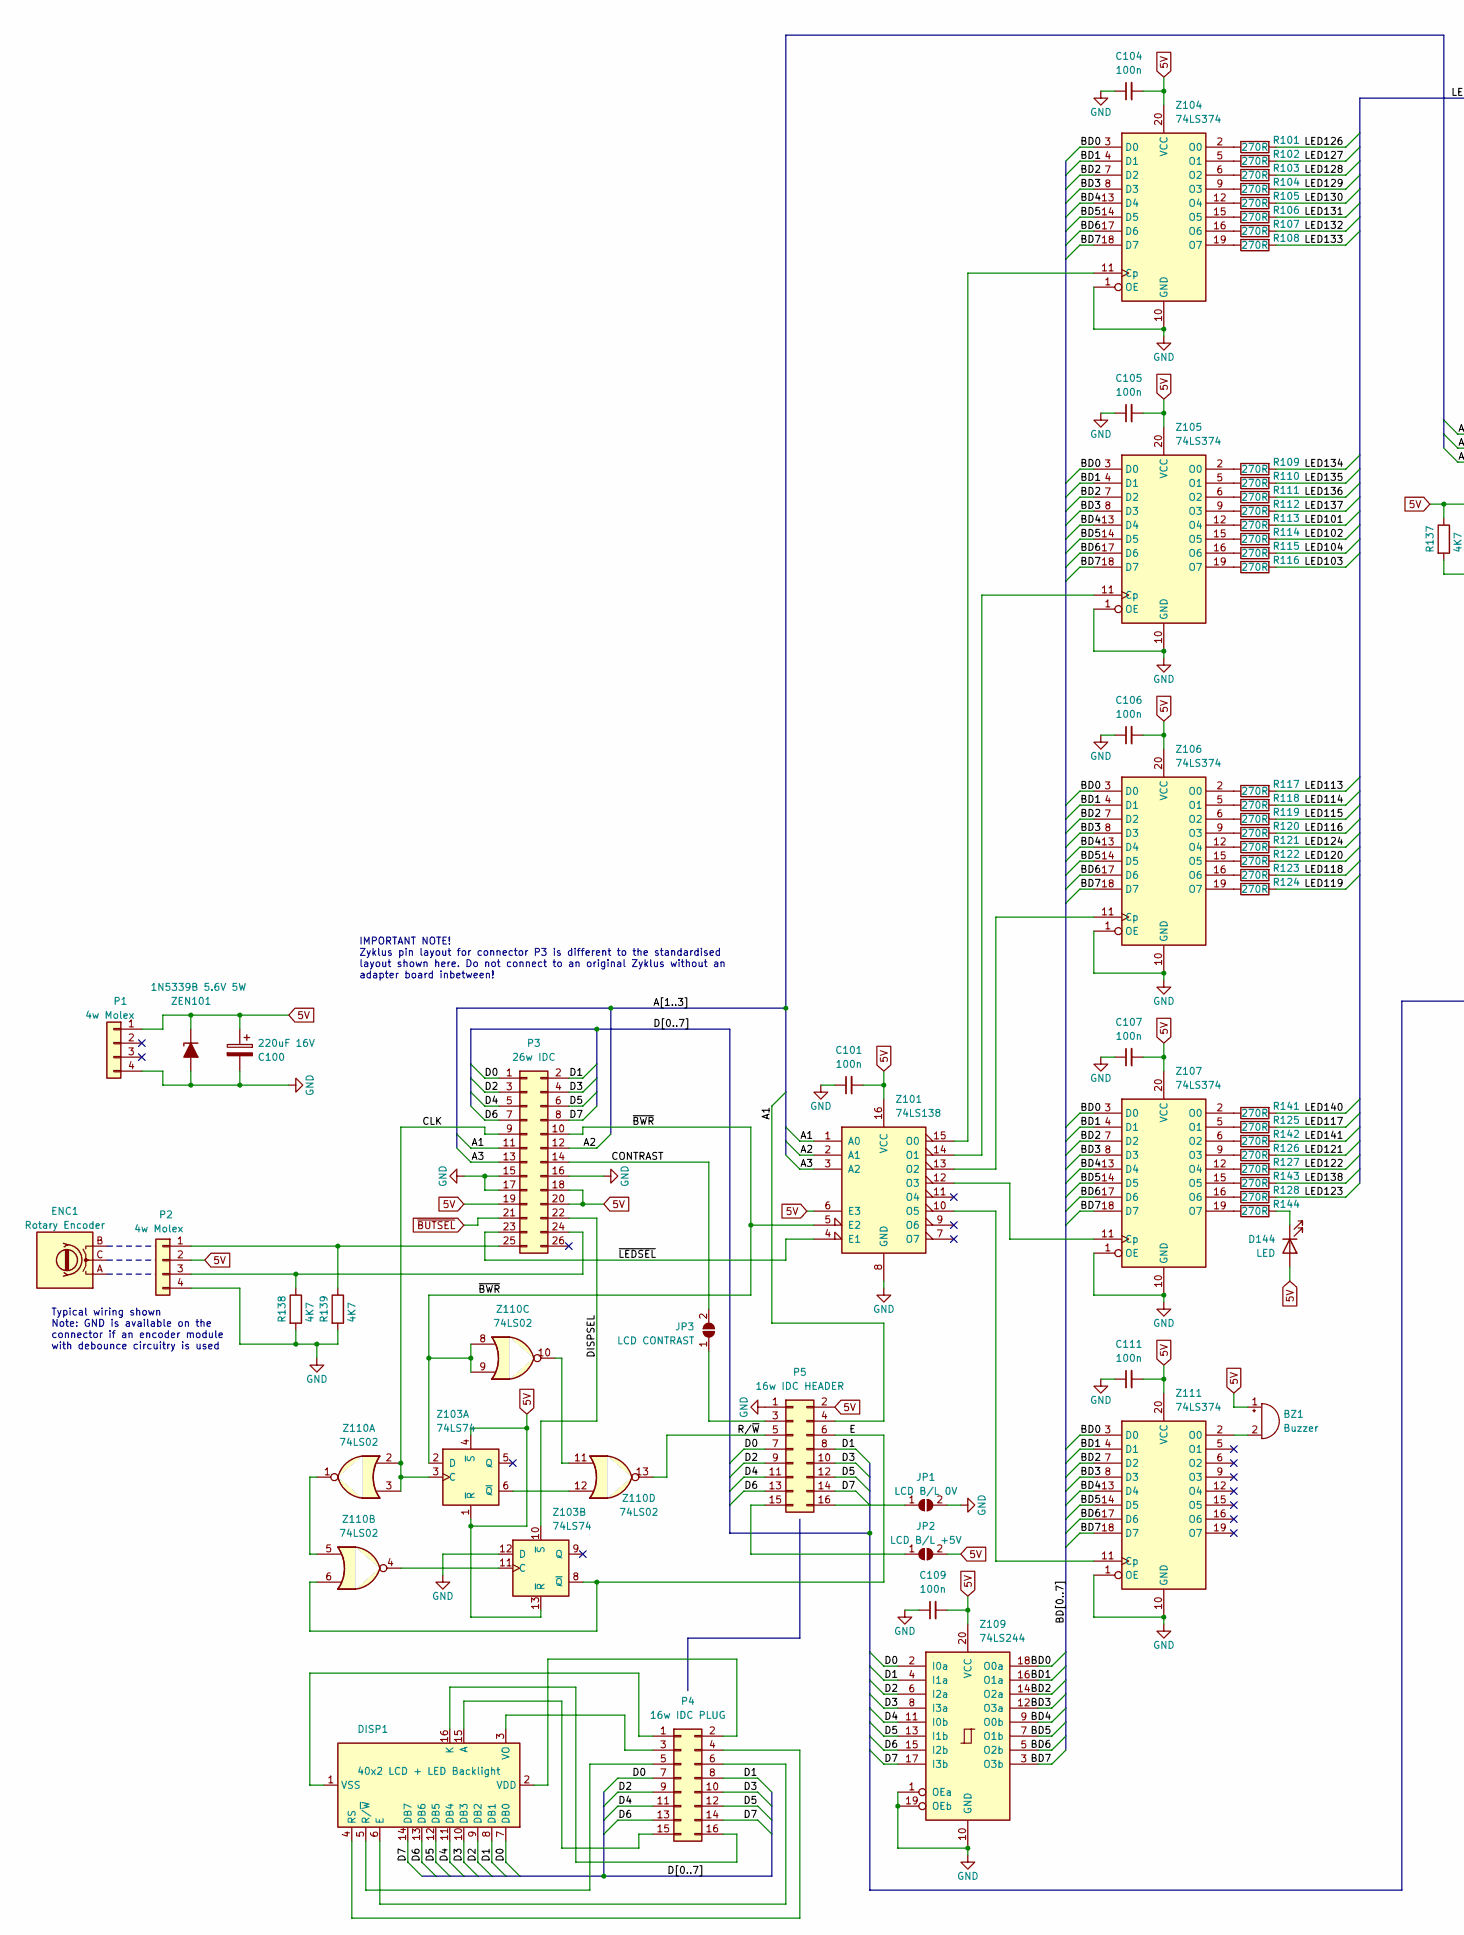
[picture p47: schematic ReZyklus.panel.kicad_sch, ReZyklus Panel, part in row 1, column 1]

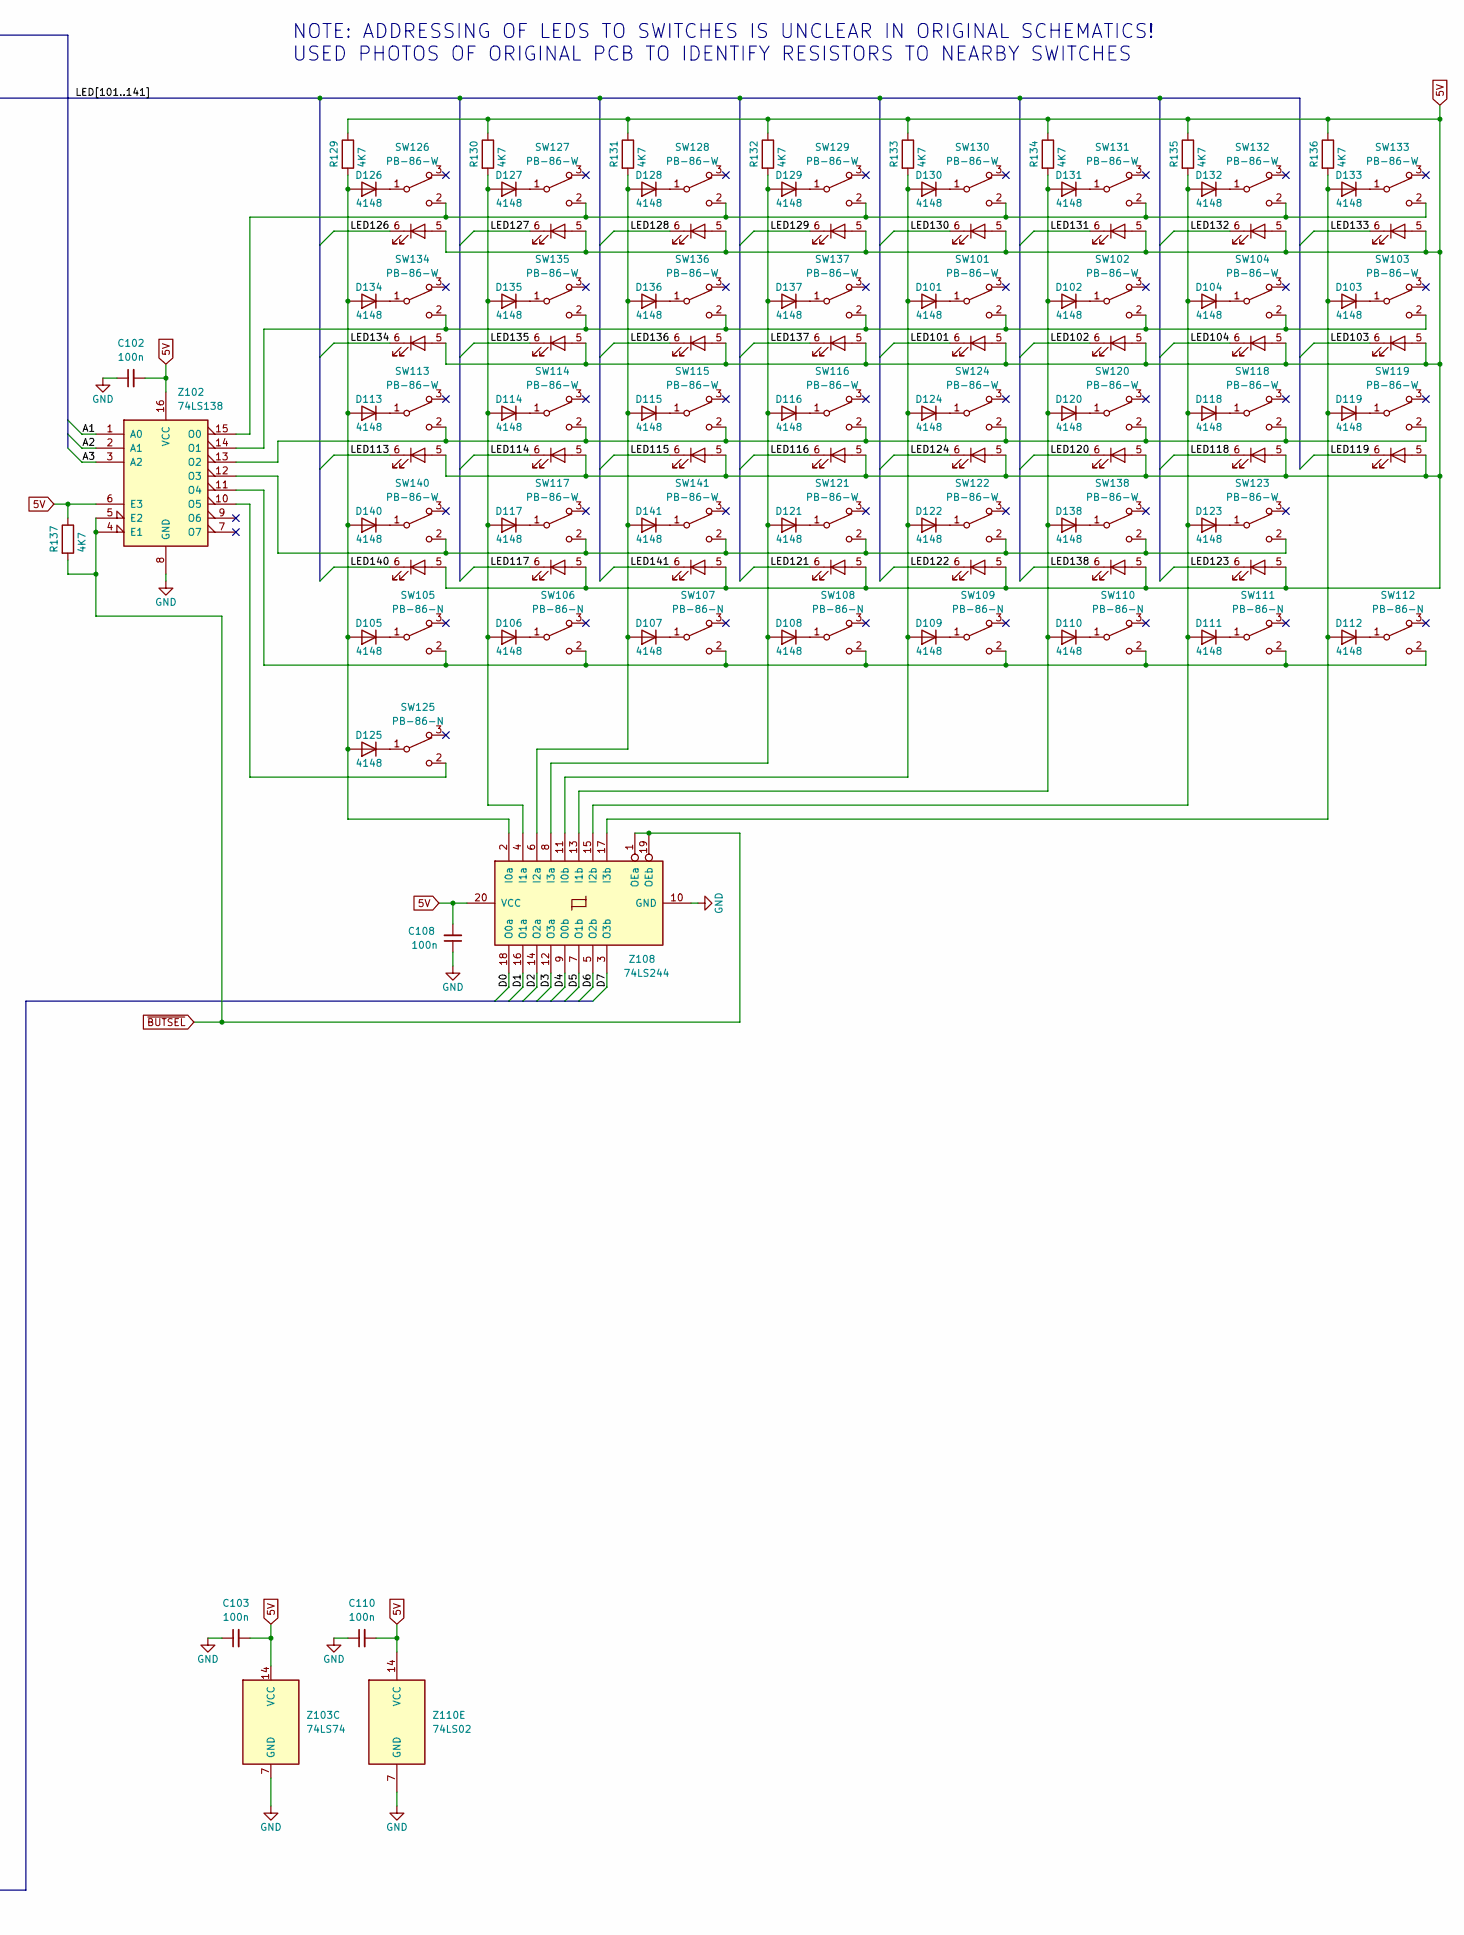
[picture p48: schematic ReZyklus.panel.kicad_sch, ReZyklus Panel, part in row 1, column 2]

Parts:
BZ1: Buzzer; Buzzer_12x9.5RM7.6
C100: 220uF 16V; CP_Radial_D8.0mm_P3.50mm
C101, C102, C103, C104, C105, C106, C107, C108, C109, C110, C111: 100n; C_Rect_L7.0mm_W2.5mm_P5.00mm
D101, D102, D103, D104, D105, D106, D107, D108, D109, D110, D111, D112, D113, D114, D115, D116, D117, D118, D119, D120, D121, D122, D123, D124, D125, D126, D127, D128, D129, D130, D131, D132, D133, D134, D135, D136, D137, D138, D140, D141: 4148; D_DO-35_SOD27_P7.62mm_Horizontal
D144: LED; LED_D5.0mm
DISP1: 40x2 LCD + LED Backlight
ENC1: Rotary Encoder; RotaryEncoder_Alps_EC12E_Vertical_H20mm
JP1: LCD B/L 0V; SolderJumper-2_P1.3mm_Open_RoundedPad1.0x1.5mm
JP2: LCD B/L +5V; SolderJumper-2_P1.3mm_Open_RoundedPad1.0x1.5mm
JP3: LCD CONTRAST; SolderJumper-2_P1.3mm_Open_RoundedPad1.0x1.5mm
P1: 4w Molex; Molex_KK-396_5273-04A_1x04_P3.96mm_Vertical
P2: 4w Molex; JST_XA_B04B-XASK-1_1x04_P2.50mm_Vertical
P3: 26w IDC; IDC-Header_2x13_P2.54mm_Latch_Vertical
P4: 16w IDC PLUG
P5: 16w IDC HEADER; IDC-Header_2x08_P2.54mm_Vertical
R101, R102, R103, R104, R105, R106, R107, R108, R109, R110, R111, R112, R113, R114, R115, R116, R117, R118, R119, R120, R121, R122, R123, R124, R125, R126, R127, R128, R141, R142, R143, R144: 270R; R_Axial_DIN0207_L6.3mm_D2.5mm_P10.16mm_Horizontal
R129, R130, R131, R132, R133, R134, R135, R136, R137, R138, R139: 4K7; R_Axial_DIN0207_L6.3mm_D2.5mm_P10.16mm_Horizontal
SW101, SW102, SW103, SW104, SW113, SW114, SW115, SW116, SW117, SW118, SW119, SW120, SW121, SW122, SW123, SW124, SW126, SW127, SW128, SW129, SW130, SW131, SW132, SW133, SW134, SW135, SW136, SW137, SW138, SW140, SW141: PB-86-W
SW105, SW106, SW107, SW108, SW109, SW110, SW111, SW112, SW125: PB-86-N
Z101, Z102: 74LS138; DIP-16_W7.62mm_Socket_LongPads
Z103: 74LS74; DIP-14_W7.62mm_Socket_LongPads
Z104, Z105, Z106, Z107, Z111: 74LS374; DIP-20_W7.62mm_Socket_LongPads
Z108, Z109: 74LS244; DIP-20_W7.62mm_Socket_LongPads
Z110: 74LS02; DIP-14_W7.62mm_Socket_LongPads
ZEN101: 1N5339B 5.6V 5W; D_DO-27_P12.70mm_Horizontal

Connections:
5V: BZ1.1 (-), C100.1, C101.2, C102.2, C103.2, C104.2, C105.2, C106.2, C107.2, C108.2, C109.2, C110.2, C111.2, D144.2 (A), JP2.2 (B), P1.1, P2.2, P3.18, P3.19, P3.20, P5.2, R129.1, R130.1, R131.1, R132.1, R133.1, R134.1, R135.1, R136.1, R137.1, SW101.5, SW102.5, SW103.5, SW104.5, SW113.5, SW114.5, SW115.5, SW116.5, SW117.5, SW118.5, SW119.5, SW120.5, SW121.5, SW122.5, SW123.5, SW124.5, SW126.5, SW127.5, SW128.5, SW129.5, SW130.5, SW131.5, SW132.5, SW133.5, SW134.5, SW135.5, SW136.5, SW137.5, SW138.5, SW140.5, SW141.5, Z101.6 (E3), Z101.16 (VCC), Z102.6 (E3), Z102.16 (VCC), Z103.1 (~R), Z103.4 (~S), Z103.13 (~R), Z103.14 (VCC), Z104.20 (VCC), Z105.20 (VCC), Z106.20 (VCC), Z107.20 (VCC), Z108.20 (VCC), Z109.20 (VCC), Z110.14 (VCC), Z111.20 (VCC), ZEN101.1 (K)
/A1: P3.11, P5.4, Z101.1 (A0), Z102.1 (A0)
/A2: P3.12, Z101.2 (A1), Z102.2 (A1)
/A3: P3.13, Z101.3 (A2), Z102.3 (A2)
/BD0: Z104.3 (D0), Z105.3 (D0), Z106.3 (D0), Z107.3 (D0), Z109.18 (O0a), Z111.3 (D0)
/BD1: Z104.4 (D1), Z105.4 (D1), Z106.4 (D1), Z107.4 (D1), Z109.16 (O1a), Z111.4 (D1)
/BD2: Z104.7 (D2), Z105.7 (D2), Z106.7 (D2), Z107.7 (D2), Z109.14 (O2a), Z111.7 (D2)
/BD3: Z104.8 (D3), Z105.8 (D3), Z106.8 (D3), Z107.8 (D3), Z109.12 (O3a), Z111.8 (D3)
/BD4: Z104.13 (D4), Z105.13 (D4), Z106.13 (D4), Z107.13 (D4), Z109.9 (O0b), Z111.13 (D4)
/BD5: Z104.14 (D5), Z105.14 (D5), Z106.14 (D5), Z107.14 (D5), Z109.7 (O1b), Z111.14 (D5)
/BD6: Z104.17 (D6), Z105.17 (D6), Z106.17 (D6), Z107.17 (D6), Z109.5 (O2b), Z111.17 (D6)
/BD7: Z104.18 (D7), Z105.18 (D7), Z106.18 (D7), Z107.18 (D7), Z109.3 (O3b), Z111.18 (D7)
/CLK: P3.9, Z103.3 (C), Z110.2, Z110.3
/CONTRAST: JP3.2 (B), P3.14
/D0: DISP1.7 (DB0), P3.1, P4.7, P5.7, Z108.18 (O0a), Z109.2 (I0a)
/D1: DISP1.8 (DB1), P3.2, P4.8, P5.8, Z108.16 (O1a), Z109.4 (I1a)
/D2: DISP1.9 (DB2), P3.3, P4.9, P5.9, Z108.14 (O2a), Z109.6 (I2a)
/D3: DISP1.10 (DB3), P3.4, P4.10, P5.10, Z108.12 (O3a), Z109.8 (I3a)
/D4: DISP1.11 (DB4), P3.5, P4.11, P5.11, Z108.9 (O0b), Z109.11 (I0b)
/D5: DISP1.12 (DB5), P3.6, P4.12, P5.12, Z108.7 (O1b), Z109.13 (I1b)
/D6: DISP1.13 (DB6), P3.7, P4.13, P5.13, Z108.5 (O2b), Z109.15 (I2b)
/D7: DISP1.14 (DB7), P3.8, P4.14, P5.14, Z108.3 (O3b), Z109.17 (I3b)
/DISPSEL: P3.22, Z103.10 (~S)
/E: P5.6, Z103.8 (~Q), Z110.6
/LED101: R113.2, SW101.6
/LED102: R114.2, SW102.6
/LED103: R116.2, SW103.6
/LED104: R115.2, SW104.6
/LED113: R117.2, SW113.6
/LED114: R118.2, SW114.6
/LED115: R119.2, SW115.6
/LED116: R120.2, SW116.6
/LED117: R125.2, SW117.6
/LED118: R123.2, SW118.6
/LED119: R124.2, SW119.6
/LED120: R122.2, SW120.6
/LED121: R126.2, SW121.6
/LED122: R127.2, SW122.6
/LED123: R128.2, SW123.6
/LED124: R121.2, SW124.6
/LED126: R101.2, SW126.6
/LED127: R102.2, SW127.6
/LED128: R103.2, SW128.6
/LED129: R104.2, SW129.6
/LED130: R105.2, SW130.6
/LED131: R106.2, SW131.6
/LED132: R107.2, SW132.6
/LED133: R108.2, SW133.6
/LED134: R109.2, SW134.6
/LED135: R110.2, SW135.6
/LED136: R111.2, SW136.6
/LED137: R112.2, SW137.6
/LED138: R143.2, SW138.6
/LED140: R141.2, SW140.6
/LED141: R142.2, SW141.6
/R/~W: P5.5, Z110.13
/~BWR: P3.10, Z101.5 (E2), Z103.2 (D), Z110.8, Z110.9
/~LEDSEL: P3.23, Z101.4 (E1)
GND: C100.2, C101.1, C102.1, C103.1, C104.1, C105.1, C106.1, C107.1, C108.1, C109.1, C110.1, C111.1, JP1.2 (B), P1.4, P2.4, P3.15, P3.16, P3.17, P5.1, R138.2, R139.2, Z101.8 (GND), Z102.8 (GND), Z103.7 (GND), Z103.12 (D), Z104.1 (OE), Z104.10 (GND), Z105.1 (OE), Z105.10 (GND), Z106.1 (OE), Z106.10 (GND), Z107.1 (OE), Z107.10 (GND), Z108.10 (GND), Z109.1 (OEa), Z109.10 (GND), Z109.19 (OEb), Z110.7 (GND), Z111.1 (OE), Z111.10 (GND), ZEN101.2 (A)
unnamed: BZ1.2 (+), Z111.2 (O0)
unnamed: D101.2 (A), D109.2 (A), D122.2 (A), D124.2 (A), D130.2 (A), R133.2, Z108.11 (I0b)
unnamed: D101.1 (K), SW101.1
unnamed: D102.2 (A), D110.2 (A), D120.2 (A), D131.2 (A), D138.2 (A), R134.2, Z108.13 (I1b)
unnamed: D102.1 (K), SW102.1
unnamed: D103.2 (A), D112.2 (A), D119.2 (A), D133.2 (A), R136.2, Z108.17 (I3b)
unnamed: D103.1 (K), SW103.1
unnamed: D104.2 (A), D111.2 (A), D118.2 (A), D123.2 (A), D132.2 (A), R135.2, Z108.15 (I2b)
unnamed: D104.1 (K), SW104.1
unnamed: D105.2 (A), D113.2 (A), D125.2 (A), D126.2 (A), D134.2 (A), D140.2 (A), R129.2, Z108.2 (I0a)
unnamed: D105.1 (K), SW105.1
unnamed: D106.2 (A), D114.2 (A), D117.2 (A), D127.2 (A), D135.2 (A), R130.2, Z108.4 (I1a)
unnamed: D106.1 (K), SW106.1
unnamed: D107.2 (A), D115.2 (A), D128.2 (A), D136.2 (A), D141.2 (A), R131.2, Z108.6 (I2a)
unnamed: D107.1 (K), SW107.1
unnamed: D108.2 (A), D116.2 (A), D121.2 (A), D129.2 (A), D137.2 (A), R132.2, Z108.8 (I3a)
unnamed: D108.1 (K), SW108.1
unnamed: D109.1 (K), SW109.1
unnamed: D110.1 (K), SW110.1
unnamed: D111.1 (K), SW111.1
unnamed: D112.1 (K), SW112.1
unnamed: D113.1 (K), SW113.1
unnamed: D114.1 (K), SW114.1
unnamed: D115.1 (K), SW115.1
unnamed: D116.1 (K), SW116.1
unnamed: D117.1 (K), SW117.1
unnamed: D118.1 (K), SW118.1
unnamed: D119.1 (K), SW119.1
unnamed: D120.1 (K), SW120.1
unnamed: D121.1 (K), SW121.1
unnamed: D122.1 (K), SW122.1
unnamed: D123.1 (K), SW123.1
unnamed: D124.1 (K), SW124.1
unnamed: D125.1 (K), SW125.1
unnamed: D126.1 (K), SW126.1
unnamed: D127.1 (K), SW127.1
unnamed: D128.1 (K), SW128.1
unnamed: D129.1 (K), SW129.1
unnamed: D130.1 (K), SW130.1
unnamed: D131.1 (K), SW131.1
unnamed: D132.1 (K), SW132.1
unnamed: D133.1 (K), SW133.1
unnamed: D134.1 (K), SW134.1
unnamed: D135.1 (K), SW135.1
unnamed: D136.1 (K), SW136.1
unnamed: D137.1 (K), SW137.1
unnamed: D138.1 (K), SW138.1
unnamed: D140.1 (K), SW140.1
unnamed: D141.1 (K), SW141.1
unnamed: D144.1 (K), R144.2
unnamed: DISP1.1 (VSS), P4.1
unnamed: DISP1.2 (VDD), P4.2
unnamed: DISP1.3 (VO), P4.3
unnamed: DISP1.4 (RS), P4.4
unnamed: DISP1.5 (R/~W), P4.5
unnamed: DISP1.6 (E), P4.6
unnamed: DISP1.15 (A), P4.15
unnamed: DISP1.16 (K), P4.16
unnamed: JP1.1 (A), P5.16
unnamed: JP2.1 (A), P5.15
unnamed: JP3.1 (A), P5.3
unnamed: P2.1, P3.25, R139.1
unnamed: P2.3, P3.24, R138.1
unnamed: Z101.15 (O0), Z104.11 (Cp)
unnamed: Z101.14 (O1), Z105.11 (Cp)
unnamed: Z101.13 (O2), Z106.11 (Cp)
unnamed: Z101.12 (O3), Z107.11 (Cp)
unnamed: Z101.10 (O5), Z111.11 (Cp)
unnamed: SW126.2, SW127.2, SW128.2, SW129.2, SW130.2, SW131.2, SW132.2, SW133.2, Z102.15 (O0)
unnamed: SW101.2, SW102.2, SW103.2, SW104.2, SW134.2, SW135.2, SW136.2, SW137.2, Z102.14 (O1)
unnamed: SW113.2, SW114.2, SW115.2, SW116.2, SW118.2, SW119.2, SW120.2, SW124.2, Z102.13 (O2)
unnamed: SW117.2, SW121.2, SW122.2, SW123.2, SW138.2, SW140.2, SW141.2, Z102.12 (O3)
unnamed: SW105.2, SW106.2, SW107.2, SW108.2, SW109.2, SW110.2, SW111.2, SW112.2, Z102.11 (O4)
unnamed: SW125.2, Z102.10 (O5)
unnamed: Z103.6 (~Q), Z110.12
unnamed: Z103.11 (C), Z110.4
unnamed: R101.1, Z104.2 (O0)
unnamed: R102.1, Z104.5 (O1)
unnamed: R103.1, Z104.6 (O2)
unnamed: R104.1, Z104.9 (O3)
unnamed: R105.1, Z104.12 (O4)
unnamed: R106.1, Z104.15 (O5)
unnamed: R107.1, Z104.16 (O6)
unnamed: R108.1, Z104.19 (O7)
unnamed: R109.1, Z105.2 (O0)
unnamed: R110.1, Z105.5 (O1)
unnamed: R111.1, Z105.6 (O2)
unnamed: R112.1, Z105.9 (O3)
unnamed: R113.1, Z105.12 (O4)
unnamed: R114.1, Z105.15 (O5)
unnamed: R115.1, Z105.16 (O6)
unnamed: R116.1, Z105.19 (O7)
unnamed: R117.1, Z106.2 (O0)
unnamed: R118.1, Z106.5 (O1)
unnamed: R119.1, Z106.6 (O2)
unnamed: R120.1, Z106.9 (O3)
unnamed: R121.1, Z106.12 (O4)
unnamed: R122.1, Z106.15 (O5)
unnamed: R123.1, Z106.16 (O6)
unnamed: R124.1, Z106.19 (O7)
unnamed: R141.1, Z107.2 (O0)
unnamed: R125.1, Z107.5 (O1)
unnamed: R142.1, Z107.6 (O2)
unnamed: R126.1, Z107.9 (O3)
unnamed: R127.1, Z107.12 (O4)
unnamed: R143.1, Z107.15 (O5)
unnamed: R128.1, Z107.16 (O6)
unnamed: R144.1, Z107.19 (O7)
unnamed: Z110.1, Z110.5
unnamed: Z110.10, Z110.11
~BUTSEL: P3.21, R137.2, Z102.4 (E1), Z102.5 (E2), Z108.1 (OEa), Z108.19 (OEb)

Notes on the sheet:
Typical wiring shown Note: GND is available on the connector if an encoder module with debounce circuitry is used
IMPORTANT NOTE! Zyklus pin layout for connector P3 is different to the standardised layout shown here. Do not connect to an original Zyklus without an adapter board inbetween!
NOTE: ADDRESSING OF LEDS TO SWITCHES IS UNCLEAR IN ORIGINAL SCHEMATICS! USED PHOTOS OF ORIGINAL PCB TO IDENTIFY RESISTORS TO NEARBY SWITCHES

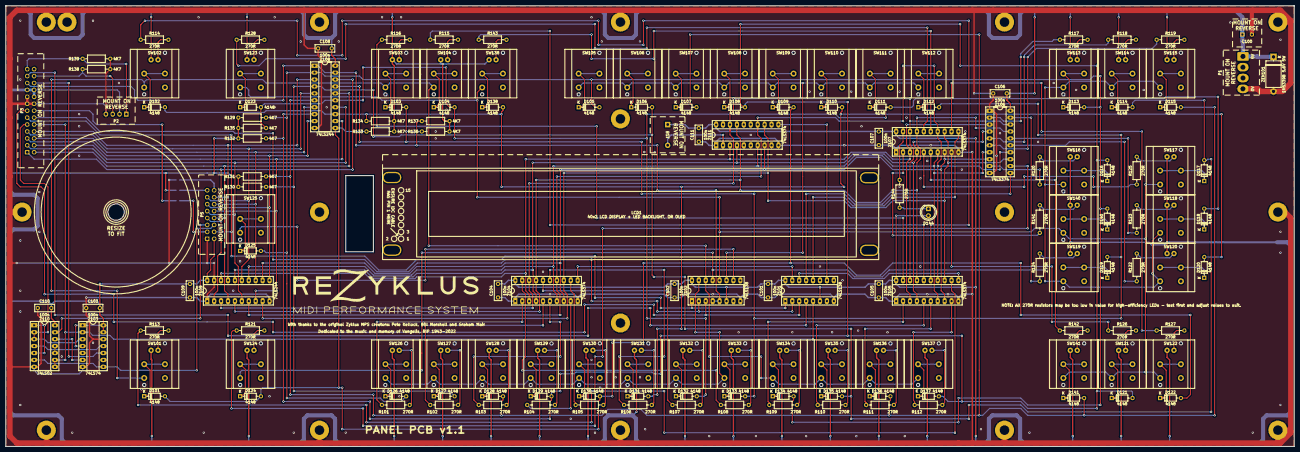
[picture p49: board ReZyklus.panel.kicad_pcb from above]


Board: 2 copper layers, 472.7 x 161.7 mm, 157 parts (9 on the bottom side), 162 nets.

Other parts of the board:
LCD1: 40x2 LCD DISPLAY + LED BACKLIGHT, OR OLED; 40x2_LCD_Type1

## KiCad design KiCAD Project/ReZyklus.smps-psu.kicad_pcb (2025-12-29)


Board: 2 copper layers, 129.3 x 123.2 mm, 11 parts (0 on the bottom side), 6 nets.

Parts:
CON201: 5W HDR; Molex_KK-396_5273-06A_1x06_P3.96mm_Vertical
CON202, CON203: 4w Molex; Molex_KK-396_5273-04A_1x04_P3.96mm_Vertical
DCM1: DC-DC Boost Converter Module; LM2596_DC-DC_Converter_Module
F202: 2A; Fuseholder_Cylinder-5x20mm_Stelvio-Kontek_PTF78_Horizontal_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
REF1, REF2, REF3, REF4, REF5: MountingHole_3.5mm_Pad
SMPS1: XP Power LCW15US05 5V 3A SMPS; XPPower-LCW15US05_5V_3A_SMPS

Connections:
/+5.6V: CON202.2, CON203.2, DCM1.3 (OUT+)
/+5V: CON202.1, CON203.1, DCM1.1 (IN+), F202.2
/AC-L: CON201.2, SMPS1.1 (AC(L))
/AC-N: CON201.5, SMPS1.2 (AC(N))
GND: CON201.3, CON201.6, CON202.4, CON203.4, DCM1.2 (IN-), DCM1.4 (OUT-), SMPS1.3 (EARTH), SMPS1.4 (-Vout)
unnamed: F202.1, SMPS1.5 (+Vout)

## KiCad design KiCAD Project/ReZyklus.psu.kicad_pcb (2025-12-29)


Board: 2 copper layers, 129.3 x 123.2 mm, 25 parts (0 on the bottom side), 12 nets.

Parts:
C201, C202, C203: 4700uF 16V; CP_Axial_L46.0mm_D20.0mm_P52.00mm_Horizontal
C204, C205: 47n; C_Rect_L7.2mm_W2.5mm_P5.00mm_FKS2_FKP2_MKS2_MKP2
C206: 1uF 16V; CP_Radial_D5.0mm_P2.50mm
CON201: 5W HDR; Molex_KK-396_5273-06A_1x06_P3.96mm_Vertical
CON202, CON203: 4w Molex; Molex_KK-396_5273-04A_1x04_P3.96mm_Vertical
D201, D202, D203, D204: 1N5401; D_DO-201AD_P15.24mm_Horizontal
D205: 1N4001; D_DO-15_P10.16mm_Horizontal
F202: 2A; Fuseholder_Cylinder-5x20mm_Stelvio-Kontek_PTF78_Horizontal_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
R201: 1K0; R_Axial_DIN0207_L6.3mm_D2.5mm_P10.16mm_Horizontal
R202: 33R 5W; R_Axial_Power_L20.0mm_W6.4mm_P25.40mm
REF1, REF2, REF3, REF4, REF5: MountingHole_3.5mm_Pad
REG201: 78S05; TO-220-3_Vertical
TR1: MYRRA 45062 2x9V 30VA; Myrra_450xx_Transformer
ZEN201: 1N5339B 5.6V 5W; D_DO-15_P12.70mm_Horizontal

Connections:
/+5.6V: C203.1, CON202.2, CON203.2, R202.1, ZEN201.1 (K)
/+5V: C205.1, CON202.1, CON203.1, R201.1, REG201.3 (OUT)
GND: C201.2, C202.2, C203.2, C204.2, C205.2, C206.2, CON201.3, CON201.6, CON202.4, CON203.4, D203.2 (A), D204.2 (A), R201.2, REG201.2 (GND), ZEN201.2 (A)
unnamed: CON201.1, TR1.1
unnamed: CON201.2, TR1.4
unnamed: CON201.4, TR1.6
unnamed: CON201.5, TR1.9
unnamed: D201.2 (A), D203.1 (K), TR1.12, TR1.19
unnamed: C201.1, C202.1, C204.1, D201.1 (K), D202.1 (K), F202.1
unnamed: D202.2 (A), D204.1 (K), TR1.14, TR1.17
unnamed: C206.1, D205.2 (A), F202.2, REG201.1 (IN)
unnamed: D205.1 (K), R202.2

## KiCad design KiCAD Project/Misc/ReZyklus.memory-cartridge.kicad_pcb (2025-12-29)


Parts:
C1, C2, C3: 100n; C_1206_3216Metric
C4: 10uF 16V; CP_Elec_5x5.8
D1: 1N4001; D_SMA
D2: 5.6V; D_SOD-323_HandSoldering
J1: DC37_Receptacle; DSUB-37_Female_Horizontal_P2.77x2.84mm_EdgePinOffset7.70mm_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
R1, R2, R3, R4, R5, R6: 4M7; R_1206_3216Metric
TP1: +5V; TestPoint_THTPad_1.5x1.5mm_Drill0.7mm
TP2: GND; TestPoint_THTPad_1.5x1.5mm_Drill0.7mm
TP3: ~{CBBWR}; TestPoint_THTPad_1.5x1.5mm_Drill0.7mm
TP4: ~{CRD}; TestPoint_THTPad_1.5x1.5mm_Drill0.7mm
TP5: BBON; TestPoint_THTPad_1.5x1.5mm_Drill0.7mm
TP6: ~{BBON}; TestPoint_THTPad_1.5x1.5mm_Drill0.7mm
TP7: ~{BBSEL5}; TestPoint_THTPad_1.5x1.5mm_Drill0.7mm
TP8: ~{BBSEL6}; TestPoint_THTPad_1.5x1.5mm_Drill0.7mm
TP9: ~{BBSEL7}; TestPoint_THTPad_1.5x1.5mm_Drill0.7mm
TP10: ~{BBSEL8}; TestPoint_THTPad_1.5x1.5mm_Drill0.7mm
TP11: A0; TestPoint_THTPad_1.5x1.5mm_Drill0.7mm
TP12: A1; TestPoint_THTPad_1.5x1.5mm_Drill0.7mm
TP13: A2; TestPoint_THTPad_1.5x1.5mm_Drill0.7mm
TP14: A3; TestPoint_THTPad_1.5x1.5mm_Drill0.7mm
TP15: A4; TestPoint_THTPad_1.5x1.5mm_Drill0.7mm
TP16: A5; TestPoint_THTPad_1.5x1.5mm_Drill0.7mm
TP17: A6; TestPoint_THTPad_1.5x1.5mm_Drill0.7mm
TP18: A7; TestPoint_THTPad_1.5x1.5mm_Drill0.7mm
TP19: A8; TestPoint_THTPad_1.5x1.5mm_Drill0.7mm
TP20: A9; TestPoint_THTPad_1.5x1.5mm_Drill0.7mm
TP21: A10; TestPoint_THTPad_1.5x1.5mm_Drill0.7mm
TP22: A11; TestPoint_THTPad_1.5x1.5mm_Drill0.7mm
TP23: A12; TestPoint_THTPad_1.5x1.5mm_Drill0.7mm
TP24: A13; TestPoint_THTPad_1.5x1.5mm_Drill0.7mm
TP25: A14; TestPoint_THTPad_1.5x1.5mm_Drill0.7mm
TP26: D0; TestPoint_THTPad_1.5x1.5mm_Drill0.7mm
TP27: D1; TestPoint_THTPad_1.5x1.5mm_Drill0.7mm
TP28: D2; TestPoint_THTPad_1.5x1.5mm_Drill0.7mm
TP29: D3; TestPoint_THTPad_1.5x1.5mm_Drill0.7mm
TP30: D4; TestPoint_THTPad_1.5x1.5mm_Drill0.7mm
TP31: D5; TestPoint_THTPad_1.5x1.5mm_Drill0.7mm
TP32: D6; TestPoint_THTPad_1.5x1.5mm_Drill0.7mm
TP33: D7; TestPoint_THTPad_1.5x1.5mm_Drill0.7mm
U1: FM1808B-SG; SOIC-28W_7.5x17.9mm_P1.27mm
U2: SN74LVC1G14DBV; SOT-23-5
U3: 74LS148; SOIC-16_4.55x10.3mm_P1.27mm

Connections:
+5V: C1.2, C2.2, C3.2, C4.1, D1.1 (K), R2.1, R3.1, R4.1, R5.1, R6.1, TP1.1, U1.28 (VDD), U2.5 (VCC), U3.1 (I4), U3.2 (I5), U3.3 (I6), U3.4 (I7), U3.16 (VCC)
/A0: J1.5, TP11.1, U1.10 (A0)
/A1: J1.6, TP12.1, U1.9 (A1)
/A2: J1.7, TP13.1, U1.8 (A2)
/A3: J1.8, TP14.1, U1.7 (A3)
/A4: J1.9, TP15.1, U1.6 (A4)
/A5: J1.10, TP16.1, U1.5 (A5)
/A6: J1.11, TP17.1, U1.4 (A6)
/A7: J1.12, TP18.1, U1.3 (A7)
/A8: J1.30, TP19.1, U1.25 (A8)
/A9: J1.29, TP20.1, U1.24 (A9)
/A10: J1.26, TP21.1, U1.21 (A10)
/A11: J1.28, TP22.1, U1.23 (A11)
/A12: J1.13, TP23.1, U1.2 (A12)
/A13: TP24.1, U1.26 (A13), U3.9 (S0)
/A14: TP25.1, U1.1 (A14), U3.7 (S1)
/BBON: J1.31, R1.1, TP5.1, U2.2
/D0: J1.4, TP26.1, U1.11 (DQ0)
/D1: J1.3, TP27.1, U1.12 (DQ1)
/D2: J1.2, TP28.1, U1.13 (DQ2)
/D3: J1.20, TP29.1, U1.15 (DQ3)
/D4: J1.21, TP30.1, U1.16 (DQ4)
/D5: J1.22, TP31.1, U1.17 (DQ5)
/D6: J1.23, TP32.1, U1.18 (DQ6)
/D7: J1.24, TP33.1, U1.19 (DQ7)
/~BBSEL5: J1.32, R3.2, TP7.1, U3.10 (IO)
/~BBSEL6: J1.14, R4.2, TP8.1, U3.11 (I1)
/~BBSEL7: J1.33, R5.2, TP9.1, U3.12 (I2)
/~BBSEL8: J1.15, R6.2, TP10.1, U3.13 (I3)
/~CBBWR: J1.34, R2.2, TP3.1, U1.27 (~WE)
/~CRD: J1.27, TP4.1, U1.22 (~OE)
GND: C1.1, C2.1, C3.1, C4.2, D2.2 (A), J1.1, J1.17, J1.36, R1.2, TP2.1, U1.14 (VSS), U2.3 (GND), U3.5 (EI), U3.8 (GND)
unnamed: D1.2 (A), D2.1 (K), J1.16, J1.35
unnamed: TP6.1, U1.20 (~CE), U2.4

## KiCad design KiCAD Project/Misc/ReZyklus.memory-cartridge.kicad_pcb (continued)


Board: 2 copper layers, 73.7 x 45.1 mm, 49 parts (0 on the bottom side), 34 nets.
